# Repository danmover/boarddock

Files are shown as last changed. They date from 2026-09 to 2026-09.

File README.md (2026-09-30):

# BoardDock

**Dock any PCB. No screws. No supports.**

BoardDock turns a board's design files, or a few measurements, into 3D-printable holders that dock onto TS35 DIN rails with every plug reachable. It lays out the rails, routes and sizes the cables between the boards, checks the springs, and packs the parts onto print plates for your printer. It runs in the browser or as a desktop app for Windows, macOS and Linux. It is open source (MIT), and all sizes are in mm.

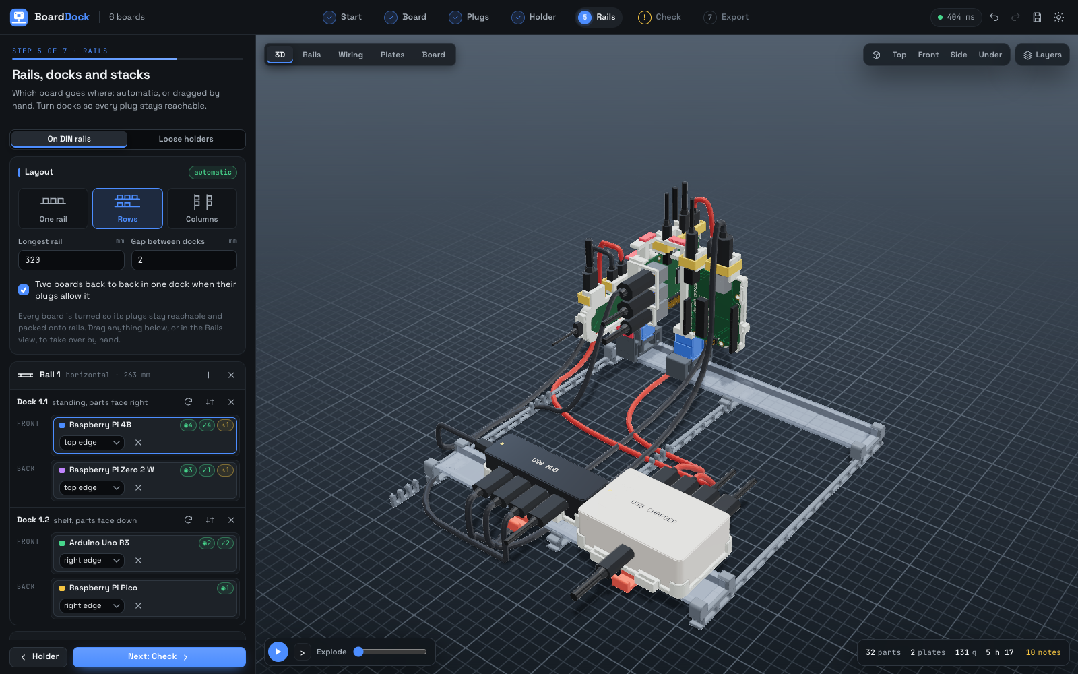
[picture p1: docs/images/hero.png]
A panel of boards on a DIN rail


## Status

One rack has been printed so far, from 3.0.0. The DIN rail clip worked. The rest showed what to fix: the release button's tunnel was too tight and the button broke, the snap pins broke, the socket latch let a holder pop out (the model has it slipping at about 10 N), and the tongue stoppers snapped.

3.1.0 redesigns those parts:
- boards are held by spring clips only, with fixed ledges and hairpin clips; there are no snap pins;
- the socket latch has a hook undercut 15°, so a pull draws it in;
- the release rod's tunnel has 0.8 mm of play and a gate the rod clicks under;
- two crush ribs on the tongue replace the stoppers;
- cable tags are held on by zip ties, and back-to-back holders by a pin and a U clip.

Nothing from 3.1 has been reprinted yet, so every number comes from models. Print the test-fit kit first, and read [the known limits](docs/limits.md).

## Download

- **Web app:** [danmover.github.io/boarddock](https://danmover.github.io/boarddock). Nothing is uploaded: it all runs in your browser.
- **Desktop app:** from [Releases](https://github.com/danmover/boarddock/releases). The builds are not code-signed yet, so your system asks you to confirm the first time.
- **From source:** `npm install`, then `npm run dev` (see [Development](#development)).

| System | File | First time |
|---|---|---|
| **Windows** | `BoardDock-3.1.1-win-x64-setup.exe` (installer) or `BoardDock-3.1.1-win-x64-portable.exe` (no install) | Choose **More info › Run anyway**. |
| **macOS** (Apple Silicon) | `BoardDock-3.1.1-mac-arm64.dmg` (open it and drag BoardDock into Applications), or `BoardDock-3.1.1-mac-arm64.zip` | Right-click the app and choose **Open**. |
| **Linux** | `BoardDock-3.1.1-linux-x86_64.AppImage` (`chmod +x` it, then run it) or `BoardDock-3.1.1-linux-amd64.deb` (`sudo apt install ./BoardDock-3.1.1-linux-amd64.deb`) | Nothing. |

The desktop app does two things the browser can't: it opens Cadence Allegro `.brd` boards (with KiCad 10 or newer installed, free from kicad.org), and **Open plate** hands a print plate to a slicer you have installed.

## Quick start

You need a 3D printer and a length of TS35 DIN rail (the 35 mm metal top-hat rail from electrical cabinets, cut with a hacksaw). Or pick **Loose holders** in the Rails step and skip the rail.

1. **Start.** Drop your board's files (several at once is fine), choose **Draw your own**, or **Open a saved rack**. Pick **Your printer** above them. Click a board in the library below to add it, or press **+ Board** (or **A**) from any step. The **cluster** preset adds a Pi cluster with its switch, powerboard and supplies.
2. **Board.** Check the outline, the parts and the hole wizard. Fix anything in the board editor.
3. **Plugs.** Press **Auto-connect** to cable the rack. Tap a port's *empty* or *cable* tag to say whether you'll plug something into it yourself.
4. **Holder.** Choose a frame or a tray, a preset, and **Firm** or **Gentle** spring clips.
5. **Rails.** Every board is already on a rail. Drag, turn, pair or stack boards if you like, and lock what you want to keep.
6. **Check.** Failing checks come first, each with **Show in 3D**. Press **Run dock FEA** for your material.
7. **Export.** First print the **Test-fit kit · print this first**: a rail shoe, a socket and a tongue key with its release rod (30 to 40 minutes). Clip the shoe on your rail, push the key in until it clicks, then press its button and lift. If the key is tight, raise **Tongue fit (looser +)** under Rails › **Fit and spacing** by 0.05 to 0.1 mm. Then print the plates in PETG with no supports, or slice them in the app. The shopping list, the **Bill of materials** and the **Checklist** say what to buy and have to hand.
8. **Build it**, following the play button or **Guide** in the 3D view. Then press **Mark the rack as built** in Export.

Every step has **Back** and **Next** at the foot of the sidebar. The full walk-through is in [docs/guide.md](docs/guide.md), and printing is in [docs/printing.md](docs/printing.md).

## What it does

- **Boards.** Read a board from its design files, draw one, or pick one from the library. The board editor has a toolbox of plugs and parts, a measure tool and a photo underlay, and the hole wizard sorts every hole into mounting holes, connector pegs, part leads and standoffs. [More](docs/guide.md#the-board-editor)
- **The dock.** A rail shoe clips onto the rail; press its red lever down to lift it off. A socket snaps into the shoe in any of four turns and takes two holders back to back. The holder's tongue has two crush ribs, and a latch with an undercut hook holds it. The button on top of the holder is the head of a release rod that opens the latch. [More](docs/design.md#the-dock)
- **Holders.** A light frame (or a full tray) round each board, held by spring clips only: tapered leaves, hairpins on short stretches of edge, and a fixed ledge where plugs take most of the edges. A mounting hole gets at most a locating pin. Only the ports you use get a plug cradle, cap, guard or zip-tie anchor; the rest keep a bare opening. [More](docs/design.md#the-holder)
- **Layout.** Auto-arrange places every board for plug access and short cables: back to back, standing up or lying flat, and stacked (a HAT bolted on standoffs, a board on a printed layer, or small boards in a column on their long edges). A board below the top of a column stands with its plugs to the side; one that can't gets a **Plug up the column** check. Lock what you have placed, and automatic changes leave it alone. [More](docs/guide.md#the-rails-step)
- **Boxes, power and cables.** USB hubs, chargers, network and PoE switches, powerboards and plug packs are boxes with ports. **Auto-connect** cables the rack, every cable is routed clear of the parts and sized to a length you can buy, a power budget checks every supply, and numbered cable tags go on with 2.5 mm zip ties. [More](docs/guide.md#cables-and-the-wiring-view)
- **Stands.** Printed table stands hold the rails, with no screws. To hang a rack on a wall, screw the rails up yourself and clip the docks on. [More](docs/design.md#table-stands)
- **Checks.** Hand sums for the clips, caps, tongue and stands, 2D FEA of the dock's springs, and a layer-by-layer printability check of every part. [More](docs/design.md#checks-fea-and-printability)
- **Printing.** Parts are packed onto as few plates as your printer's bed allows, already in print orientation, as STL or 3MF, or sliced to G-code in the app. [More](docs/printing.md)
- **Coming back later.** Add a board to a built rack, and Export lists only the new parts, cables and rails. [More](docs/guide.md#coming-back-to-add-a-board)

## Supported files

KiCad; Altium through STEP or fab files; Eagle (XML and old binary boards); Cadence Allegro `.brd` in the desktop app, through KiCad 10; board-viewer files; IDF; DXF; Gerber with drill and pick-and-place; IPC-2581, ODB++ and GenCAD. Or draw a board, start from a template, or pick one from the library. Details are in [docs/files.md](docs/files.md).

## Documentation

| Page | What is in it |
|---|---|
| [docs/guide.md](docs/guide.md) | Using BoardDock, step by step: the board editor, plugs, holders, rails, stacks, boxes and power, cables, the 3D view, and adding to a built rack |
| [docs/design.md](docs/design.md) | How the printed parts work: the dock, holders and clips, stacks, table stands, cable routing, and the checks and FEA |
| [docs/printing.md](docs/printing.md) | Printing and export: the test-fit kit, material, printers, print settings and G-code |
| [docs/files.md](docs/files.md) | Supported files, and how connectors are recognised |
| [docs/limits.md](docs/limits.md) | Honest limits: what is untested or approximate |
| [docs/development.md](docs/development.md) | Commands, the collision test, tile pictures and the project layout |
| [docs/din-clip-review.md](docs/din-clip-review.md) | The DIN rail clip review, and what the first print showed |
| [boards/README.md](boards/README.md) | Adding a board to the library |
| [parts/README.md](parts/README.md) | Teaching BoardDock a connector |
| [CONTRIBUTING.md](CONTRIBUTING.md) | Reporting a bad import, code conventions and releases |
| [TODO.md](TODO.md) | What is still to do, in order |

## Adding boards and parts

Two folders take contributions by pull request, each checked by one command:

- **`boards/`** adds a board to the library, under **Community boards**. Put its files in `boards/<slug>/` with a small `board.json` saying who made it and on what terms, then run `npm run boards -- <slug>`. Guide: [boards/README.md](boards/README.md).
- **`parts/`** teaches BoardDock a connector with one small JSON file: `names-….json` maps part numbers or footprint names to a type it has (this fixes a `NOT IDENTIFIED`), and `type-<id>.json` adds a new connector type. Then run `npm run parts`. Guide: [parts/README.md](parts/README.md).

[CONTRIBUTING.md](CONTRIBUTING.md) has the rest. A maintainer can also add the `boards` or `parts` label to a pull request, and an optional Claude job does the work on its branch ([docs/files.md](docs/files.md#adding-boards-and-parts) has the details).

## Development

```bash
npm install
npm run dev          # web app at http://localhost:5173
npm test             # vitest: importers, holders, panels, dock FEA, and a quick collision check
npm run typecheck
npm run collisions   # the whole collision test (144 racks, a minute or two)
npm run boards       # community boards: read boards/<slug>/, update public/boards/
npm run parts        # contributed parts: check parts/*.json, write src/model/parts.json
npm run build        # production web build in dist/
npm run desktop      # Electron app from the build
npm run dist         # installers for the current OS in release/
```

The collision test, the tile pictures and the project layout are in [docs/development.md](docs/development.md). Code conventions and releases are in [CONTRIBUTING.md](CONTRIBUTING.md), and what is still to do is in [TODO.md](TODO.md).

## Licence

MIT for BoardDock itself; see [LICENSE](LICENSE). Third-party components and their licences are listed in [NOTICE](NOTICE).

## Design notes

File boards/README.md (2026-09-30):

# Community boards

Boards added here appear in BoardDock's library (Start page and **Add a board**, under **Community boards**, after the built-in ones), so anyone can add yours to a rack without drawing it.

## What to upload

One folder per board, `boards/<slug>/`. The slug is the board's id: lower case, digits and dashes (`acme-sensor-v2`). It holds:

1. **Your board's files.** One is enough; BoardDock reads the one that tells it most.

   | You have | Upload |
   |---|---|
   | KiCad | the `.kicad_pcb` (best: outline, holes, part sizes, pin names) |
   | Allegro / OrCAD | open it in KiCad 10 (File > Import > Non-KiCad Board File), save, and upload the `.kicad_pcb` |
   | Altium, PADS, Xpedition, others | IPC-2581 `.xml`, or ODB++ (`.tgz` or the job folder), or GenCAD `.cad`, or IDF `.emn` + `.emp`, or Gerbers (outline layer) + NC drill + pick and place |
   | Eagle / Fusion | the `.brd` |
   | only a drawing | a `.dxf` of the outline (holes from round cut-outs) |

   A STEP file works in the app but not in `npm run boards` (it needs a browser): add one of the above too.
2. **`board.json`**, a few lines about the board (below).

Only upload what you may share. Say in `board.json` where it comes from and under what terms.

## board.json

```json
{
  "name": "Sensor board with JTAG (worked example)",
  "maker": "BoardDock contributors",
  "url": "https://github.com/danmover/boarddock/tree/main/examples",
  "license": "MIT",
  "source": "A made-up board that ships with BoardDock."
}
```

`name`, `maker`, `url`, `license` and `source` (a note on where the files came from) are shown with the board. Give `license` or `source`, and `maker` or `url`. Everything else is a hint, only for when the report (below) says something is wrong:

```json
{
  "parts":      { "J3": { "type": "usb_c" }, "J7": { "type": "custom", "note": "Wurth 61300811121" } },
  "footprints": { "USB_C_Receptacle": "usb_c" },
  "holes":      { "use": [[3.5, 3.5], [66.5, 3.5], [10, 40, 3.2]], "ignore": [[35, 20]] }
}
```

| Hint | Meaning |
|---|---|
| `parts.<ref>.type` | what part `<ref>` really is: a connector id (`npm run boards -- --types` lists them), `none` (not a connector), or `custom` (a plug the library has no entry for: put its part number in `note`) |
| `parts.<ref>.angle`, `.size`, `.hide` | which way its plug comes out (0 right, 90 top, 180 left, -90 bottom; found from the nearest edge if left out), its `[width, depth, height]` in mm, or leave it out |
| `footprints.<regex>` | the same connector id for every part whose footprint name matches |
| `holes.use` | exactly these are the mounting holes, as `[x, y]` or `[x, y, diameter]` (one the file lacks is added); positions are the ones the report prints, in mm from the board's lower left |
| `holes.ignore` | holes to leave alone |
| `thickness`, `notes`, `files`, `copper`, `listed` | board thickness in mm, extra notes for the app, which files to read, keep the copper tracks (bigger file), `false` to keep it out of the app |

## Turn the files into a board

```bash
npm ci                          # once
npm run boards -- <slug>        # read boards/<slug>/, print the report, update public/boards/
npm run boards                  # the same for every folder
```

The report is what you check, for the worked example, `boards/example-sensor-jtag/`:

```
boards/example-sensor-jtag: Sensor board with JTAG (worked example) (KiCad: sensor-jtag.kicad_pcb)
  outline     70 x 45 mm, 4 corners, 0 cut-outs, 1.6 mm thick
  holes       4 found, 4 to mount by
    (3.50, 41.50)    d3.20  mount    Ø3.2 near a corner: a mounting hole
    ...
  connectors  3
    J1       usb_micro_b  edge -180° by name        USB_Micro-B_Molex-105017-0001
    J2       jtag20       top       by name        IDC-Header_2x10_P2.54mm_Vertical
    J3       header       top       by name        PinHeader_1x04_P2.54mm_Vertical
  result      ok
```

Does the outline match your board? Are the mounting holes the right ones, and no others? Is every plug the right kind (a `NOT IDENTIFIED` one is a **Custom** connector: fix it with a `parts` hint)? Fix, run again, until it says `ok` with no `WARNING` lines. The script exits with an error (and writes nothing) only when a board can't be read or `board.json` is wrong. `--dry` only reports, `--strict` also fails on warnings, `--check` fails when `public/boards/` is out of date.

Then `npx vitest run tests/boards.test.ts`, commit `boards/<slug>/` and `public/boards/`, and open a pull request. Two pull requests adding boards can conflict in `public/boards/index.json`: take either side and run `npm run boards` again.

## Don't want to run anything?

Open the pull request with just the folder (files and `board.json`, or the files alone). CI (`.github/workflows/boards.yml`) runs the script on it and shows the report. If the repository has an `ANTHROPIC_API_KEY` secret, a maintainer adds the **`boards`** label and an AI job follows [`AGENTS.md`](AGENTS.md) on the PR branch: it writes the hints, regenerates `public/boards/` and commits. It only runs for branches of this repository, only when that label is added (not on every push), and does nothing in forks without the secret. For a PR from a fork, a maintainer can push its branch here first, or run the steps of `AGENTS.md` locally.

## Pictures

A board without a picture shows a plain top view, so this is optional. Maintainers can render 3D pictures of all boards that lack one (needs the dev server and Playwright, see the top of `scripts/render-tiles.mjs`): `node scripts/render-tiles.mjs http://localhost:5173/ community`, then `npm run boards`.

## How it fits together

`boards/<slug>/` (source of truth) -> `npm run boards` (`scripts/boards.mjs` and `scripts/boards-lib.ts`, using the app's own importers, so what the report says is what the app would read) -> `public/boards/index.json` (one row per board) and `public/boards/<slug>.json` (the board). The app fetches `index.json` only when the library opens and a board's file only when you add it: none of it is in the main JavaScript.

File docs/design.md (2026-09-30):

# How the printed parts work

What BoardDock prints, why it is shaped that way, and how it is checked. For using the app, see [guide.md](guide.md); for printing, [printing.md](printing.md); for what is untested, [limits.md](limits.md). Back to the [README](../README.md).

Contents:
- [The dock](#the-dock)
- [The holder](#the-holder)
- [How the board is held](#how-the-board-is-held)
- [Plug cradles and caps](#plug-cradles-and-caps)
- [Stacks and columns](#stacks-and-columns)
- [Table stands](#table-stands)
- [Cable routing](#cable-routing)
- [Loose-holder joints](#loose-holder-joints)
- [Checks, FEA and printability](#checks-fea-and-printability)

Every figure here is from the model: exact geometry, hand sums, and a 2D FEA with a textbook modulus. One rack was printed from 3.0.0; nothing from 3.1.0 has been printed yet.

## The dock

Every board sits in a holder that plugs into a dock on the rail. This is the screwless "DIN hub" design, built into the generator:

| Part | What it does | Prints |
|---|---|---|
| **Rail shoe** (graphite, red lever) | Clips onto a TS35 rail. Its jaw wraps round the rail flange and hangs from a hinge leaf directly **above** the lip, so pulling the dock straight up can't pry it open. A sprung **rail grip** in the rail's channel presses the rail's wall and holds the shoe against its fixed hook, so a dock stays where you put it: about 6 N pushes one along the rail. The release lever is printed in place on a pin, with a bead round the pin's middle so it can't slide off; a built-in stop protects the hinge. The lever goes on whichever side of the rail has more room; you can flip it per dock. | on its end face, lever and all |
| **Socket** (blue) | Snaps into the shoe in any of four 90° turns and takes two holders back to back. It has two print-in-place latches: long tapered springs whose hooks are undercut 15°, so pulling on a holder draws the hook in rather than out. | on its end face |
| **Holder** | The frame (or tray) round your board, with a tongue on its dock edge and a spine that carries the release rod. | flat on its back |
| **Release rod** (red) | Its head is the **button on the holder's top edge**: a keycap with a thumb dish and chevrons that point the way it moves. Press it and the rod's 45° foot wedges the latch open; the latch spring returns it. The grip bar under your fingers has a matching finger scoop. | flat |

**The tongue** is 14 × 4.5 mm at the socket mouth and a slip fit: 0.2 mm a side, 0.14 to 0.2 mm front and back, and 0.65 mm of lift on purpose, for the undercut hook. Two **crush ribs** on its front corner faces stand 0.4 mm proud and are pressed 0.12 mm. They are meant to deform once, on the first push in (about 24 N, once; the crush stress is assumed, not measured), so the holder is then snug and centred. They replace 3.0.0's tongue stoppers, which snapped.

**The latch** reaches 1.4 mm into a groove across the tongue's front face, and its holding face slopes 15°. A pull on the holder tips the beam, and the undercut draws the nose back in: a 20 N pull moves it 0.4 mm of its 1.4 mm, and it slips only at about 69 N (friction not counted). It takes about 3.9 N to push a holder in and 2.5 N on the button, at 0.85% strain. There is no stop post: the button's stroke bounds the arm.

**The rod's tunnel** has 0.8 mm of play round the rod (0.4 mm each side), a 45° lead-in funnel and chamfers, and the rod's neck under the button is solid and filleted, so it slides in without forcing (3.0.0's tunnel was tight and the button broke). Push the rod in until it clicks: two barbed fingers spring out under a gate at the top of the tunnel (0.3 mm each side), once, so it can't slide back out.

**Using it:**
1. Hook the shoe under the rail and press it down until it clicks. To move it along the rail, push it firmly.
2. Press the socket in, in whichever turn you want.
3. Push the holder straight down into the socket until the latch clicks.
4. **To take a board out:** put your thumb on the red button and two fingers under the grip bar, squeeze, and lift.
5. **To take a dock off the rail:** lift the boards out, press the ridged red pad beside the socket down about 5 mm, and lift the dock off.

Where the button goes (**Centred**, **Beside the board** or **Automatic**) is set in the Holder step; see [guide.md](guide.md#the-holder-step).

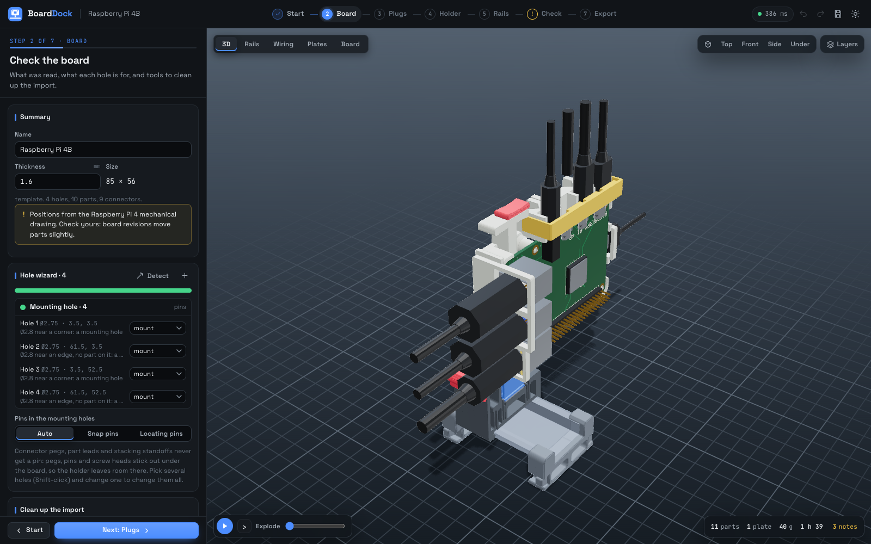
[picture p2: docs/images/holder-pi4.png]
A Raspberry Pi 4 docked


*(This picture predates 3.1.0: its holder still has pins in the mounting holes.)*

### Lying flat

A board can also lie flat on its dock, top face up (out of the wall), on the same shoe and socket:
- Its holder has a tab, the **ear**, on one edge, flush with its underside, so the holder prints base-down like any other. The ear goes on an edge where it keeps clear of the plugs, as near the middle as it can.
- The tongue that plugs into the socket is a small **dock key** of its own, with a dovetail on top. It prints on its side, slides into a dovetail groove under the ear from the ear's tip, and the release rod locks it in: the rod goes in from the top, through the ear and the key, down to the latch, and clicks in under a ledge at the top of the ear, so neither can slide out.
- The release button sits on top of the ear, clear of the board. Put your thumb on the button and your fingers under the ear, then squeeze and lift.
- Two boards can lie back to back in one socket, ears together. A J-Link or serial adapter can stand in the other half of a flat board's socket. The shoe's lever goes on the side away from a flat board where it can.

Check lists the tongue's stress under a 20 N press on the far side of a flat holder (the same load case as a push on a standing holder's far edge). No flat holder has been printed yet.

## The holder

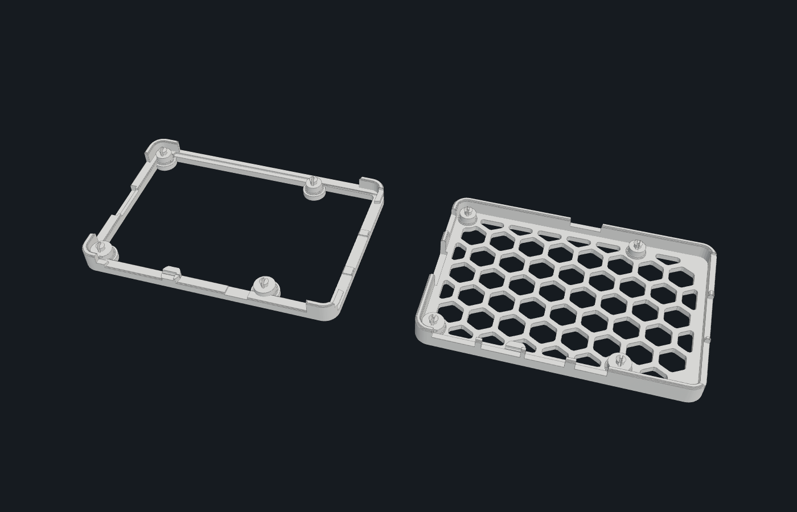
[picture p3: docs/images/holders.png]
Frame and tray holders


*(This picture predates 3.1.0: it shows split snap pins, which are gone, and no spring clips.)*

**Frame** (the default) combines the lean spine-and-rib carrier of the original DIN hub with the tray's protection:
- a rim runs round the board, under its edge and out to the holder's outline;
- short corner guards locate the board, and **edge seats** carry it wherever no pin is close;
- ribs, laid out as a minimum spanning tree, tie every pin to the rim or to the dock's spine;
- plug cradles, caps, guards, tie anchors, spring clips and the label each bring only the bit of wall they need.

**Tray** is the full base with a hex pattern and a wall all round: stiffer, and more plastic. A frame is open underneath (push the board out from below); a tray has finger notches.

Plastic in a loose holder with its clips, but no cradles, caps, guards, anchors or label (PETG, default settings):

| Board | Frame | Tray |
|---|---|---|
| Raspberry Pi 4 | 4.5 cm³ | 7.6 cm³ |
| Arduino Uno | 4.3 cm³ | 6.9 cm³ |
| Perfboard 50 × 70 | 3.8 cm³ | 6.4 cm³ |
| 60 × 40 blank | 4.3 cm³ | 5.5 cm³ |

So a frame takes about 20 to 40% less plastic than a tray. Cradles, caps and the dock tongue come on top and are the same for both styles.

## How the board is held

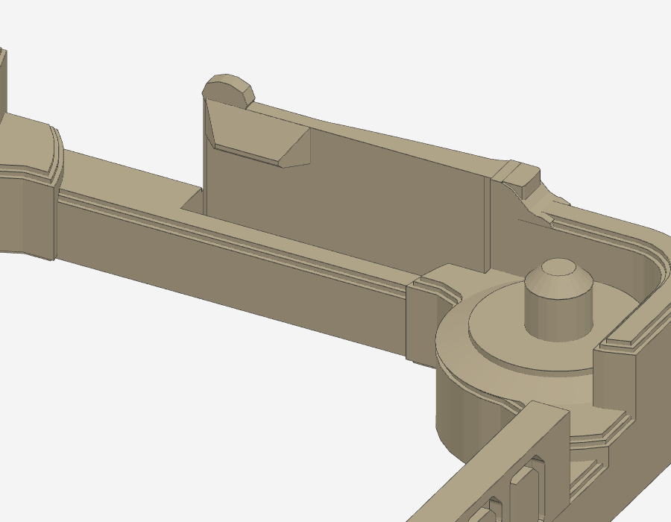
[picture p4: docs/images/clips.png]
A spring clip seen from the board: the tapered leaf, its lip, the pull ear, and the anchor it grows from


*(A straight tapered leaf beside a plain locating pin. Hairpins and fixed ledges are not in this picture.)*

Every board is held by **spring clips** on its edges. Each clip is a leaf standing straight up from the print bed at the board's edge, as tall as the holder there. It grows from a short block of wall (its anchor) along its whole height, with a rounded root, and is cut free of everything else by 0.6 mm slits, so it bends sideways, within the print layers: the strong way for a printed part.

- **Straight leaves taper** (a Pi 4's from 1.1 mm at the root to 0.7 mm at the tip, on Firm), so the bending strain spreads along the leaf instead of piling up at the root.
- **Hairpins.** Where a stretch of edge is short, the leaf folds back on itself, so its springy length is twice the stretch. For each stretch the generator takes a straight leaf when that reaches the push wanted inside the strain limit, and otherwise a hairpin. The tests hold 14 and 16 mm clips as straight leaves and 8 and 10 mm ones as hairpins, and a hairpin's peak strain under 0.85 times a straight leaf's at the same push.
- **Fixed ledges.** Where plugs take most of the edges, a fixed ledge goes on one side: the board slides under it, then the clips opposite click over it.
- **The lip** at a clip's tip has a 35° entry ramp, so the board's edge pushes the clip aside; a flat ledge over the board's edge that holds it down; and a small ear on top to hook with a fingernail.
- **Nothing loads a clip once the board is in.** The ledge sits on the first layer line above the board (0.15 to 0.35 mm clear of it), and the leaf stands 0.1 mm further out than the guards, so the board never leans on it. A clip strains only while the board goes past, so it can't creep or take a set.
- **Taking a board out:** pull one clip's ear back with a fingernail and lift that side; the other side then slides out from under its clip or ledge.
- **Printing:** every leaf stands on the bed, so the only overhang in a clip is its ledge, printed flat, 0.9 to 1.3 mm out from the leaf and deeper with the catch (Pico 0.9 mm, Pi Zero and Uno 0.95 mm, Pi 4 1.0 mm, a 250 mm board 1.3 mm). The Check line **Clips print** measures it.

**Sized for the board.** Leaf length follows the board's size: 10 mm for a small board up to 16 mm for the biggest, and down to 8 mm where a stretch of free edge is short. The catch is 0.5 to 1.0 mm deep, deeper for a heavier board. The push wanted from each clip is:
- **Firm:** 2.6 N plus 0.02 N for each gram the board weighs, up to 4.2 N;
- **Gentle:** about 46% of that (the ratio of 1.6 N to 3.5 N);
- never under 1.2 N, and never more than 30 N shared among all the clips, so a big board gets more, softer clips.

Each clip is then the stiffest leaf that gives that push while keeping its strain at full deflection (the catch plus the board's play) inside half the material's strain limit: 1.0% in PETG, against its 2%. That leaves a fatigue margin for many presses. If even the thinnest leaf would be over, the catch gets shallower. The library's boards measure 0.71 to 1.00% going in (a Pi 4 on Firm: 1.00%). A taller holder (a docked board stands higher) gets a thinner leaf for the same feel.

**Where they go.** A board resting on its seats can only tip about a line along their edge, so every such way needs a clip well back from it: two clips on opposite edges do that, or three round the board. More go along the outline so no stretch longer than about 130 mm is without one, and together they hold 1.5 times what a 9 g shake asks (4 N at least). A clip takes a clear stretch of edge, away from plugs, the dock, the label and parts at the edge. Round and L-shaped boards get them too. If clips can't hold a board, Check says **Nothing clips this board in** and what to change.

What some boards get (loose holder, PETG, Firm unless stated; from the Check lines **Spring clips (n)** and **Press-in force**):

| Board | Clips | Force to press the board in |
|---|---|---|
| Pico, Nano, Uno | two 10 mm hairpins | 3 to 4 N |
| Pi Zero | two 10 mm hairpins and a 6 mm fixed ledge | 3 to 4 N |
| Pi 4 | two 12 mm tapered leaves (1.1 to 0.7 mm on Firm, 0.8 to 0.7 mm on Gentle) | about 7 N (9 N docked) |
| 250 × 150 mm board | ten 16 mm leaves | about 32 N on Firm, 21 N on Gentle |

**Anti-rattle springs** are thinner leaves, 0.8 mm tapering to 0.6 mm, 14 or 16 mm long, whose lip has a 45° face resting on the board's top edge. Pushed 0.2 mm aside once the board is in, they press it across against the guards opposite and down onto its seats with 0.11 to 0.18 N each, at 0.08 to 0.11% strain at rest (up to 0.19% with the board 0.15 mm bigger; the Check line **Grip at rest**). That is under the 0.2% resting rule, so creep only slowly eases the push. One goes across the clips and one along them, where the edges have room. Some boards get none: the Nano has no free edge for one.

**No snap pins.** Earlier versions could also hold a board with split, barbed pins through its mounting holes. On the first real print they broke straight away, so they are gone. A mounting hole gets at most a plain locating pin that grips nothing (Board step › Hole wizard › **Pins in the mounting holes**: **Locating pins** or **Ignore**), and projects that asked for pins get clips.

The Check step lists, for each board, the clips' strain going in and its margin under the material's limit, the strain at rest, the force to press the board in, and that the clips print with no supports. The clip forces are beam sums with a textbook modulus, checked against 2D FEA in the test suite: a print will tell the real feel and the click.

## Plug cradles and caps

Only ports in use get a cradle, cap, guard or zip-tie anchor; every other port keeps just its opening in the wall (see [guide.md](guide.md#plugs-ports-and-protection) for when a port counts as in use).

- A **cradle** carries the mating plug's body outside the wall, so a knocked cable loads the holder, not the solder joints. Neighbouring cradles on one edge merge.
- A snap-on **cap** locks the plug into its cradle. It stands on tapered legs with rounded roots: at most 0.9% strain (0.70% in a Pi 4's run), down from 1.2% before 3.1.0. Check lists them as **Cap legs**.
- A **guard** collar surrounds an opening, and a **zip-tie anchor** sits on the side the cable is pulled to.

## Stacks and columns

How to stack boards is in [guide.md](guide.md#stacks-and-columns). How the stacks are built:

- **Bolted on standoffs.** The top board is lined up on the holes the two boards share (the Pi's 58 × 49 mm pattern, for example). BoardDock picks the shortest standard standoff (11, 12, 15, 16, 18, 20, 25, 30, 35 or 40 mm) that clears the tallest part under the top board, plus the parts and leads on its underside and 1 mm. A HAT's 11 mm is the least; a whole Pi 4 on a Pi 4 gets 20 mm, over its 16 mm USB jacks. The shared holes of the bottom board become stacking standoffs in the hole wizard: no pins there, and room underneath.
- **Printed layer.** A separate board gets its own light holder that presses onto four corner towers on the holder below, with press-fit pegs. The towers on a docked holder stay back from the dock face.
- **Columns.** Small boards, up to about 105 × 60 mm, stand on their long edges, the longest side along the rail. Each holder stands on two pegs on the holder below and rests on a landing on that holder's far wall. A peg has a 45° flare at its root and a lead-in tip; its hole has a matching 45° countersink, a gabled roof, and two crush ribs at its sides that centre the peg. They print lying on their side with no supports. The clips between two holders sit in the gap beside the landing, with room to flex (5.2 mm of room against 0.85 mm of travel).
- **One rod for the column.** The bottom holder plugs into the dock. The top one's release rod is longer and runs down through every holder to the dock's latch, so one press at the top frees the whole column from the rail. Check fails a rod longer than your printer's bed.
- **The tongue's limit.** The rack holds a column to what the dock's tongue can bear: in PETG, a J-Link and an adapter (about 85 mm) fit in one column, and two J-Links do not.
- **Plugs to the side.** Every board in a column, the bottom one too, stands on the long edge that keeps its plugs to the side. Below the top, a plug pointing up the column would put its plug and cradle where the holder above stands; a board that can't avoid it gets a **Plug up the column** line in Check.
- **A board nothing can clip in.** A small board whose ends are taken by its plugs, in a column where the dock and landing take its long edges, slides into its holder from the open end under two lips instead, and the holder above keeps it in.

## Table stands

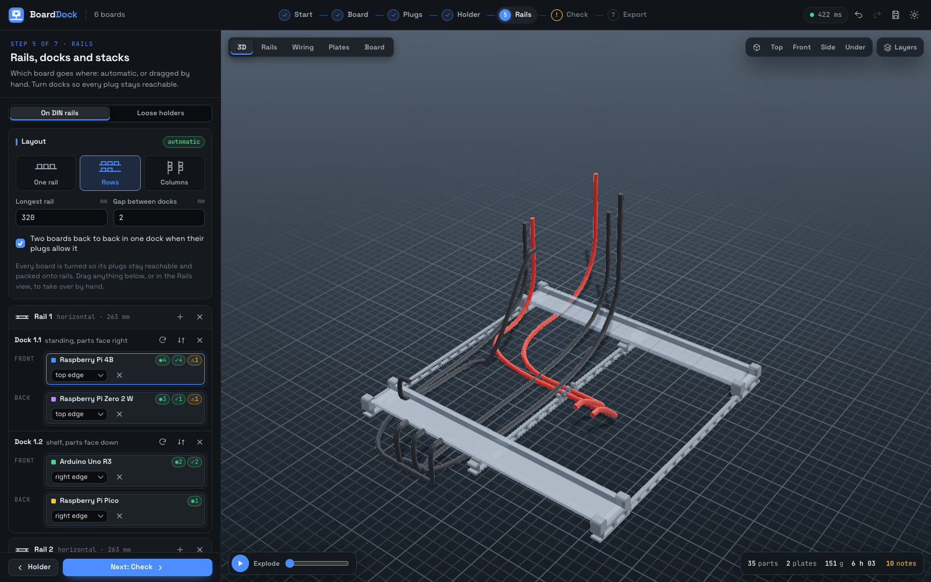
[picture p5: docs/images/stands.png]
Table stands under two rails


There is no wall mount: BoardDock prints no screw holes and uses no screws. The rails are ordinary TS35 DIN rails, which come with slots for screws, so to hang a rack on a wall or in a cabinet, screw the rails up yourself and clip the docks on as you would on the stands.

The rails stand on printed sleepers (Rails step, **Table stands**, on by default):
- A sleeper crosses the rails at each end, and at least every 200 mm between.
- Each **rail end pushes 7 mm into an end block** with a TS35-shaped pocket. It caps the rail's lips and is a 0.3 mm slip fit (crush ribs there would flatten the first time and leave it loose).
- **Saddles** carry the rails in between. Their low cheeks stay under the dock shoes' jaws, so a saddle can sit under a dock.
- **Spacer bars** join the blocks. They slide in along the rail through dovetails, and set the rail spacing.
- The rails stand 10 mm off the table, so cables can run under them.

The pieces scale with the rack: more rails give more blocks and spacers, and longer rails give more sleepers. In the automatic layout every rail is cut to the same length, so the sleepers run straight across. Every piece is a profile printed on its end: no supports, and every load lies in the plane of the layers. An end block takes 3.6 cm³, a saddle 2.2 cm³ and a 150 mm spacer 2.5 cm³.

The Check step reports two hand calculations:
- the rail's sag between sleepers under a 20 N press, treating the rail as a steel beam;
- the stress in an end block's lip caps when you lift a rail end with 20 N: about 6 MPa, against PETG's yield of 45 MPa.

A lone rail gets short feet on each end block, for a wider footprint. **Tipping**: when the holders and boards reach more than 1.5 times as high above the table as the stands are wide at their narrowest, Check says so. That is a rule of thumb, not a calculation: a lone Pi on a short rail gets a note to hold the rack while plugging in; a big board standing on a short rail gets a warning, with ways to steady it (lay it flat, add a rail, space the rails wider).

## Cable routing

The panel routes every cable:
1. Out of its plug and clear of its own board. A plug pointing up out of a board standing on edge steps sideways off the board before going down; a plug pointing sideways drops, reaches further out first, or slopes straight into a lane it faces. A drop that would land on a sleeper steps along the rail first.
2. Down to a **street** between the rails (or beside the outer ones), where each cable gets its own lane. Lanes are ordered so as few cables cross as possible.
3. Along the street and back up to the other plug the same way.

Every combination of these is checked against the bounding boxes of every holder, board, plug, dock, rail and stand piece, and the shortest route that hits nothing wins. If every route touches something, the cable is marked red in the 3D view and Check says what it runs into.

**Settling.** Then all the cables settle together, the way real ones do once they are plugged in. Each is a chain of beads:
- where two cross, one lies over the other; where they run together, they lie side by side;
- nothing goes through a holder, dock, plug or ribbon;
- each cable keeps its length, with a few per cent of slack in its free stretch;
- it has weight: a free span sags, never below the streets, and lies in the stands' combs where its street crosses them;
- it has stiffness, more the thicker it is: it runs straight out of each plug for about a bend's length, and bends nowhere tighter than about three of its own diameters;
- pushed out of anything, it goes back out on the side it was laid, so it never pops through a board;
- last, the ripples are smoothed out wherever that touches nothing.

Ribbons stay where they were laid and the rest settle round them. Check says how many places the planned routes met, warns about any pair still pressing on each other, and names any cable squeezed into a tighter bend than a cable likes.

Cables that cross under the rails are spread a cable width apart, each pinned to its own line; lanes stay between rails and stand blocks; a cable routed later keeps off the ways of earlier ones. A debug ribbon or jumper never blocks taking a holder off: over another board's dock it rises clear of that holder's lift-off and its release lever, or goes round the end of the dock. On the 144 test racks the collision check went from 458 to about 35 mm³ in all.

**Combs.** On table stands the streets run under the rails' level. Wherever a street crosses a sleeper, the spacer there carries a cable comb: one round-bottomed slot per cable, sized for it, with snap lips at the mouth.

**Lengths.** Every cable's length is measured along its route and rounded up to a standard length to buy (10% slack). Auto-arrange keeps cabled boards next to each other and puts each hub or charger in the middle of the boards it feeds (on a rack of six Pis and two chargers that took the longest cable from 66 to 51 cm, and the cable to buy from 4.3 to 3.5 m).

### Cable tags

Each cable gets two numbered tags. A tag is an open half-ring saddle that drops onto the cable, with a flag carrying the number raised so a second colour or a marker picks it out. A 2.5 mm zip tie goes round the cable and a groove in the saddle, so nothing on the tag flexes. (A ring that snaps round a stiff cable would have to stretch 8 to 30%.) Tags are printed flat and sized for typical cables (USB 4 mm, Ethernet 6 mm, HDMI 7 mm). In 3D they sit a hand-width from each plug.

## Loose-holder joints

How to use loose holders is in [guide.md](guide.md#loose-holders). The joints:

- **Side by side:** printed link bars join neighbouring holders.
- **Back to back:** a rivet. A rigid pin goes through both bases, with a head on one side and a neck beyond the other, and a U clip with two tapered arms 11 mm long slides onto the neck from the side. It bends within its layers (it prints flat), at 0.84% strain. The old split rivet reached 15%.
- **Stacked:** corner towers with press-fit pegs, as in a printed layer.
- **The pull-tab DIN clip** holds a holder flat on a rail. It has a long shallow jaw ramp, an even 0.8 mm leaf 17 mm long and a gusseted stop, and the holder's hooks on the plate are tapered beams. A rail grip like the shoe's presses the rail's top wall and holds the clip down on the top flange: a 6.4 N preload on a 14 mm clip, about 4 N to push it along. A box on the clip stands 2.3 mm up in its holder, clear of the clip's hooks. A plate standing off a holder's edge prints standing, so the tops of its two slots are 14.4 mm bridges (see [limits.md](limits.md)).
- **The stand socket** takes a round, square, hex or D-shaped post, or is a 1/4"-20 tripod nut trap.

## Checks, FEA and printability

The Check step lists every test, failing ones first (**Failing**, then **To look at**), each with **Show in 3D**. Tap the passing, to-look-at and failing tiles to see only those. An item to look at gets a verdict: **OK to print** when it is about using the rack (holding a holder while you plug in, cables touching, PLA's brittleness) and printing now wastes nothing, or **worth a look** when it may change what you print or how the rack is laid out. Where a fix is one click, the item has a button. Repeated lines fold into one row with a count. The boards' template reminders ("measure yours") are folded away at the bottom: tick each off with **Done** once you have.

What is checked, and how:
- **2D FEA in the app:** the dock's springs (the socket latch, the rail shoe's hinge and its rail grip) and the flat DIN clip, for your material. Press **Run dock FEA**.
- **Beam sums, checked against FEA in the test suite:** the spring clips, the plug caps and the rivets.
- **Hand calculations:** the stands, the tongue's stress, and tipping.
- **Mains near low-voltage** warns when a mains outlet, inlet, lead or plug pack comes within 10 mm of a low-voltage board or cable, on a rack on rails. The 3D view shades the same zones. It is a layout check: BoardDock can't check your powerboard, its lead, earth or the wall socket.

### Printability, layer by layer

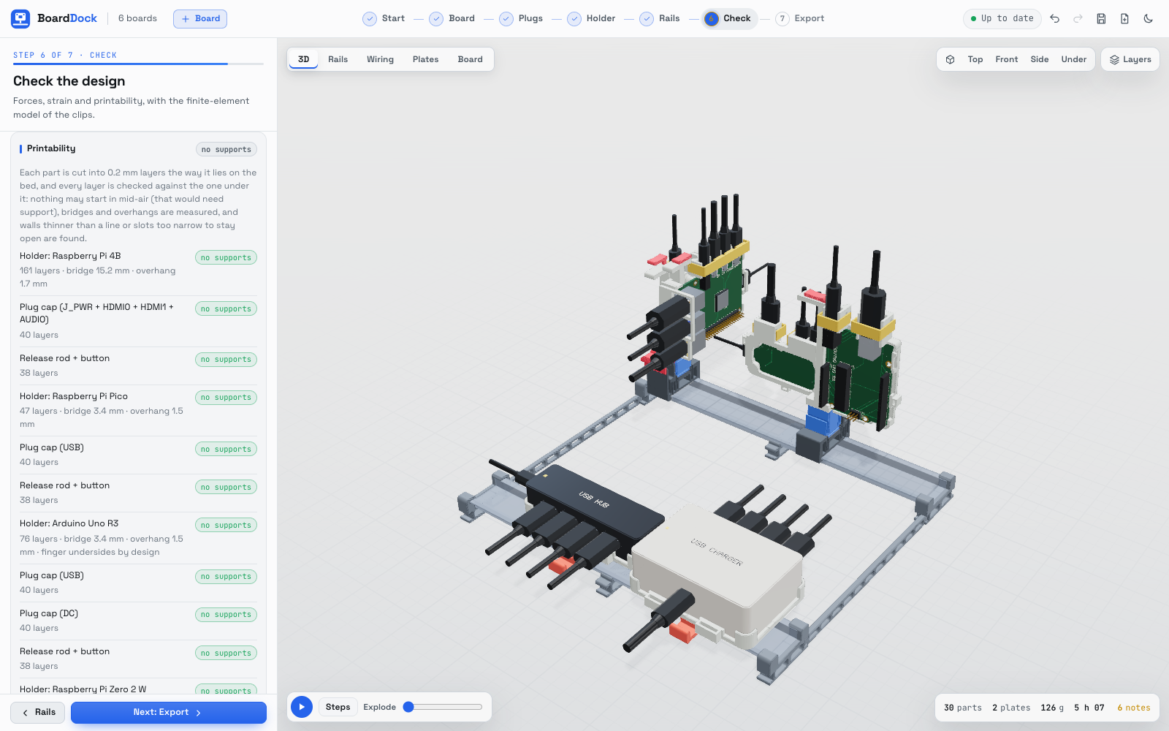
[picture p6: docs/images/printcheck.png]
Printability, sliced


*(This picture predates 3.1.0: its 15.2 mm bridge came from wall snap fingers that are gone.)*

The Check step slices every distinct part into 0.2 mm layers in the pose it prints in and compares each layer with the one under it, the way a slicer sees it (in a background worker, once per part shape). Measured from each part's own bottom:
- **In mid-air:** anything with nothing under it would need support: the part says **needs support**. A fleck thinner than one line (or a single layer under 0.5 mm²) is only a *speck*, which slicers leave out, and is noted, not failed.
- **Overhangs and bridges:** how far each layer reaches past the one below, measured inside the layer from the wall that holds it. Held from opposite sides it is a bridge; from one side, an overhang. Overhangs: fine to 2 mm, a warning to 3 mm (or to 2 mm over more than 20 mm²), then **needs support**. Bridges: fine to 12 mm, a warning to 25 mm, then failed.
- **Sloped roofs:** a roof flatter than 45° is followed layer after layer: a warning once it runs out more than 3 mm, a failure past 10 mm.
- **A tiny foot:** a part taller than 5 mm whose first layer is under a tenth of its biggest one is failed (it would be knocked over).
- **Thin walls:** anything under 0.4 mm wide. In BoardDock parts they are only details of the engraved label and the button's chevrons.
- **Narrow gaps:** a slot under 0.3 mm prints closed. That matters only where something moves, and the check finds it by the gap's width, so a 0.09 mm print-in-place gap is flagged. The shoe's lever has 0.35 mm round its pin, and the socket's latch nose 0.45 mm round it in its window.

As measured before 3.1.0, across the library (209 distinct parts: every template in each pose, the stacks and pairs, the rack parts and the test-fit kit), nothing was in mid-air, the longest one-sided overhang was 1.6 mm and the longest bridge 9 mm, except the DIN plate's slot tops (14.4 mm bridges, a warning). That survey has not been redone since 3.1.0's hairpins, fixed ledges, undercut latch, crush ribs and rod gate; the clip ledges now reach 1.3 mm.

An audit of the first parts with this check found and fixed: wall snap fingers that were 8 to 14 mm one-sided overhangs (now the spring clips); flat roofs over plug openings and stand sockets (now 45° gables, so no flat roof is over 6 mm); a 14.8 mm bridge in a tray's wall; probe and adapter slot lips that were 1.9 mm flat ledges (now 0.8 mm, then 45°); rivets that printed 1.3 mm below the bed; and thin slivers under overhanging plugs.

### Dock FEA

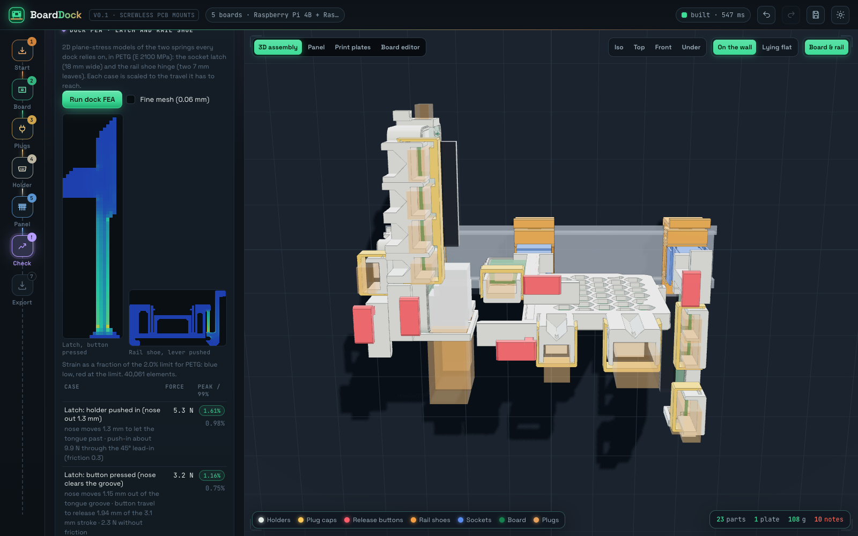
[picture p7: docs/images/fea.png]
Dock FEA


*(This picture predates 3.1.0 and shows the old latch figures; the table below is current.)*

The FEA is 2D plane stress:
- **Elements:** incompatible-mode quads, validated against beam theory in the test suite.
- **Mesh:** square pixels, 0.1 mm (or 0.06 mm with the fine option).
- **Scaling:** each case is solved for a unit load and scaled to the travel it has to reach.

PETG results (E = 2100 MPa, strain limit 2%), as the test suite holds them:

| Case | Force | Peak strain | 99% of the part below |
|---|---|---|---|
| Latch: holder pushed in (nose moves out 1.4 mm) | about 3.9 N | 0.74% | – |
| Latch: button pressed right home | 2.5 N | 0.85% | 0.74% |
| Latch: a 20 N pull on the holder | holds: the nose moves 0.4 mm of its 1.4 mm, and slips only at about 69 N (friction not counted) | 1.1% | – |
| Rail shoe: lever pad pressed down (jaw opens 1.7 mm for about 5 mm of pad travel) | 2.4 N | 1.7% | 0.55% |
| Rail shoe: pressed onto the rail | 4.3 N | 1.7 to 1.9% | 0.5% |
| Rail shoe: pulled straight up off the rail | holds to about 130 N pulled centred, 87 N on one hook | 1.7 to 2.3% at 100 N | 0.4% |
| Rail shoe: rail grip, its pad pressed 0.35 mm by the rail's wall | 9.6 N preload (5.5 to 14 N over tolerance), about 6 N to slide a dock along | 1.1% | 0.6% |

### What the analysis changed

Compared with the original DIN hub (the details are in [din-clip-review.md](din-clip-review.md)):
- **Pull-off.** The original jaw hung from a hinge outboard of its lip, so pulling the dock off the rail pried it open, and in the model only friction held it (without friction it let go at about 14 N). The jaw now wraps the flange edge with its hinge leaf directly above the lip, so a pull runs straight down the leaf. The leaf is a uniform 0.9 mm (two 0.45 mm lines).
- **Press-down lever.** A lever printed in place on a pin releases the jaw: about 2.4 N over 5 mm of pad travel. Its hub is 0.35 mm clear of the body at the least, a bead on the pin runs in a groove so it can't slide off, and the neck is tapered and filleted, so it reaches its strain limit only at about 28 N on the pad.
- **Rail grip.** The shoe only located on the rail. A sprung pad now presses the rail's wall from inside its channel with 9.6 N and holds the shoe on its fixed hook: about 6 N to slide it (friction 0.3). A tooth stops a knock across the rail. The pull-tab clip has the same grip.
- **Socket latch.** After the first print, the flat catch became a 15° undercut hook on a long tapered beam, and the stop post went.
- **Release rod.** It clicks into its tunnel and stays, which also holds a flat holder's dock key in its dovetail. The shoe is about 10.5 cm³.

### Rules the test suite holds

Two rules came in with 3.1.0. The test suite checks them (`tests/flexures.test.ts`, `tests/joints.test.ts`); they are not lines in the Check step.
- **Every printed spring** (`src/fea/flexures.ts`): at most 1% strain at full deflection and 0.2% at rest, so it neither wears out nor creeps. A feature that deforms once, such as a crush rib or a barb, may reach 1.5%, and a spring may reach 1.25% under a design overload such as a 20 N pull.
- **Every stop and catch** (`src/cad/joints.ts`) joins its part at least 1.2 mm wide, inside its own print layer. The tongue stoppers that snapped in the first print did not.

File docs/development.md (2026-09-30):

# Development

Building BoardDock, its tests, and where the code lives. Code conventions and releases are in [CONTRIBUTING.md](../CONTRIBUTING.md); what is still to do, in order, is in [TODO.md](../TODO.md). Back to the [README](../README.md).

Contents:
- [Commands](#commands)
- [The collision test](#the-collision-test)
- [Board tiles and toolbox pictures](#board-tiles-and-toolbox-pictures)
- [Project layout](#project-layout)

## Commands

```bash
npm install
npm run dev                # web app at http://localhost:5173
npm test                   # vitest: importers, holders, panels, dock FEA, and a quick collision check
npm run typecheck
npm run collisions         # the whole collision test (144 racks, a minute or two)
npm run collisions:update  # write a new collision baseline (only on purpose)
npm run boards             # community boards: read boards/<slug>/, update public/boards/
npm run parts              # contributed parts: check parts/*.json, write src/model/parts.json
npm run build              # production web build in dist/
npm run desktop            # Electron app from the build
npm run dist               # installers for the current OS in release/
```

One test file: `npx vitest run tests/<file>`.

## The collision test

`tests/collide/` builds racks through the real generator (every template alone in each pose; boards back to back and stacked; probes; boxes; stands on and off; rails at every angle; a Pi cluster and a busy mixed rack with Auto-connect; a rack changed by hand; a built rack with boards added) and intersects every printed part, board, plug, rail, stand and cable exactly with manifold. A plug in its own jack, a cable in its own plug, a board on its own holder's pins and a DIN clip's hooks in its own holder are allowed. For automatic layouts it also looks for failing Check lines, overlap and clash warnings, rails over **Longest rail** and blocked plugs in use.

Each of the 144 racks' figures is held against `tests/collide/baseline.json`: the test fails when one grows past it, and prints the worst overlaps with part names and coordinates. `npm test` runs a few quick racks and `npm run collisions` all of them (CI runs both). When a fix lowers the figures, `npm run collisions:update` writes the new baseline; only do that on purpose.

## Board tiles and toolbox pictures

The board tiles on Start and in **Add a board**, and the toolbox's pictures, are shipped in `public/tiles/`, each rendered from the thing's own 3D model with a fingerprint of that model in `src/ui/tiles.json`. `npm test` (`tests/toolbox.test.ts`) fails as soon as a model no longer matches its picture (a changed part, template or toolbox entry). Render the ones that changed with the dev server running:

```bash
PLAYWRIGHT=/path/to/playwright/index.mjs node scripts/render-tiles.mjs http://localhost:5173/
```

Add `all` as a second argument to render every one, and commit the pictures with `tiles.json`.

## Project layout

- `src/import/`: the importers (KiCad, Gerber, Excellon, pick-and-place, IDF, Eagle XML in `other.ts` and binary in `eaglebin.ts`, board-viewer in `boardview.ts`, DXF, STEP, IPC-2581, ODB++, GenCAD), Allegro detection, and archives (zip, tar, gzip, Unix compress).
- `src/cad/`: geometry and layout.
  - The holder: `generate.ts` (the holder round one board), `levels.ts` (holder heights), `grip.ts` (the clip sums: sizing, push and hold), `leafplan.ts` (a clip leaf's outline, shared by the model and the FEA), `plugcap.ts` (plug caps), `joints.ts` (the 1.2 mm joint rule), `printcheck.ts` (the layer-by-layer printability check).
  - The dock: `dock.ts` (the rail shoe, socket, tongue, spine and rod), `dockdims.ts` (their dimensions), `dinclip.ts` (the pull-tab DIN clip and the rail grip), `column.ts` (column pegs and holes), `testkit.ts` (the test-fit kit).
  - The rack: `dockplan.ts` (plug access, orientation, column seats and auto-assignment; no geometry kernel), `autoplan.ts` (Auto-arrange's planner; no geometry kernel), `arrange.ts` (its best layout confirmed by the real router), `arrangelock.ts` (Auto-arrange round locked docks and rails), `packnew.ts` (**Pack new boards only**), `panelgen.ts` (the panel: placement, rows, added boards, collisions, parts, assembly steps), `railstand.ts` (table stands).
  - Cables: `cableroute.ts` (routes and their collision checks; no geometry kernel), `cablesim.ts` (cables settling), `cabletag.ts` (numbered tags).
  - Loose layouts and output: `assembly.ts` (loose layouts), `rivet.ts` (the pin-and-U-clip rivet), `boardviz.ts` (board, part and plug detail for the 3D view), `export.ts` (STL and 3MF output, plate packing and estimates), `kernel.ts` (the manifold wrapper).
- `src/fea/`: the 2D solver (`fea2d.ts`), the flat clip (`clipfea.ts`), the dock (`dockfea.ts`), a clip's leaf (`springfea.ts`), beam helpers (`beamfea.ts`), the flexure table and its rule (`flexures.ts`, with rows from `dockflex.ts`, `boardflex.ts` and `rackflex.ts`), and a 3D beam solver for the holder's support ribs (`frame3d.ts`).
- `src/geom/`: plain geometry with no WASM: 2D polygons (`poly.ts`), editing a board's shape (`shape.ts`), 4 × 4 matrices (`mat.ts`) and the rotation box's angles (`angle.ts`).
- `src/model/`: `types.ts`; `templates.ts` (the library's boards and accessories); `holes.ts` (the hole wizard and stacks); `portuse.ts` (which ports are in use); `links.ts` (plug roles, Auto-connect, the port budget and cable sizes); `power.ts` and `powerdata.ts` (the power budget and its estimates); `poe.ts`; `zones.ts` (mains zones); `built.ts` (what was built, and what changed since); `boxes.ts` (boxes from a size and rows of ports); `copper.ts` (decorative copper for boards without their own); `library.ts` (reference data: connectors and their plugs, materials, defaults); `printers.ts` (printers from OrcaSlicer's machine profiles, filament settings and the print settings list).
- `src/ui/`: the React UI. `Viewer3D.tsx` is the 3D view; `pickOps.ts` what a selection is and how it is removed; `panels.tsx` the step panels; `RackBuilder.tsx` the Rails step; `BoardEditor.tsx`, `PanelEditor.tsx` and `WiringView.tsx` the board editor, the Rails view and the Wiring view; `BoxEditor.tsx` the Box tab and Build your own box.
- `src/worker/`: geometry and FEA run in web workers.
- `src/slice/`: in-app slicing with Kiri:Moto: printer start code and settings (`profiles.ts`), running the engine and reading the G-code back (`kiri.ts`), Bambu's template language (`bambutpl.ts`) and the check of a printer's own start code (`startcheck.ts`).
- `vendor/kiri/`: how `public/kiri/` (the Kiri:Moto engine, its workers and printer profiles) is built from the grid-apps source.
- `boards/`, `parts/`: community boards and contributed connectors, each with a guide for people (`README.md`) and steps for an AI job (`AGENTS.md`); `scripts/boards.mjs` and `scripts/parts.mjs` turn them into `public/boards/` and `src/model/parts.json`.
- `electron/`: the desktop shell; `preload.cjs` exposes finding installed slicers and opening a plate in one.
- `.github/workflows/`: CI, and a release job that builds installers for all three platforms and publishes the web app.

Geometry uses [manifold](https://github.com/elalish/manifold) (WebAssembly), which always produces watertight, printable meshes.

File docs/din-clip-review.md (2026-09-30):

# DIN rail clip review

From TODO.md: go through the clip in depth, measuring rather than guessing. There are two parts that grip a TS35 rail, and this review covers both:

1. **The dock's rail shoe** (`src/cad/dock.ts`), with its print-in-place press-down release lever. The socket snaps into it and the holder's tongue plugs into the socket. A board lying flat instead has a separate dock key in a dovetail under the holder's ear.
2. **The pull-tab DIN clip** (`src/cad/dinclip.ts`) for loose holders and for flat mounts in a panel.

**Written before the first print; see [After the first print](#after-the-first-print-petg-fdm) at the end.** Every number here comes from the model: exact geometry, a 2D FEA with a textbook modulus, and hand sums. Fit, strength, grip and the feel of the clips were untested when it was written. The last sections list what only a print can tell.

## How it was measured

- **Geometry.** Exact intersections and offsets with manifold-3d, in the 2D profiles (`shoeProfile`, `leverProfile`, `clipProfile`) and in 3D (`shoe`, `socket`, `holderDock`, `flatHolderDock`, `rod`).
  - Clearances: grow one region by *d* until it touches the other.
  - Play: slide a part in steps of 0.02 to 0.05 mm until it meets something.
  - Engagements: read off the profiles.
- **Lever kinematics.** Turn the lever about its pin in 0.5° steps. At each step, open the jaw just far enough to clear the hook (bisection).
  - The jaw is taken as rigid, swinging about (16.75, 13.76), the middle of its hinge leaf. That point is fitted to the FEA, where the lip moves 1.7 mm while the post moves 4.06 mm. It is an approximation, good to about 10%.
- **FEA.** The app's 2D plane-stress solver (`src/fea/fea2d.ts`) on 0.05 to 0.1 mm pixel meshes, PETG (E 2100 MPa) unless stated.
  - Peaks sit on pixel corners and read high: on a curved edge up to twice the true value. The 99% figure is the steadier one, and both are given.
- **Printability.** The Check step's own layer slicer (`layerCheck` and `verdict` in `src/cad/printcheck.ts`), on each piece in the pose it prints in.
- **Tests.** Every finding and fix below is held by `tests/dinclip-review.test.ts`, plus new assertions in `tests/dockfea.test.ts` and `tests/clip.test.ts`. `npm test` passes, and so do all 140 collision racks (`npm run collisions`), at the committed baseline.

## Summary

| Bullet | Finding (before) | Change | After |
|---|---|---|---|
| Lever: frees the jaw | Correct, but the numbers were wrong: said 1.4 N and 8 mm of pad travel | FEA corrected to where the hook really bears | 2.4 N, about 5 mm |
| Lever: stays on | Its hub's open edge was **0.09 mm** from the neck (prints as one piece). **Nothing held it along the pin**: it could slide 21 mm off the end | Hub opening moved, neck reshaped; a bead on the pin in a groove in the hub | 0.35 mm clear everywhere; at most 0.5 mm of play along the pin |
| Lever: overload | Past the jaw's stop, about **13 N** on the pad brought the 1.0 mm neck, with its 0.05 mm notch, to the strain limit | Neck tapered from 1.8 mm and filleted; tower wider | About **28 N** |
| Tongue in the socket | Latch nose 1.05 mm into the groove, flat catch: "holds". 0.3 mm of rattle | none in this review | **Wrong**: the first print showed it popping out, and the model agrees (about 10 N). Redone in the last section |
| Dock key in its dovetail | Held only by the release rod, and **the rod slid straight out** | The rod clicks into its tunnel (barb under a ledge) | Rod meets the ledge after 0.25 mm; key stopped after 0.25 mm |
| Shoe tight on the rail | **Only located**: 0.8 mm of play across, 0.3 mm out of the wall, nothing pressing. It slid freely, and would slide down a vertical rail | A sprung rail grip presses the rail's wall; a tooth stops knocks | 9.6 N preload, **about 6 N to push a dock along** |
| Clip tight on the rail | Only located: 0.2 mm out of the wall, 0.65 mm up and down, nothing pressing | The same rail grip under the top wall | 6.4 N (14 mm clip), about 4 N to push along |
| Printable | All pieces print without support. Worst bridge 9 mm (flat holder), 8.7 mm in the shoe (its hinge) | new features checked | still no supports; new bridges 4.1 mm at most |
| Box on a clip (done before) | Snap hooks reached 0.7 mm into a box | (already fixed) | box stands 2.3 mm up |

## 1. The release lever

### How it frees the shoe from the rail

The shoe's jaw wraps round the rail flange on the lever's side. Its lip reaches **1.7 mm** under the flange (the flange edge is at y 17.5, the lip's tip at 15.8), with 0.3 mm of play under the flange. The jaw hangs from a 0.9 mm hinge leaf directly above the lip. Pressing the lever's pad turns the lever on its pin, and the hook under the lever pushes the jaw's post toward the socket. The jaw swings about its leaf and the lip slides out from under the flange.

The kinematic sweep, with the rigid jaw:
- **0 to 3°:** the lever takes up the 0.4 mm gap between the hook and the post.
- **21.5°:** the lip is 1.7 mm out, clear of the flange. The pad has gone down **5.0 mm** (13.6 mm from the pin).
- **23.5°:** the jaw meets its stop (the post on the body's shelf) at about 2.0 mm of lip travel. The FEA puts the stop at 2.16 mm.
- **37.5°:** the lever's own travel would end here (the hub's opening meets the neck), so it never limits the release.
- Upwards, the lever could lift 13.5° from rest before its hub met the neck (6.5° now: see the end).

With the grip (section 3) the shoe sits on its fixed hook, 0.4 mm toward that side. The lip then engages only 1.3 mm, so it is clear a little sooner.

**Force.** The hook bears on the post with its lower end: 8.3 mm under the pin at rest, 9.5 mm at 12°, 11.0 mm at 20°, and 11.3 mm at the stop. These are the contact points from the sweep. The FEA had assumed 6.9 mm, above the real contact, so it put the push on the post too high and the pad's lever arm too long.
- Corrected, the release case loads the post over z 28 to 31 and uses the contact 11.0 mm under the pin at the end of the stroke: about **2.4 N** on the pad for PETG (4.1 N for PLA), for about **4.7 mm** of pad travel.
- It had said 1.4 N and 8 mm, which the README repeated.
- The jaw's leaf root reaches 1.7% peak (1.6% before; the push now bears lower on the post), 0.55% for 99% as before. The stop protects it.

### What keeps the lever on

The lever is printed in place round a 3.4 mm pin at the top of a tower beside the socket. Its C-shaped hub wraps about 280°.

- **Across the pin:** the hub's opening is 2.41 mm across at the bore (2.61 mm now), less than the 3.4 mm pin, so it can't come off sideways. Good.
- **Round the pin, as printed:** the bore leaves 0.35 mm all round the pin. But growing the lever's outline by just 0.1 mm makes it touch the body: the edge of the hub's opening (at −111°) came within **0.09 mm** of the neck, over a 0.6 mm wedge the whole 21 mm length.
  - A 0.45 mm line on each side can't leave a 0.09 mm gap, so that edge would print fused to the neck, and the lever couldn't turn without being broken free.
  - The Check step's narrow-slot test missed it: each layer's sliver was under its 0.15 mm² threshold.
- **Along the pin: nothing.** The lever and the pin are both straight 21 mm extrusions with nothing between them. Sliding the lever along the pin in steps up to 21.5 mm met nothing at all. On a vertical rail, or with any knock along the rail, the lever could slide off the end of its pin.

**Changes** (`dock.ts`: `SHOE_LEVER.open`, `TOWER`, `NECK`, `pinBead`):
- **The hub's opening** now runs from −118° to −39°. Its edge is 0.46 mm off the neck, and the least gap anywhere between the lever and the body is 0.35 mm (measured 0.346 on the polygons).
- **A bead** round the middle of the pin, 0.6 mm proud with 45° flanks, runs in a groove inside the hub (the bead grown by the 0.35 mm print gap).
  - The lever slides freely for about 0.5 mm either way along the pin, then a flank meets the other (blocked by 0.6 mm).
  - To pull it off, the hub would have to open 0.25 mm all along its 21 mm length. It is captive.
  - The 45° flanks print without support with the shoe on its end face. The radial gap in each layer is 0.49 mm on the flanks.

### Strength past the stop

Once the jaw is on its stop, pressing harder no longer moves anything. The thumb's force goes through the lever into its pin, down the neck and the tower. A thumb pushing on something that has stopped easily gives 10 to 30 N.

At the stop the hook bears 11.3 mm under the pin and the pad is 12.4 mm out, so each newton on the pad pushes the pin 1.1 N outward and 1 N down.

A 2D FEA of the tower, neck and pin with the body held under the tower:
- **Before:** the 1.0 mm neck had a 0.05 mm notch where it met the tower's chamfer. The peak strain there was 0.154% per N, so **about 13 N reached the 2% limit**.
- **After:** the neck tapers from 1.8 mm at its root to 1.0 mm under the pin, its root is filleted (r 0.8), and the tower is 2.7 mm wide instead of 2.1. The peak moves to the tower's root at 0.071% per N (0.030% for 99%): **about 28 N**.
- The jaw's post would meet the widened tower only at 26.5°, 3° past its stop on the shelf, so the stop still acts first.

The hinge leaf's strain in the pull-off case is unchanged: it reaches its limit at about 121 N. The FEA's shoe mesh was kept the same by giving the grip a model of its own. Adding geometry lower down would have shifted the pixel grid, and the peak with it, by about 7%.

## 2. How the tongue stays in

### The tongue in the socket

> **Superseded** (see "After the first print", the last section): the flat catch here did not hold. It is now a tapered beam with an undercut hook 1.4 mm deep, the 0.3 mm of play is 0.65 mm on purpose, and the anti-rattle leaves are gone.

The holder's tongue (14 × 4.5 mm) goes down into the socket until its pedestal sits on the socket top. The latch nose springs into a groove across the tongue's front face:
- The nose's tip reaches **1.05 mm** into the groove (0.15 mm short of its back).
- Its lower face is flat, so a pull on the holder meets a square catch, not a ramp. It can't be pulled out without the button.
- Holding: pulling the holder out bears the groove's lower face on the nose's flat underside, across the nose's 9.6 mm width.

Play, measured by sliding the tongue (and the holder's whole dock end) until it meets the socket:
- **Up (out):** 0.32 mm before the nose catches.
- **Down:** none (the pedestal is on the socket top).
- **Across:** ±0.16 mm, the tongue between the socket's divider and its front wall.
- **Sideways:** ±0.22 mm.

Nothing preloads the tongue, so a holder can rattle by those amounts. This is **not changed**, and is listed at the end.

**Release.** The button's rod meets the latch's 45° ramp after 0.45 mm. The FEA has the nose clear of the groove after 1.94 mm of the 3.1 mm stroke, for 3.2 N on the button (PETG, friction included); the push-in is 9.2 N. Both are unchanged.

### The release rod

> **Superseded** (see the last section): the rod's tunnel had 0.2 mm each side and jammed in the first print; its barb is now two fingers under a gate, and the tunnel is 0.4 mm each side (0.3 at the gate) with lead-in chamfers.

The rod runs in a 3.6 × 2.6 mm tunnel (the rod is 3.2 × 2.2). **Nothing held it in:** pulled up, it slid straight out without touching anything. On a table rack gravity keeps it down; on a wall, a knock or a hand on the button could pull it out.
- For a standing holder that only loses the button, and the holder stays latched.
- For a board lying flat it matters more (next).

**Change** (`dock.ts`: `rod`, `rodTunnel`; `dockdims.ts`: `HD.catch`):
- **The finger:** a 6.2 mm finger is cut in the rod's side by a 0.5 mm slot, hanging from the button head, with a barb at its foot. The barb stands 0.5 mm proud and has a 45° lead-in.
- **The pocket:** the tunnel's top 2 mm keep their 1.8 mm half-width as a ledge, with a pocket under it.
- **Pushing it in:** the ledge bends the finger 0.3 mm aside, a one-time strain of about 1.05% (1.5 × 0.9 × 0.3 / 6.2²). The barb then clicks out under the ledge.
- **Holding:** pulled up, the rod meets the ledge after 0.25 mm (0.2 mm by design).
- **Pressing:** the barb rides the whole stroke in the pocket. The first thing the rod meets is still the latch ramp at 0.45 mm, and then the grip bar at 3.1 mm under the button head, as before.
- The Check step and the assembly steps now say to push the rod in until it clicks.

### The dock key in its dovetail (a board lying flat)

The key slides into a dovetail groove under the holder's ear, from the ear's tip. The groove is closed at its far end, so the key stops 0.25 mm past its place.
- The dovetail has 0.2 mm clearance a side: ±0.15 mm of play across, and the key can drop 0.35 mm before the flanks bear.
- Without the rod, the key slides back out of the groove's open end: 12 mm and more, touching nothing.
- The rod passes through both the ear and the key, so with the rod in, the key is stopped after 0.25 mm.

So **the key was held only by the rod, and the rod by nothing**. If the rod came out, the flat holder could slide off its key, and off its dock. With the rod now clicked in, the key can't leave the dovetail: the review test slides it 1 mm and finds it blocked. The rod isn't meant to come out again; to replace a key or a rod, print a new one.

## 3. Tight on the rail

### The rail shoe

Measured on the profile against a TS35 × 7.5 rail with 1.0 mm steel:
- **The fixed hook:** it goes under the other flange (2.1 mm under it) with 0.3 mm of play under the flange, and stands 0.4 mm off the flange edge.
- **The jaw:** its lip has 0.3 mm of play under the flange, and its pocket stands 0.5 mm off that flange's edge.
- **The body** rests on both flange tops.

Free travel before anything touches: **0.37 mm and 0.42 mm across the rail** (0.79 mm in all), **0.31 mm out of the wall**, and nothing pressing anywhere.

So the shoe only **located** on the rail; it didn't grip. Along the rail, the only resistance was friction from whatever load happened to be on it:
- A rough hand sum: a docked Pi 4 (about 75 g, its centre of mass about 40 mm out) on a vertical rail loads the flanges with about 0.85 N each. At friction 0.3 that holds back about 0.5 N, less than its 0.74 N weight, so **it would slide down the rail**.
- On a horizontal rail, any nudge along the rail moved it.

**Considered and not used:**
- **A preload through the jaw.** A wedge on the lip steep enough to give a useful preload (about 13°) would pry the jaw open under a pull whenever friction drops below tan 13° ≈ 0.23, undoing the v3 C-jaw's reason for being. The jaw's own spring (about 2.4 N/mm at the lip) is far too soft for a grip.
- **Crush ribs.** They would be crushed, not sprung, and worn by every clip-on.
- **A pad on the flange top.** Every good place for one needs a long leaf through the floor that ties the fixed hook to the rest of the shoe, the floor that carries the pull-off load.

**Change: a rail grip** (`dinclip.ts`: `railGrip`; `dockdims.ts`: `GRIP`, `SHOE_GRIP`). A fork hangs from the shoe's underside into the rail's channel, on the fixed hook's side. It is all in the profile, so it flexes within the print layers. It has:
- a root block, 4.5 mm or more from the rail's middle;
- a 0.9 mm arm along the channel just under the floor (0.8 mm slit);
- a rounded knee (r 1.5);
- a 0.9 mm leg down the wall, with a pad low on it.

As drawn, the pad reaches 0.75 mm into the rail's wall: the 0.4 mm play to the fixed hook plus 0.35 mm of preload. Clipped on, it pushes the shoe onto its fixed hook, so the rail's wall and flange are clamped between the pad (on the wall's inside) and the hook (on the flange's edge). The jaw isn't loaded, so the release and the pull-off are as before.

Clipping on, measured by turning the profile about the hook's finger: the pad first meets the wall's inside face at about 12° of tilt, from inside the channel, and presses in smoothly to 0.75 mm at 0°. It never has to pass over the wall's top edge.

FEA of the fork (its own model, the floor it hangs from held, 21 mm long, PETG):

| | |
|---|---|
| Stiffness at the pad | 27 N per mm |
| Preload at 0.35 mm | **9.6 N** (5.5 to 14 N for 0.2 to 0.5 mm of print and rail tolerance) |
| Strain at the preload | 1.1% peak (a pixel corner on the knee), **0.61% for 99%** |
| Force to slide a dock along the rail | 2 × 0.3 × 9.6 ≈ **5.7 N** (friction on the pad and on the hook); 3.8 N at friction 0.2 |
| A knock across the rail | the tooth meets the wall 0.45 mm past the preload (0.8 mm in all): 1.40% for 99%, 2.5% at the knee's pixel peak, briefly |

A rigid tooth over the knee meets the wall if the shoe is knocked back across the rail. Without it, a knock could take the shoe 0.9 mm back (to the jaw's pocket) and the pad to 1.25 mm: about 2.2% for 99% of the fork.

The shoe goes from 10.04 to 10.45 cm³, with the grip, the bead and the wider tower.

The fork stays 5.8 mm above the panel, and its root 4.5 mm or more from the rail's middle. A screw head in the rail reaching more than 4.5 mm from the middle must be under 4.8 mm tall where a dock sits:
- Pan, cheese, button and countersunk heads pass.
- M5 socket caps (8.5 mm across) stay inside 4.5 mm and pass too.
- M6 socket caps (10 mm across, 6 mm tall) don't. They already came within 0.5 mm of the shoe's floor.

**The collision test.** It counts the pad's designed overlap with its rail as contact, like a rail end in its end block (`tests/collide/measure.ts`).

**Cable routing.** The router keeps cables clear of every part's bounding box. The fork took the shoe's box 2.5 mm down beside the rail, which rerouted cables on two racks (cable into cable 8.5 → 166 mm³ on the boxes rack). Boxes are now taken from each part's `boxMesh`: the shoe and the clip without the grip that hangs inside the rail, which the rail's own box already covers. All 140 racks are back at the baseline.

### The pull-tab clip

Measured on the profile (14 mm clip, 1.0 mm rail):
- The flanges sit between the hooks' faces and the back plate: 0.2 mm of play out of the wall.
- The top wall stands 0.2 mm above the top flange's edge, and the jaw 0.45 mm below the bottom one: **0.65 mm up and down**.
- Nothing pressed. Like the shoe, it only located.

**Change:** the same rail grip, under the rail's top wall (the rigid side; the jaw's side is the release spring).
- Its pad presses the top wall's inner face and holds the clip down on the top flange's edge.
- The wall's inner face is taken as 13.5 mm minus the rail thickness from the middle, for the 0.8, 1.0 and 1.5 mm rails the clip offers. That the walls' outer faces are 27 mm apart on every rail is an assumption.
- FEA: **6.4 N** for a 14 mm clip on a 0.1 mm mesh (7.1 N on the clip FEA's default 0.2 mm mesh; about 0.46 N per mm of clip width), 1.10% peak and 0.63% for 99%. About 3.8 N (friction 0.3) to push it along.
- The clip now sits 0.2 mm lower, on its top hook, so the lower lip engages 1.05 mm instead of 1.25. Release needs only 1.5 mm of lip travel, and the stop is at 1.91 mm.
- The other clip cases are unchanged: tab pulled towards you 1.75 N, down and forward 3.1 N, straight down 4.6 N, snap-on 5.3 N, 1.4 to 1.9% peak.

The Check step has new lines for both: **Rail grip** under DIN clip, and **Rail shoe grip** under Panel.

## 4. Every piece printable

Each piece sliced in its print pose by the Check step's layer check. PETG, a Pi 4 standing and lying flat, an Uno loose on a clip:

| Piece | Prints | Supports | Longest bridge | Longest overhang | Notes |
|---|---|---|---|---|---|
| Rail shoe + lever | on its −X end face | none | 8.7 mm | none | The bridge is the hinge leaf's upper half, printed over the 7 mm gap between its two halves. Lever 0.35 mm clear all round; bead and groove flanks 45° |
| Socket | on its end face | none | 3.5 mm | none | latch nose 0.45 mm clear in its window |
| Holder, standing (Pi 4) | flat on its back | none | 4.1 mm (was 3.9) | 0.6 mm | the rod pocket's roof is the 4.1 mm bridge |
| Holder, lying flat (Pi 4) | base down | none | 9 mm | 0.7 mm | unchanged |
| Release rod | flat on its back | none | none | none | the finger's slots are 0.5 mm, in the layer plane |
| Dock key | on its side | none | 4.1 mm | none | pocket roof |
| Pull-tab clip | on its side | none | none | 0.4 mm | the grip is in the profile |
| Test-fit kit | as above | none | 8.7 mm | none | four pieces, no supports |

Nothing is in mid-air. The changes add nothing over 4.1 mm, so across the whole library the worst stays 9 mm (a flat holder) and 14.4 mm (a DIN plate's slot tops, a warning since before).

The rail shoe's hinge leaf, the one spring that carries the pull-off load, starts its upper half as an 8.7 mm bridge. It prints with a little sag on its first layers at x 3.5. That is cosmetic for a leaf loaded along its length, but worth looking at on the first print.

## 5. The clip's snap hooks under a box

Already done before this review: a box on a flat clip now stands 2.3 mm up, clear of the hooks that reach 1.9 mm above the base.

## What only a print can tell

- **The grip.** Whether 0.35 mm of preload gives a firm hold on a real rail with a real print. How much PETG creep eases it over months (at 0.6%, a little, but not measured). What friction PETG really has on zinc-plated steel or aluminium rail. How much the pad scuffs the rail's wall over many clip-ons.
- **Clip-on and release feel**, now with about 1 to 2 N more to press the shoe home (the pad's force, 3.8 mm under the hook's pivot) and a 2.4 N lever.
- **The lever.** Whether the 0.35 mm gaps and the bead's 45° flanks print free on your printer, first time. A 0.2 mm first-layer squish at the bed end (x −10.5) is the likeliest place for the lever to stick.
- **The rod's barb.** Whether 0.5 mm clicks in cleanly and holds. Holes print a little small, which makes the ledge tighter (about 1.4% one-time strain on the finger with a 1.7 mm half-width ledge).
- **The rail's walls.** Their inner faces are taken as 27 mm apart outside and as thick as the flange. The inside corner radius at the bottom of the channel must be under about 0.7 mm for the pad to sit on the flat.
- **The hinge leaf's bridged upper half** (8.7 mm): how much it sags.
- **The tongue's 0.3 mm rattle** in the socket, and whether it matters on a board you plug into.

## Seen along the way, and since dealt with

> The rattle leaves below (the first bullet) were replaced after the first print: see the last section. The lever's lift, the pull-off FEA and the pixel grid stand.

Four things the review left open, measured and changed afterwards (`tests/dockhold.test.ts`, `tests/dockfea.test.ts`, `tests/dinclip-review.test.ts`). Still none of it printed.

- **The rattle.** The rigid dock end, slid in the socket the review's way, has 0.30 mm of lift before the nose catches, 0.14 mm either way across and 0.20 mm sideways. Now two kinds of leaf, both flexing within the print layers (the holder prints on its back, so the tongue's x-z section is a layer):
  - *Under the pedestal*, a leaf each side (root 1.6 mm from the middle, 1.6 mm thick tapering to 0.9, a 0.5 mm slot over it to flex into) with a 0.4 mm bump on the socket top's side margin. The holder rests up on the nose's catch with the bumps still 0.10 mm pressed: about 1.4 N a leaf (14 N per mm), 3 N up in all. Pressed right home a leaf reaches 1.5% strain (the 3 x 3 pixel peak) and the two push back with 11 N; at the click they add about 4 N to the push (the latch's 9 N stays).
  - *At the tongue's two front corners*, a leaf 0.9 mm thick (1.1 at its root, 0.5 mm slot, hanging from 6 mm down to the tip) with a bump on the 45° corner face. The socket's matching face pushes the tongue back onto its divider and to the middle: 1.2 N a leaf at rest (5.4 N per mm), 0.7% strain; a knock that closes the slot reaches 1.6%.
  - So at rest the holder sits held up on the catch, back on the divider and centred, with the pedestal's bumps pressed 0.10 mm and each corner bump 0.16 mm along its face's normal (0.22 mm as the leaf sees it), and the rigid part touching nothing. Only the bumps overlap the socket (0.4 mm deep at most): the collision test allows a holder's bumps in its socket. `Tongue fit` (looser +) takes the bumps in with the faces.
  - Not done: the pedestal's leaves are cut out of the holder's own wall (a slot over each, a 45° roofed void beside it), so a thin-walled holder has 0.6 mm left over them.
- **The lever's lift.** Its hub meets the neck after 6.5° up (the pad 1.5 mm), not 13.5° (3 mm): the hub's neck-side edge is slanted, 0.35 mm off the neck at the pin and closer at the ring's rim (`SHOE_LEVER.open`, `SHOE_LEVER.stop`). A print gap of 0.35 mm at a 3.55 mm ring is 5.7° at the least.
- **The pull-off FEA** now holds the shoe only where the rail does (under the fixed hook's finger and the jaw's lip) and pulls on the socket's two hooks. Sharing: the fixed hook takes about 56% of a central pull. PETG reaches its 2% limit at about 120 N on both hooks and 80 N on one (a holder pulled off-centre), first in the hook beams' roots at their slits, then the fixed hook's finger; the hinge is not the weakest part (175 N with the jaw alone, before).
  - *Fillets at the slits' bottoms* (`HOOK_SLIT`): each slit is 0.6 mm wide, so its bottom is a full 0.6 mm round (a quarter round across the slit; it was 0.3) and the tab under each hook has a 0.3 mm round into the beam. They round in the shoe's (y, z) profile, which is the layer plane (the shoe prints on its end), so they print as drawn. Wider rounds leave a step in the wall that took more strain than they saved. The limits are now 130 N on both hooks (119 N before, measured the same way) and 87 N on one (80 N before), with the shoe's rail fit, lever and print check unchanged (`tests/hookfillet.test.ts`). Over four positions of the pixel grid (0 and half a pixel over, each way) the spread is 129 to 134 N now against 112 to 126 N before on both hooks, and 77 to 88 N against 73 to 81 N on one: the gain on both is real (about 10%), the gain on one hook (about 6% on average) is inside the grid's own scatter. The fixed hook's finger is now the first place on a central pull: its peak sits at the edge of the rigid support the model holds it by, and thickening it 0.6 mm did not move that reading, so it is left as it is.
- **The pixel grid.** It sits on multiples of the pixel now, a cut pixel keeps the share the outline covers as its stiffness, and the dock's peaks are 3 x 3 pixel averages: half a pixel of shift moves forces and peaks by under 5% and 12% (a third for forces before). The peaks read lower than the corner peaks the numbers above used (about a quarter), so the strains in this note before this section are the old kind. The solver has an incomplete Cholesky preconditioner (a free shoe took 16,000 Jacobi iterations).

Still open from the review: the Check step's narrow-slot test ignores slivers under 0.15 mm² a layer. That is how the lever's 0.09 mm gap at the neck went unseen. A check of the smallest gap between separate islands of a print-in-place part would catch it (the review test does this for the lever).

## After the first print (PETG, FDM)

The first print of a dock (its shoe, socket, a holder and rod) found four things.

- The shoe's rail grip works well; **nothing about it changed**.
- **(A)** The release rod would not go through the holder without a hard push, and pushing that hard broke the button off.
- **(B)** The socket's latch let the holder pop out too easily.
- **(C)** The stoppers of the tongue "snap really easy": the anti-rattle leaves (slots cut out of the holder's wall, sometimes 0.6 mm left over one) and the latch's stop post.

Numbers below are from the model (PETG, E 2100 MPa, the 2D FEA `src/fea/dockfea.ts` at 0.1 mm), as before. Nothing has been printed since. `tests/dockhold.test.ts`, `rodhole.test.ts`, `joints.test.ts`, `dockfea.test.ts` and `flexures.test.ts` hold them.

### A. The release rod's hole and neck

**Cause** (inferred from the geometry and how FDM prints, not measured). The tunnel was 3.6 x 2.6 mm round a 3.2 x 2.2 mm rod: 0.4 mm on the diameter, 0.2 each side. The holder prints on its back, so the tunnel runs across the layers: a hole prints small and its bridged roof sags, and the rod prints a touch big, so 0.4 mm closed up over the tunnel's 50 mm and the rod jammed. Pushed hard, the load ran into the neck: the head is a 16 x 3 mm plate on a 3.2 x 2.2 mm shaft with slots cut right up to it, and the plate is printed on edge, so a push off-centre bends the shaft in the layers' plane (along the layer lines: the strong way) or across them (the weak way).

**Changed** (`dockdims.ts`: `HD`; `dock.ts`: `rodTunnel`, `rodBore`, `rod`):

| | before | after |
|---|---|---|
| Rod | 3.2 x 2.2 | **3.6 x 2.2** (y stays: the socket's core is 0.2 mm off the rod's underside) |
| Tunnel bore | 3.6 x 2.6 (0.4 total each way) | 4.4 x 3.0: **0.8 across, 0.8 in y** (0.4 each side and 0.4 under and over the rod, the roof being the bridge that sags) |
| Tightest place (the gate the barbs pass) | 0.2 each side | 0.3 each side (0.3 measured to the 0.02 mm step) |
| Lead-ins | the rod's tip sloped in y only | 45 degree funnel at the top (1.2 mm on the sides, 1.0 under, 0.5 over), a 0.7 mm chamfer where the rod leaves, and the tip's corners chamfered 0.9 mm |
| Neck | slots to the head, no fillet | solid from the head to 1.7 mm under the tunnel's mouth; fillets in x (R0.9, in the print's layers) and over the shaft in y (R0.6) which the funnel takes when the button is pressed home |
| Head | y 6.4 to 14 | y 6.4 to 12.5: a thumb on its far edge is 1.5 mm nearer the shaft |
| Spine | 6 mm wide, walls of 1.2 mm round the tunnel | 6 mm wide (kept, so that every rack lays out as before), walls of 0.8 mm beside the bore, and under the grip bar a collar 7.7 mm wide, 3.8 mm tall over the barbs' pocket, so that the pocket has 1.2 mm walls |
| Retention | one barb on one finger hanging from the head, a 0.3 mm click | **two fingers standing from the shaft under the mouth**, each 0.75 mm wide with a barb 0.55 mm out; the gate (the top 2 mm of the tunnel, 0.3 each side) bends each 0.25 mm, once. Two, so one catches however the rod sits in its 0.4 mm each side |
| Barb's joint to its finger | 0.5 mm | 1.4 mm (a 1.0 mm lead-in and 0.4 mm of outer face) |
| Flat holder's dovetail | 6.8 mm at its root | 7.8 mm (the pocket is cut across it) |

Print orientation: kept (on its back, y up). The shaft's layers run along it and into the head, so a push along the layers' plane bends it along its lines; the plate's thickness is across them only for the y direction, where the head is nearer the shaft now. Standing the rod on its end would put the neck across the layers for every push.

**The push it takes** (FEA of the neck at the tunnel's mouth, peak strain per newton, the head's 3 x 3 pixel average):

| | before | after |
|---|---|---|
| 1 N pushed 4 mm off-centre, across the rod (along the layers) | 0.122% | 0.101% |
| 1 N on the head's far edge, along the rod (across the layers) | 0.124% | 0.086% |
| the click of a barb finger | 1.4% (0.3 mm on one finger) | 1.0% peak, 0.7% for 99% (0.25 mm, 0.9 N a finger), once |

The neck gain is modest (about 17% across the rod, 30% along it): the shaft's own section under the tunnel's mouth sets the strain, and the tunnel bounds it; the spine could not be widened for a stronger neck without moving every rack's layout. What changed most is what loads it: the push to seat the rod is the two fingers' click (about 2.5 N) and the wedge of the funnel, not a jammed 50 mm.

A rod down a column of three holders, each up to 0.25 mm off the one under it, passes every tunnel in either direction (it could not with 0.2 mm each side).

### B. The socket latch

**Cause.** The catch's face was flat, square to the pull (the review called it a "square catch, not a ramp": true, and not enough). But the nose sits 2.5 mm off the beam's axis, so a pull on the holder is an eccentric load: it tips the beam, and the tip, with the nose, slides **out** of the groove. The FEA had no pull case, so the review never saw it. With a case for it (a 20 N pull on the holding face, friction left out) the old latch's nose moves 2.0 mm out of a 1.05 mm catch: **it slips at about 10 N**.

**Changed** (`dockdims.ts`: `LATCH`, `latchGeom`; `dock.ts`: `latchProfile`, `noseProfile`, `noseSolid`, `latchGroove`; `dockfea.ts`: `latchFea`):

- **Undercut hook.** The holding face slopes 15 degrees, so it is highest at the mouth and the nose sits in a pocket: a pull now has a share that draws the nose in. The angle that cancels the eccentric tip is fixed by the geometry (about 3 x 2.5 / (2 x 14): 15 to 18 degrees) and does not depend on the beam's stiffness, so the beam can be soft and the catch still holds.
- **Deeper.** 1.4 mm into the groove (was 1.05). The groove is 0.65 mm over the nose at rest (was 0.3): the undercut needs it, for the nose to leave up and along the face (0.42 mm). The FEA has the nose rising 0.58 mm as it goes out (an eccentric nose rises as the beam tips), so it separates from the face; with no rise at all the play still covers the undercut with 0.23 mm to spare.
- **A long tapered beam.** 0.9 mm at its root, 0.6 at 7 mm up, 0.9 under the arm, 14.9 mm from the boss's top to the nose's underside (12.6 mm before), the nose 2.35 mm higher. It bends in the socket's print layers, with fillets of 1.0 mm at the root and 0.5 at the nose.
- **The arm** is 0.9 mm thick where it passes the shoe's lever hub (was 1.6), so it clears the hub by 0.3 mm at the release and 0.2 with the button pressed right home.
- **No stop post.** The old post (a 1.0 mm wall, 10 mm tall, cut off the anchor plate) is gone: the button's stroke bounds the arm at 1.9 mm of nose travel, where the beam is at 0.85%.

| Latch, PETG | before | after |
|---|---|---|
| Holding face | flat, 1.05 mm deep | undercut 15 degrees, 1.4 mm deep |
| A 20 N pull | nose 2.0 mm out: slips at about 10 N (friction not counted) | nose 0.4 mm out of 1.4: slips at about 69 N; strain 1.1% |
| Strain at full deflection (the button pressed right home) | 1.4% (over the 1% rule) | **0.85%** peak (0.74% for 99%) |
| Strain at rest | 0 | 0 |
| Push to insert (friction 0.3 included; the leaves added 3.7 N to the click) | 11.2 N | **3.9 N** |
| Button to release | 3.8 N | **2.5 N** (2.1 mm of the 3.1 mm stroke, with the 0.42 mm before the rod meets the ramp) |
| Beam stiffness at the nose | 4.65 N/mm | 1.55 N/mm |

The holder is looser in z (0.65 mm of lift) and its pull is held by the hook, not by the beam or by friction.

### C. The stoppers

Checked how each is joined (`src/cad/joints.ts`, `tests/joints.test.ts`): the joint's width, the thinnest neck between it and the tip, and in the print pose, layer by layer, whether each piece is joined to the body inside its own layer.

| Feature | what it was | now |
|---|---|---|
| Latch stop post | 1.0 mm wall, 10 mm tall, flagged | removed (the stroke bounds the arm) |
| Anti-rattle side leaves (tongue's front corners) | 0.9 mm leaf, 6 mm long, a slot behind it, 0.7% at rest | removed |
| Anti-rattle lift leaves (under the pedestal) | 0.9 mm leaf, 0.5 mm slot, sometimes 0.6 mm left over it, 0.4% at rest | removed |
| Latch nose | 2.7 mm on the arm, no fillet | 2.3 mm on the arm, 0.5 mm fillets, tapering tip: passes |
| Rod barb | 0.5 mm joint to its finger | 1.4 mm: passes |
| Tongue crush ribs | (new) | 1.8 mm where they grow out of the face: passes as a tooth |
| Divider between the tongues | 0.7 mm wall | **0.7 mm, kept**, flagged in the test with its reason: two tongues' back faces 0.15 mm off it leave that much; it is welded to the floor and both walls (29 mm²) |

**Why the leaves went, and what replaces them.** A spring that presses for good has to stay at 0.2% strain or less at rest, or it creeps and takes a set. The leaves sat at 0.7% and 0.4%. A leaf that takes up 0.2 mm at 0.2% has to be 13 mm long and carries 0.45 N: no use. So the anti-rattle is now **two crush ribs**, one on each front corner face of the tongue near its tip, 1.8 mm where they grow out of the face, a 0.3 mm crest standing 0.4 mm proud. The socket's corner faces are 0.28 mm off the tongue's, so a rib is pressed 0.12 mm. They are **meant to deform once**, on the first push in, to the socket's real size. A printed line crushes at about 15 MPa (an assumption, not measured): about 12 N a rib, so about 24 N once for the two, and the holder is snug and centred after. The tongue is otherwise a slip fit: 0.2 mm a side, 0.14 to 0.2 front and back, and 0.65 mm of lift. A holder can rattle by those amounts.

### The flexure table

`src/fea/flexures.ts` (rows from `dockflex.ts` and `boardflex.ts`) holds every printed spring to one rule: at most 1% strain at full deflection and 0.2% at rest (a feature that deforms once, like a barb or a crush rib, may reach 1.5%, and says so), and 1.25% under a design overload (a 20 N pull). `tests/flexures.test.ts` runs them all.

| Flexure | kind | rest | full | 99% | |
|---|---|---|---|---|---|
| Socket latch beam | spring | 0.00% | 0.85% | 0.74% | 1.11% under a 20 N pull |
| Release rod, barb fingers | once | 0.00% | 0.96% | 0.73% | 0.25 mm each, 0.9 N |
| Tongue crush ribs | once | 0.00% | 1.4% at the rib's base | 0.9% | the crest yields on the first push in |

### What only a print can tell (this round)

- **The latch.** Whether a 15 degree undercut with 0.65 mm of play releases cleanly (the model has the nose rising 0.58 mm as it goes out, 0.16 mm over the undercut's; with none, 0.23 mm to spare), and whether a pull of 20 N with real PETG friction holds as the model says. Whether the soft beam (1.55 N/mm) gives a click you can feel.
- **The rod.** Whether the 0.3 mm at the gate and 0.4 mm in the bore are enough on your printer for a hole across the layers, and the finger's click. Whether the funnel and the neck fillets print cleanly.
- **The crush ribs.** The 15 MPa is a guess: they may need more or less than 24 N once, and the fit may want a different height (`CRUSH.proud`) on your printer, or the test-fit kit's `Tongue fit` looser.
- **The divider,** at 0.7 mm, printed standing.

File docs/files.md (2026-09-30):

# Supported files

What BoardDock reads, how it recognises connectors, and how to add boards and connectors of your own. Back to the [README](../README.md).

Contents:
- [File types](#file-types)
- [How connectors are recognised](#how-connectors-are-recognised)
- [Telling .brd files apart](#telling-brd-files-apart)
- [Cadence Allegro](#cadence-allegro)
- [Altium .PcbDoc](#altium-pcbdoc)
- [Zips, tgz and folders](#zips-tgz-and-folders)
- [Adding boards and parts](#adding-boards-and-parts)

## File types

| Source | What to export | What BoardDock reads |
|---|---|---|
| **KiCad** 5 to 9 | the `.kicad_pcb` file | outline (lines and arcs), holes, footprints with courtyard sizes, top and bottom parts, copper traces and vias |
| **Altium Designer** | *File › Export › STEP 3D*, or Gerber + NC drill + pick-and-place | STEP: board outline, holes and part bodies. Fab files: outline, holes, parts. |
| **Fusion 360 / Eagle** 6 and later | the `.brd` file, or STEP | outline, holes, packages |
| **Old Eagle** (3 to 5, binary) | the `.brd` file as it is: no Eagle needed | outline (lines, arcs and circles), cut-outs, holes, parts with their sizes and sides, pin header pins, copper tracks and vias |
| **Board viewers** (the files OpenBoardView opens) | the `.brd`, `.bdv`, `.bv` or `.bvr` file | outline, each part as the spread of its pins, top or bottom, pin nets. No holes or heights. |
| **Cadence Allegro / OrCAD PCB Editor** | the `.brd` file, in the desktop app with KiCad 10 installed | what KiCad reads from it, as for a KiCad board, copper included |
| **EasyEDA / JLCPCB** | Gerber zip + CPL (pick and place) | outline, holes, parts |
| **Any EDA tool** | IDF 3.0 (`.emn` + `.emp`) | outline, cut-outs, holes, part outlines and heights |
| **Allegro, OrCAD, PADS, Xpedition, Altium, Zuken and others** | IPC-2581 (`.xml` or `.cvg`) | outline and cut-outs, board thickness, holes (plated or not; vias left out), parts with their place, side, turn, package size and height, header pins with their nets |
| | ODB++ (a `.tgz` or `.zip`, or the job folder dropped as it is) | outline and cut-outs, holes from the drill layers, parts from the top and bottom component layers with package sizes from `eda/data`, header pins with their nets; inch or mm |
| | GenCAD 1.4 (`.cad`) | outline and cut-outs, board thickness, mounting holes, parts from their shapes, heights, header pins with their nets |
| **Mechanical drawing** | DXF | outline and round holes |
| **No files** | draw it, or start from a template | see below |

**Templates** in the library: Raspberry Pi 4 / 3B+, Pi 5, Pi Zero / Zero 2 W and Pico; Arduino Uno R3, Mega 2560 and Nano; ESP32 DevKitC; perfboard 50 × 70; a blank 60 × 40 rectangle; a 4-channel relay board and a DC power distribution board; and two example boards with debug and UART headers. The accessories (hubs, chargers, switches, supplies, powerboards, a J-Link and a USB-serial adapter) and any community boards are there too. Template boards come from the makers' drawings: check yours.

## How connectors are recognised

Connectors are recognised by footprint name, by the usual makers' part numbers in a footprint or value, and failing both, by their pins. Checked against KiCad's whole connector library, 94% of its footprints are identified (98% leaving out bare solder pads), and none of its 5,600 other parts is taken for a connector. Each is sized for the pins its name says (a 2 × 8 box header, a 6-pin JST) and drawn as itself in 3D, its plug too. Every one is in the board editor's toolbox, with a picture of its own. The families:
- **Computer and network:** USB-C, micro and mini USB, USB-A and B, HDMI, DisplayPort, RJ45 (Bel MagJacks, HanRun, Würth, Pulse…), RJ11, SATA, SFP cages, mini-DIN and PS/2, microSD and SD, SIM slots.
- **Audio, coax, mains and industrial:** 3.5 mm audio, RCA, XLR, TOSLINK, banana jacks, BNC, SMA, MMCX, MCX and SMB, u.FL, D-sub, DC barrel jacks, IEC C14 mains inlets, M12 and M8, XT30 and XT60.
- **Wires and headers:** terminal blocks, box headers for a ribbon, flat-cable (FFC/FPC) sockets, Qwiic, wire-to-board sockets (JST, Hirose DF, Molex PicoBlade, KK, Micro-Fit and more), and pin headers and sockets (Samtec, Sullins, Würth, Harwin, CNC Tech…).
- **Board-to-board and cards:** Samtec QSH, QTE, SEAM and ERM8, Hirose DF12 and DF40, Molex SlimStack, M.2 and mini PCIe, PCIe slots by their lanes, DIMM and SO-DIMM sockets, and spring-pin pads. Nothing is cabled to these. A holder keeps clear of the socket, and of the card in an M.2, mini PCIe, PCIe or DIMM socket; the card or board that goes on them is not drawn.

The sizes come from KiCad's library, drawn from the makers' datasheets, for SATA, XLR, banana, BNC, SMA, TOSLINK, SIM, SFP, SO-DIMM, mini PCIe, the mezzanine bodies, the 3.5 mm jack and the right-angle box header. A few are still typical sizes; [limits.md](limits.md) lists them.

**Names** are read as Allegro libraries and their exporters write them: IPC-7251 header names (`HDRV10W64P254_1X10_…`, `HDRRA…`), a maker's name in front (`SAMTEC_TSW-110-07-L-S`, `TE_5745781-4`), upper case, `_10P` pin counts, and part numbers with the dashes taken out (`TSW11007LS`, `A8291A1T91B`). A bare word such as HDMI, SMA or TRS names a connector only on a connector's reference (J, P, CN, TB, ANT, HDMI1…): a diode package called SMA, a TRS3232 or a USB4640 stays a chip.

**Each is wired as what it is:** an SFP cage is a network port (Auto-connect uses a board's RJ45 before its SFP cage), a C14 inlet takes a kettle-type lead from a powerboard's outlet, TOSLINK goes only to another TOSLINK, XLR takes RCA and 3.5 mm cables, and a banana jack is wires you connect.

**By its pins**, where the name says nothing BoardDock knows (an Allegro board read through KiCad keeps Allegro's names, such as `CON10` or `HDR1X6`), a connector (J, P, CN…) is recognised by its pads: one or two rows at 2.54, 2.0 or 1.27 mm make a pin header; a 2 × 5 at 1.27 mm is the 10-pin debug connector, a 2 × 10 at 1.27 mm with debug nets the 20-pin Cortex one, and a 2 × 10 at 2.54 mm with JTAG nets the 20-pin JTAG one; two staggered rows at 2.77 mm are a D-sub; and a header whose nets are SWD or JTAG, or TX and RX, is a debug or UART header. Each one gets a plug size you can change.

## Telling .brd files apart

A `.brd` can be many things, so BoardDock looks inside: an Eagle XML board, an old binary Eagle board, a board-viewer file (Test_Link `.brd`, BRD2, `.bdv`, BVR) or a Cadence Allegro board. A zip holding one works too.

- **Old binary Eagle boards** (Eagle 5 and older) are read directly, copper included, so you don't need Eagle, which Autodesk no longer sells. Their format was never published: BoardDock follows the layout worked out by the open-source readers pyeagle and pcb-rnd, and says so on the board. Check the outline, holes and parts against your board before you print.
- **Board-viewer files** are the repair-shop kind: they hold part names and pin positions but no package names, holes or heights. A part's size is the spread of its pins, and connectors are found by their names (J1, USB1, CN2), so check each connector's type and add the mounting holes yourself.

## Cadence Allegro

Allegro and OrCAD PCB Editor `.brd` files are binary, and their format is not published. KiCad 10 reads them (releases 16 to 23) with a reader its developers built from hundreds of real boards, and BoardDock uses that rather than guess at a format it has no boards to check against.

**In the desktop app, with KiCad 10 or newer installed (free, kicad.org), drop the `.brd`, on its own or in a zip, and it comes straight in.** BoardDock runs KiCad's `kicad-cli pcb import` on it and reads the KiCad board that makes (KiCad 10 output). It finds KiCad in its usual install folders or on your PATH.

The web app can't run KiCad. Without KiCad, BoardDock recognises the board and says how to get a file it reads: KiCad's *File › Import › Non-KiCad Board File*, then drop the saved `.kicad_pcb`; or IPC-2581, ODB++, GenCAD, IDF, STEP or Gerbers with drill and pick-and-place from the designer or board maker. This was tested with a stand-in for `kicad-cli`, not yet with a real Allegro board.

## Altium .PcbDoc

Altium `.PcbDoc` files use a proprietary binary format. Export STEP or fabrication files instead; BoardDock explains this if you drop one in.

## Zips, tgz and folders

Archives can hold folders, and archives inside archives (a zip with the ODB++ `.tgz` in it). When one archive or folder holds the same board in several formats, BoardDock reads the one that tells it most, in this order: KiCad, STEP, IPC-2581, ODB++, IDF, Eagle, binary `.brd`, GenCAD, Gerber + drill + pick-and-place, DXF. If that file cannot be read it tries the next, and the board's notes say which file was used, which ones failed and why, and which were not needed. An archive with several board files of the same kind (three `.kicad_pcb` files) comes in as several boards.

## Adding boards and parts

The short version is in the README, under [Adding boards and parts](../README.md#adding-boards-and-parts).

- **`boards/`** adds a board to the library, under **Community boards**. Put its files in `boards/<slug>/`: one is enough (a KiCad `.kicad_pcb` is best; or IPC-2581, ODB++, GenCAD, IDF, an Eagle `.brd`, Gerbers with drill and pick-and-place, or a DXF outline), with a small `board.json` saying who made it and on what terms. Only upload what you may share. Then run `npm run boards -- <slug>`: it prints what it read (outline, holes, and which connectors it could not identify) and updates `public/boards/`. Guide: [boards/README.md](../boards/README.md).
- **`parts/`** teaches BoardDock a connector with one small JSON file. `names-….json` maps part numbers or footprint names to a connector type it already has, which fixes a `NOT IDENTIFIED`. `type-<id>.json` adds a new connector type (size, plug, what it connects to, and a look made of simple shapes), which shows in the toolbox under **Contributed**. Then run `npm run parts`: it checks the file and writes `src/model/parts.json`. Guide: [parts/README.md](../parts/README.md).

Run the tests the guide names, commit, and open a pull request ([CONTRIBUTING.md](../CONTRIBUTING.md) has the rest). Or open it with just the files: CI runs the same check and shows the report.

**The optional AI job.** A maintainer adds the `boards` or `parts` label to the pull request, and a Claude job follows `boards/AGENTS.md` or `parts/AGENTS.md` on its branch: it writes the hints or names, regenerates the data and commits. It needs the repository's `ANTHROPIC_API_KEY` secret, runs only for branches of this repository and only when the label is added, and does nothing in forks.

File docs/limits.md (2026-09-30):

# Honest limits

What BoardDock has not proved, and where its numbers are approximate. Back to the [README](../README.md).

Contents:
- [Printed and tested](#printed-and-tested)
- [The models](#the-models)
- [Holding boards](#holding-boards)
- [The dock, rails and stands](#the-dock-rails-and-stands)
- [Boards, files and connectors](#boards-files-and-connectors)
- [Layout, cables and power](#layout-cables-and-power)
- [Printing and G-code](#printing-and-g-code)

## Printed and tested

- **One rack has been printed so far, from 3.0.0.** The DIN rail clip worked. The release button's tunnel was too tight and the button broke, the snap pins broke, the socket latch let a holder out too easily, and the tongue stoppers snapped. 3.1.0 redesigns all four (see the [DIN clip review](din-clip-review.md#after-the-first-print-petg-fdm)), but nothing from 3.1.0 has been reprinted.
- Fits, snap forces, creep and fatigue all depend on your printer and filament. Print the test-fit kit first.
- Least tested: the spring clips, hairpins and fixed ledges, the undercut latch, the rod's gate, the crush ribs, the column pegs' fit, the long release rod through a column, the slot for a board nothing clips in, the tongue under a tall column, boards lying flat, and the box holders.

## The models

- The FEA is linear, 2D and idealised. It has no contact, friction or print anisotropy, and its peaks sit at pixel-mesh corners. Treat it as a comparison between designs, not a guarantee.
- Only the dock's springs (the latch, the shoe's hinge and its rail grip) and the flat DIN clip get 2D FEA in the app. The spring clips, caps and rivets are beam sums with a textbook modulus, checked against FEA in the test suite. The stands, the tongue and tipping are hand calculations.
- The flexure rule (1% at full deflection, 0.2% at rest) and the 1.2 mm joint rule are held by the test suite, not by the Check step.

## Holding boards

- The feel of a clip's click, how firmly a board is held, whether a lip's 0.9 to 1.3 mm ledge droops, and how the anti-rattle springs' push creeps over years in a warm cabinet are for a print to tell.
- Every board is held by its edges, so it needs clear edge for its clips (and, where plugs take most of the edges, for a ledge). Where there isn't enough (a USB-serial adapter, docked or flat; a round board of about 20 mm lying flat; a board docked on an edge crowded with plugs), the Check step says **Nothing clips this board in**.
- The Nano's 8 mm hairpin is over the limit in PLA; print it in PETG.
- The frame holder's stiffness is from geometry, not tested: the board itself stiffens the frame once it is clipped in.
- **Columns:** a board whose plugs are all on one long edge (a Pi Zero) must be the top of its column. Below the top, a plug pointing up the column sits where the holder above stands, and Check says **Plug up the column**.

## The dock, rails and stands

- **The shoe's rail grip rests under a permanent preload** of about 1% strain, more than the 0.2% resting rule allows. It is what holds the shoe on the rail, and the rail clip worked in the first print; how much creep eases it over the years is for a print to tell.
- The rail grips (on the shoe and on the pull-tab clip) come from a 2D FEA with a textbook modulus and a guessed friction (0.3, PETG on zinc-plated steel). How firmly a dock really holds its place is untested. Each grip hangs 1.7 mm into the rail's channel, from 4.5 mm out from the rail's middle, so a screw head in the rail that reaches under it must be under 4.8 mm tall: pan, cheese, button and countersunk heads and M5 socket caps pass, M6 socket caps don't.
- The tongue's crush ribs flatten to fit the first time a holder goes in (about 24 N, once). The crush stress is assumed, not measured, so they may need more or less on your printer.
- A large board docked by one tongue feels a sizeable lever when you plug in a stiff cable at the far end. The tongue is 14 × 4.5 mm at the socket mouth (a Raspberry Pi 4 holder: about 25 MPa for a 20 N push on its far edge, against PETG's 45 MPa yield), and the Check step lists it for every board. Hold the holder while you plug in.
- The rail release is reached with the holders out (they cover the lever). Taking a single board out is the button on the holder, which is always reachable.
- A DIN plate standing off a holder's edge (rack or inline) prints standing, so the tops of its two slots are 14.4 mm flat bridges. If the clip goes on stiffly, trim the sag off with a knife or file.
- The table stands' fit, the dovetails and the cable combs' snap lips are sized from typical FDM tolerances, not from test prints. The sag and cap-stress numbers are hand calculations.

## Boards, files and connectors

- Template boards come from the makers' drawings; check yours. Imported part heights are only as good as the source (IDF and STEP are best).
- Some connector sizes are still typical ones, with no public datasheet drawing to check them against: M.2 sockets, PCIe slot depth, full-size DIMM, M12, RCA, DisplayPort, mini HDMI and Qwiic, and every connector's plug.
- Two boards that mate on a board-to-board connector aren't treated as one stack: put them in a stack by hand.
- Allegro `.brd` import was tested with a stand-in for KiCad's tool, not yet with a real Allegro board.
- Old binary Eagle boards are read from a format that was never published: check the outline, holes and parts.

## Layout, cables and power

- Plug roles for Auto-connect are guessed from connector types and names, except on boxes, where you set them; check the Wiring view.
- Cable routes are checked against bounding boxes: one marked clear is clear, one marked as touching may still fit, and real cables are floppier and stiffer in places than the drawn tubes. Cable tags are sized from typical cable diameters (USB 4 mm, Ethernet 6 mm, HDMI 7 mm).
- A second J-Link for one board needs a ribbon of about 250 mm (a 30 cm ribbon; the **Debug and serial** panel says so).
- The power budget uses estimates: the makers' recommended supplies and typical draws under load. BoardDock can't check voltages or polarity, your powerboard, its lead, earth or the wall socket.
- Big racks are slow to build the first time (one you have built before comes back instantly).
- "Only what's new" recognises parts by their geometry. If you change a holder setting after marking the rack as built, that holder counts as new even if you would not reprint it. A board that carries a stack is never put into another dock's empty slot automatically; place it by hand in the Rails step.

## Printing and G-code

- The printability check works on the parts' shapes, not on a real slicer's toolpaths. Its survey of the whole library was made before 3.1.0.
- Kiri:Moto has no bridge detection, so the longest bridges sag a little more there than in OrcaSlicer or PrusaSlicer.
- The in-app G-code has not been run on a printer. The start code comes from Kiri:Moto's community profiles (the X1 Carbon uses the P1S's) or BoardDock's plain templates, not from the printer makers, and the check of code you bring can't tell that it is right for a printer. Check the start of the first print, or use your own slicer. Slicing a full plate in the app takes much longer than a desktop slicer (seconds to a minute or more).
- The desktop app's **Open plate** looks for slicers in their usual install folders and has not been tried with every slicer and operating system. If nothing opens, download the plate's 3MF and open it by hand.

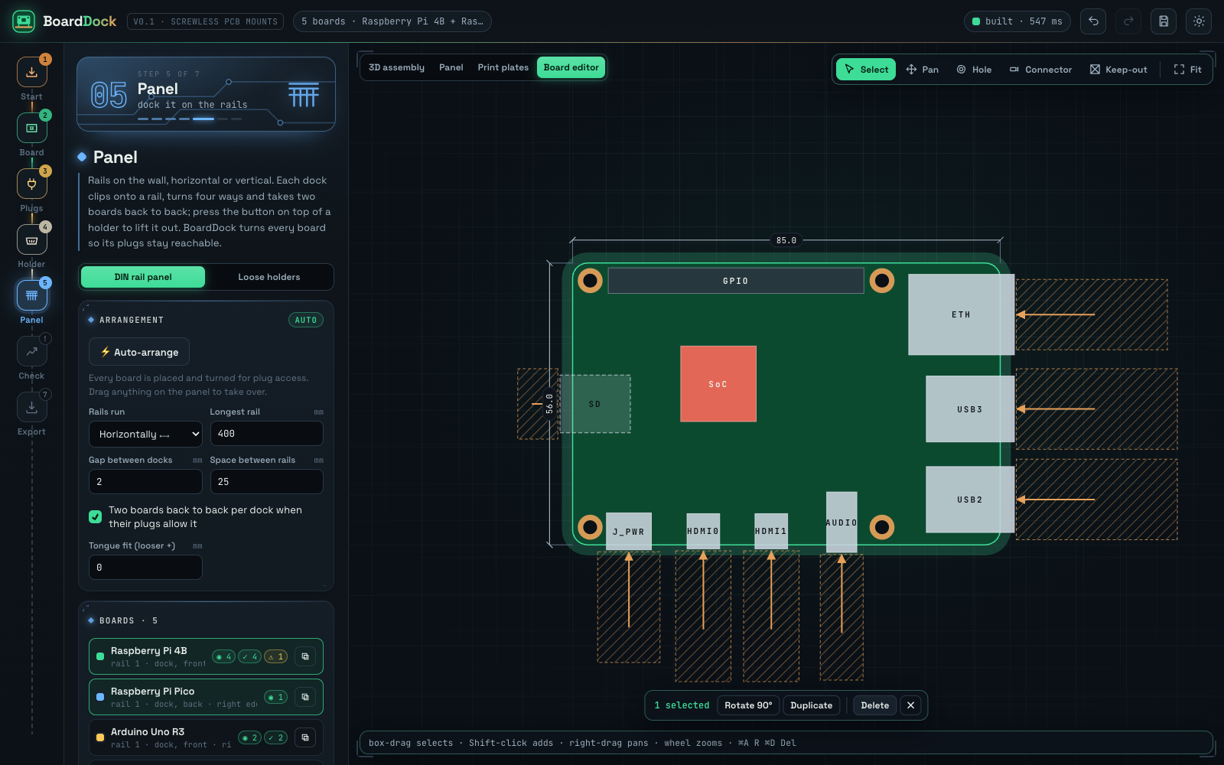
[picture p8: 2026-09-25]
docs/images/editor.png

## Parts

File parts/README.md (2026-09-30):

# Contributed parts

Teach BoardDock a connector it does not know. Two kinds of contribution, each **one small JSON file** in this folder:

| You want | You add | Result |
|---|---|---|
| A board's report says `NOT IDENTIFIED` (or the app makes a part a **Custom** connector) but it is really an RJ45, a USB-C, a JST... | **names**: `parts/names-<anything>.json` | that part number or footprint name is recognised, on every board, from then on |
| A connector the library has no type for at all | **a new type**: `parts/type-<id>.json` | it joins the connector list, and the toolbox (board editor) under **Contributed** |

Everything is checked by one command, `npm run parts`, and written (compact) to `src/model/parts.json`, which is all the app reads. The app stays small: with nothing contributed the data is a few bytes, and a name costs about as much as its own text.

## Names

The quickest way to teach recognition: part numbers or footprint names, mapped to a connector type the library already has.

```json
{
  "type": "rj45",
  "names": ["ACME-ETH-1A1", "ACME-ETHJ-*"],
  "weak": ["Acme jack"],
  "source": "Acme datasheet ACME-ETH-1A1 rev C, page 2"
}
```

| Key | Meaning |
|---|---|
| `type` | a connector id: `npm run parts -- --types` lists them (`usb_c`, `rj45`, `jst_ph`, ...) |
| `names` | part numbers or footprint names. They count anywhere in a part's footprint or value, as a whole word, in any case, with `-`, `_` and space alike. `*` stands for any characters, `?` for one: `HFJ11-*` is every HFJ11 part |
| `weak` | plain words that name the connector but could name a chip too (`Ethernet`, `HDMI`): they count only when the part's reference says connector (`J1`, `CN2`, `HDMI1`), and never over the library's own reading |
| `pins`, `rows`, `pitch` | optional: for the connectors whose width follows their contacts (JST, Molex, box headers, FFC): this many contacts (in 1 or 2 `rows`) `pitch` mm apart, so the body is as wide as that. The report warns when a type ignores them |
| `note`, `source` | free text for people: where the name comes from |

A file is one object like this, or a list of them (several types in one file). The file name is `names-` and anything you like (`names-molex.json`, `names-my-board.json`).

**A plain word is refused.** A name that is a single bare word (`HDMI`, `Ethernet`, `SMA`, `PJ-*`) also names chips, diodes and modules (`TB6612`, an `SMA` diode package), so it is refused as a name; put it under `weak`, or give a real part number or footprint name. Names shorter than four characters, bare short numbers, and any name that would also match one of the parts known to be no connector (`tests/connector-names.tsv`, rows marked `-`) are refused too. Names the library already recognises are warned about (not needed), and the same name for two types is an error.

## A new type

For a connector no type fits: an id, a size, its plug, how it is wired, and a look.

```json
{
  "id": "jack635",
  "label": "6.35 mm (1/4 in) audio jack",
  "plugName": "6.35 mm plug",
  "entry": "edge",
  "body": { "w": 14, "l": 20, "h": 12 },
  "plug": { "w": 16, "h": 16, "len": 30, "cable": 6 },
  "tht": true,
  "role": "audio",
  "offRack": "to an amplifier or an instrument",
  "look": [
    { "box": "black", "from": [0, 0, 0], "to": [1, 1, 1] },
    { "mouth": "round", "at": [0.5, 0.5], "size": [0.62, 0.62], "depth": 0.8 },
    { "barrel": "metal", "at": [0.5, 0.5], "d": 0.7, "y": [0.85, 1], "bore": 0.87 },
    { "pins": "gold", "n": 1, "pitch": 1, "d": 1.4, "at": [0.5, 0.2, 0.5], "len": 0.45, "axis": "y" }
  ],
  "names": ["ACME-J635-*"],
  "weak": ["6.35 mm jack"]
}
```

The file is `type-<id>.json` (`type-jack635.json`). Both examples are in [`examples/`](examples/) and are checked by the tests; they are not part of the app.

| Key | Meaning |
|---|---|
| `id` | lower case letters, digits and `_`, not one the library has |
| `label` | its name in the toolbox and in lists |
| `plugName` | its mating plug in a few words (default: the label) |
| `entry` | `edge`: the plug goes in through the board edge (the toolbox puts it on the nearest edge, facing out); `top`: the plug goes in from above |
| `body` | the receptacle in mm: `w` across the mouth, `l` along the way the plug goes in, `h` above the board. The toolbox and the 3D model are this size |
| `plug` | the mating plug in mm: `w` across, `h` up, `len` along the way in, `cable` its lead's thickness. The holder is made to clear it |
| `zc`, `overhang` | optional: the height of the plug's axis above the board (default half the body's height), and how far the body hangs over the board edge |
| `tht` | through-hole (default false) |
| `role` | how it is wired: `net` like an RJ45, `usb` like USB-C, `power` like a DC jack, `audio`, `video`, `mains-in`, `wire` like a terminal block, or `other` |
| `offRack` | where its lead goes when it leaves the rack ("to an amplifier"); a default per role |
| `cradle`, `note` | optional: a holder cradle for the plug (default off), a sentence shown with it |
| `names`, `weak` | optional: the names that identify it, as above |
| `look` | how it is drawn: 1 to 12 shapes (below). Leave it out and it is drawn as a plain connector: a metal housing with a dark mouth |

**A look** is built from four shapes. Every position is a **fraction of the body**: x across the mouth (0 left, 1 right), y along the way the plug goes in (0 the back, 1 the mouth end), z up (0 the board, 1 the top). Later shapes are drawn over earlier ones.

| Shape | Keys |
|---|---|
| `box` | `{ "box": "<material>", "from": [x, y, z], "to": [x, y, z] }` |
| `mouth` | `{ "mouth": "rect" or "round", "at": [x, z], "size": [w, h], "depth": d }`: an opening in the front face (y = 1), cut into every shape before it; `size` as fractions of the width and height, `depth` a fraction of the length |
| `barrel` | `{ "barrel": "<material>", "at": [x, z], "d": d, "y": [from, to], "bore": b }`: a round barrel along y; `d` a fraction of the smaller of width and height, `bore` (optional) the hollow's diameter as a fraction of it |
| `pins` | `{ "pins": "<material>", "n": n, "pitch": mm, "d": mm, "at": [x, y, z], "len": l, "axis": "y" or "z" }`: a row of `n` square pins `d` mm wide, `pitch` mm apart across the width, centred on x, each starting at [y, z] and running `len` (a fraction) along its axis (`z`: standing up, the default) |

Materials: `metal`, `black`, `gold`, `white`, `blue`, `red`, `yellow`, `tin`, `chip`.

The shapes together must **fill the body** (the toolbox says it is w x l x h): the check tells you when they reach only 12 of its 14 mm across, or stick out of it. Start with a `box` from `[0, 0, 0]` to `[1, 1, 1]`, cut the mouth, add what is inside or on it.

## Turn the files into data

```bash
npm ci                          # once
npm run parts                   # check every file in parts/, print the report, write src/model/parts.json
npm run parts -- --types        # the connector ids, wiring roles and materials you may use
```

The report says what each file does, with `WARNING` and `ERROR` lines, each saying what to write instead:

```
parts/examples/type-jack635.json
  jack635    6.35 mm (1/4 in) audio jack: on an edge, 14 x 20 x 12 mm, wired as audio, look of 4 shapes
    name  ACME-J635-*
    weak  6.35 mm jack
```

An error stops it (nothing is written). `--dry` only reports, `--strict` also fails on warnings, `--check` fails when `src/model/parts.json` is out of date.

Then `npx vitest run tests/parts.test.ts tests/connector-names.test.ts`, commit `parts/` and `src/model/parts.json`, and open a pull request. Two pull requests adding files can conflict in `src/model/parts.json`: take either side and run `npm run parts` again.

To see it: `npm run dev`, then in the board editor open the toolbox: a new type is under **Contributed**, and a name shows up when you import a board (or run `npm run boards`: the connector is no longer `NOT IDENTIFIED`).

## Don't want to run anything?

Open the pull request with just the file. CI (`.github/workflows/boards.yml`) runs the check on it and shows the report. If the repository has an `ANTHROPIC_API_KEY` secret, a maintainer adds the **`parts`** label and an AI job follows [`AGENTS.md`](AGENTS.md) on the PR branch: it fixes the file, regenerates `src/model/parts.json` and commits. It only runs for branches of this repository, only when the label is added, and does nothing in forks without the secret.

## Pictures

A contributed type needs no picture: until one is rendered the toolbox shows a plain drawing made from its look. Maintainers render 3D ones together with the built-in parts (`node scripts/render-tiles.mjs`, see the top of that file), which also picks up contributed types.

## How it fits together

`parts/*.json` (source of truth) -> `npm run parts` (`scripts/parts.mjs` and `scripts/parts-lib.ts`, using the app's own library, so a warning about a name the library already knows is true) -> `src/model/parts.json` (one line per group of names and per type) -> `src/model/contributed.ts`, which `guessPackage` (names), the connector library and the toolbox (types), wiring (`role`, `offRack`) and the 3D drawing (`look`, `src/cad/lookdraw.ts`) read. It is compact rather than lazily loaded because footprint recognition runs everywhere (import, the workers, this command): if the data ever grows past a few tens of kilobytes, that is the time to make it lazy.

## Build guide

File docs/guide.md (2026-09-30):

# Using BoardDock

The app, step by step. For how the printed parts work, see [design.md](design.md); for printing, [printing.md](printing.md). Back to the [README](../README.md).

Contents:
- [Start and the library](#start-and-the-library)
- [The board editor](#the-board-editor)
- [The hole wizard](#the-hole-wizard)
- [Plugs, ports and protection](#plugs-ports-and-protection)
- [The Holder step](#the-holder-step)
- [The Rails step](#the-rails-step)
- [Stacks and columns](#stacks-and-columns)
- [Boxes, power and powerboards](#boxes-power-and-powerboards)
- [Cables and the Wiring view](#cables-and-the-wiring-view)
- [J-Links and serial adapters](#j-links-and-serial-adapters)
- [The 3D view](#the-3d-view)
- [A new version of a board](#a-new-version-of-a-board)
- [Coming back to add a board](#coming-back-to-add-a-board)
- [Loose holders](#loose-holders)

The seven steps are **Start**, **Board**, **Plugs**, **Holder**, **Rails**, **Check** and **Export** (keys **1** to **7**). Every step has **Back** and **Next** at the foot of the sidebar.

## Start and the library

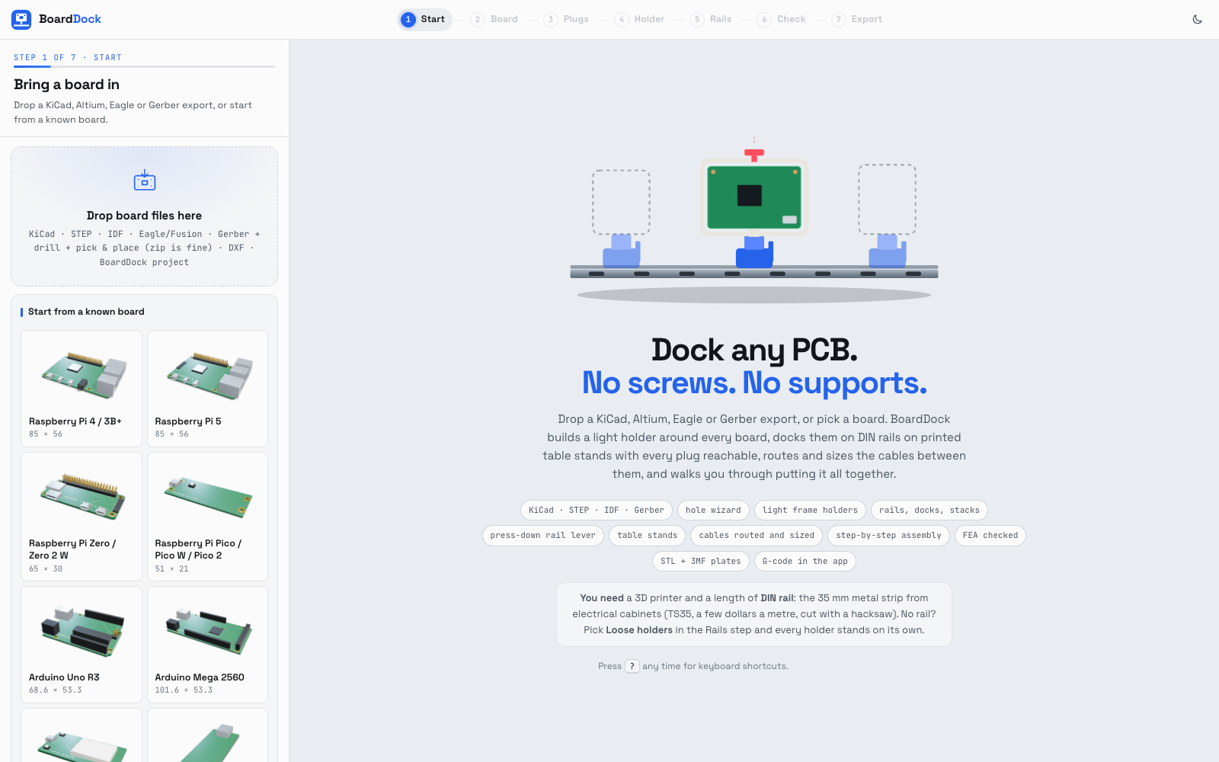
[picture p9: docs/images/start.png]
Start screen


*(This picture predates 3.1.0: today's Start has the three ways in, Your printer, the cluster preset and the library shelves.)*

There are three ways in:
- **Drop your board's files.** Several at once is fine: each becomes a board, and you stay on Start with a **Check the boards** button.
- **Draw your own:** a board's shape, size and holes, and a photo of it if you like (see [the board editor](#the-board-editor)), or a box (see [Build your own box](#build-your-own-box)).
- **Open a saved rack.**

Above them is **Your printer**, kept in this browser for new racks: the plates, oversize parts and print times are for it from the start.

Below them is the library: every board and accessory with a 3D picture, on shelves (Raspberry Pi, Arduino and ESP32, hubs and chargers, powerboards, probes and adapters, community boards, **My boards**…), with a search. Click a tile to add it, or **+** on several and **Add N boards** adds them as one undo step. **+ Board** in the top bar (or the **A** key) opens the library from any step.

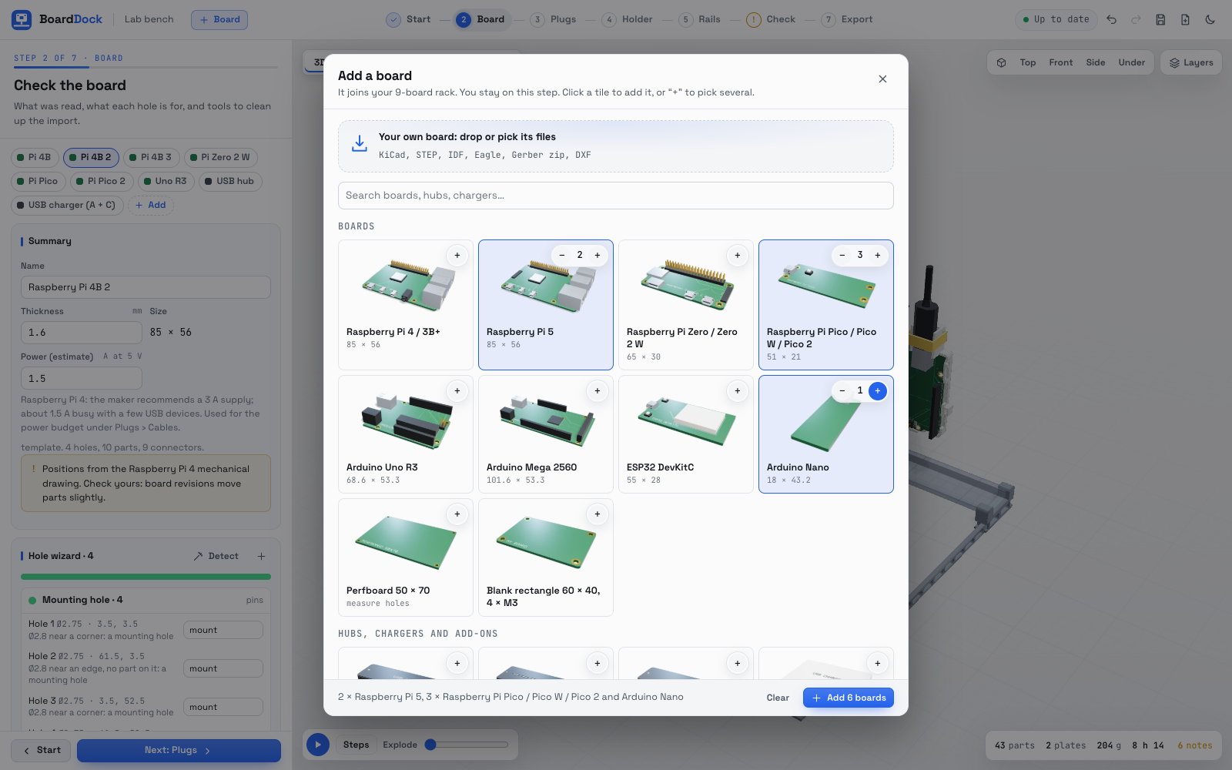
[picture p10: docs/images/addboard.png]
Adding a board from any step


- A second Pi 4B is named "Raspberry Pi 4B #2", so every list, label and cable says which one.
- **Remove** on a board's card in the Board step takes it out; Undo brings it back.
- With a rack open, Start says how far along it is, and the sidebar is a checklist of steps you can click through.
- On a phone, Redo, Save, New rack and the theme are under **⋯** in the top bar.
- **Building a Pi cluster?** The **cluster** preset above the library takes a number of Pi 4s or Pi 5s (up to seven), with or without PoE. It adds them with a switch, a powerboard and their supplies (or a PoE switch and no supplies), and connects it all, in one undo step.
- **Complete this rack** (on Start under **Your rack**, and at the top of the Wiring view's **To do** tab) adds what a rack still lacks: a supply for each Pi, outlets, a switch and its uplink. One undo step.
- **Ctrl/Cmd+K** opens the command palette: type to find a step or an action, then Enter. On a phone, use the search button in the top bar.

## The board editor

The Board step is a 2D editor for any board: one read from a file, one from the library, or one you draw from nothing. It draws the board the way it looks: the solder mask in the board's own colour, copper tracks a shade lighter under it, part shadows as long as the parts are tall, chip legs, tinned ends on resistors and capacitors, header pins with pin 1 square, what each pin is for (GND, TX, RX…) beside it, references in the silkscreen, and the board's name in a free corner.

The copper is the board's own when it came with it: from a KiCad file, an old binary Eagle board, or an Allegro board read through KiCad. Every other board gets plausible tracks drawn in for looks, and nothing is made from them. **Tracks** hides them.

- **The toolbox** is docked on the left (**T** shows or hides it): every plug, header, debug connector, hole and tall part as a picture of its own 3D model, in groups, with a search. Click one and it follows the pointer, snapping to the nearest edge if it is a plug, then click where it goes (Shift keeps placing); or drag it onto the board.
- **Snapping.** Dragging parts or holes snaps them to the board's edges and middle and to the other parts' sides and centres, with a guide line, and shows how far they are from the nearest edges. Alt drags freely; the arrow keys nudge.
- **The board check** under the board's card says what, as drawn, would spoil its holder, each with a fix: a hole off the board, too near an edge, under a part, or there twice; a plug whose mouth sits back from the edge (**Move it to the edge**) or faces into the board (**Turn it round**); a part off the board, or two on top of each other; a thickness no board has. **Fix all** does the safe ones in one undo step. A real board's holes are never moved: one in the wrong place is left out. A board with no holes is held by its clips; for one you are making, **Add corner holes** puts M3 holes 3.5 mm in from the edges.
- **Plug labels** (J_PWR, USB-C, HDMI0…) are printed just inside each plug on an edge, in 2D and 3D.
- **Click any dimension** to type what you measured: the board's **width** and **height** (the board stretches), and every dimension you put in.
- **Measure** (**M**) puts a dimension between two features: an edge, a corner of the outline, a hole's centre, or a part's centre or side. Type what your calipers read and the part (or hole) moves to it; a hole takes the holes in line with it along (untick to move just the one), and between two edges it sets the board's width or height. Drag a label to place it yourself; **Put back** and **Tidy all** hand the placing back to BoardDock.
- **Photo.** Put a photo of the real board under the drawing, scale it from two points and the distance between them, line it up, and trace the parts over it.
- Hover anything for what it is: its size, height, side, position, which way its plug goes in, what a hole is for, and how far it is from the left and bottom edges.

The sidebar has the board as a card (its 3D picture, size, thickness, holes and plugs; **In 3D**, **Save to My boards**, **New version…**) and tabs: **Parts** (plugs, tall parts, parts underneath), **Holes** (and **Add four holes** by spacing), **Headers**, **Board** (what it is: a board, or a debug probe or USB-serial adapter you drew yourself) and **Box** for a box.

**Draw your own** (on Start, or in **+ Board**): a rectangle, a rounded one or a round board, with its size, corners and thickness; holes at the corners or by their spacing (a Pi's are 58 × 49 mm apart); and a photo to trace over. **More shapes** has L-shaped, a notch in an edge, a corner cut off, a polygon (3 to 16 sides) and a round board with a flat. **Your own** opens the Shape tool's Line mode to draw the outline corner by corner.

**Save to My boards** keeps the board (or box) in this browser; the library's **My boards** shelf lists them for any rack. Its **×** takes one off, and the toast's **Undo** puts it back.

**On a box**, what you do in the editor sticks: drag a port and it stays exactly there; drag a side port to another side and it moves onto it; delete one and it leaves its row; put a plug on it from the toolbox and it becomes a port of the box.

**Shape** (**S**) changes the board's outline and its cut-outs. Three ways to work:
- **Edit:** drag a corner, or drag an edge to slide it straight out or in. Click the **+** in the middle of an edge to add a corner. Select a corner to type its X and Y, round it or cut it off, or press Delete; select an edge to type its length or bend it into an arc. With nothing selected, **Round** or **Cut** does every corner at once.
- **Line:** click corners one after another and click the first to close the shape (or press Enter). Shift keeps each edge to 15° steps. Type a length (and an angle) and press Enter for an exact edge. **Arc** (or A) makes the next edge a three-point arc. The closed shape is **added** to the board, **cut out** of it, or becomes a **new outline**.
- **Shapes:** a rectangle, circle or slot of the size you type, added to the board or cut out of it.

Everything snaps (Alt snaps nothing). An edit that would make edges cross, cut the board in two, or add a shape that does not touch it is refused, and says why. Holes and parts a new shape leaves off the board are ringed in red until you move them. Each edit is one ⌘Z.

## The hole wizard

Not every hole is for mounting. The wizard sorts them when a board comes in, and you can change any hole or group (Shift-click several and change one to change them all):

| Kind | Found by | The holder |
|---|---|---|
| **Mounting hole** | no part on it, near a corner or edge, 2.2 to 4.5 mm | puts a locating pin through it (it grips nothing: the clips hold the board) |
| **Connector peg** | inside a connector's body (RJ45 pegs, USB shell tabs, jack pins) | leaves it free, with a pocket underneath |
| **Part lead** | inside a part, or in a row at header pitch | leaves it free, with clearance for the leads |
| **Stacking standoff** | lines up with a hole of a board bolted on top | leaves it free, with room for the screw head or nut |
| **Ignored** | set by hand | does nothing |

Under the list, **Pins in the mounting holes** sets every mounting hole at once: **Locating pins** or **Ignore**. A selected hole has the same choice (**Locating pin** / **Ignore**). The board editor colours every hole by its kind.

## Plugs, ports and protection

Every connector gets an opening in the holder's wall, sized for its plug. Only the ports in use also get a **cradle** that carries the plug's body (so a knocked cable loads the holder, not the solder joints), a snap-on **cap** that locks the plug in, a **guard** collar, and a **zip-tie anchor** on the side the cable is pulled to. Every other port is left bare: its opening is still there to plug into later.

A port is in use when:
- a cable to it is in the app;
- it is the board's power input, or, on a board with no cables in the app, its main USB port;
- it is a debug or UART header (so adding a probe later needs no new holder);
- on a box, it is the box's own supply (mains in, DC in);
- you said you'll plug something into it.

In the Plugs step each connector has a tag: *empty*, or why it is in use (*cable*, *power*, *supply*, *you plug in*). Tap it to say you'll plug something into it yourself (a screen, a keyboard, a supply off the rack), or that it stays empty; tap again for automatic. The same choice is under **Will a plug be in it?** for the selected ports: **Automatic**, **Yes, I plug it in** or **No, it stays empty**. So a headless Pi's HDMI and audio ports are bare without you doing anything.

For the selected ports:
- **Protection** has a tick each for the cradle, the snap-on cap, the guard collar and the zip-tie anchor. Ticking one on an empty port marks it as one you'll plug in. Neighbouring cradles on one edge merge and share one cap.
- **Mating plug size**: measure the plug's body (the moulded part you hold), not the metal tip. **Reset to type** puts back the type's size.
- The plug's type, direction and height above the board.

Tick several ports to set them together, or click a cradle in the 3D view. **Copy this board's plug settings to** puts them on other boards (the ones of its own kind are ticked).

**Cables** at the top of the step: **In the app**, or **Off: holders and plug covers only**. With cables off, nothing is routed, drawn, tagged, listed or bought as a cable, and Plugs becomes a list of each board's ports, each "plug in it" or empty: those you mark get a cradle and cap. Your cables are kept for when you switch back on. It is in the command palette too.

The rest of the Plugs step (Auto-connect, the cable list, **Debug and serial**) is under [Cables](#cables-and-the-wiring-view) and [J-Links](#j-links-and-serial-adapters).

## The Holder step

Per board:
- **Holder style**: **Frame** (the default) or **Tray**. The style cards show your own board's holder in each style, in 3D. See [design.md](design.md#the-holder) for what each is.
- **Preset**: **Sturdy** (full tray, thick walls), **Balanced** (frame, the default) or **Lean** (thin frame, fastest print).
- **Material**: PETG by default. The Check step judges every spring against your material's limit.
- **Release button**: **Centred** (the default: the button sits in the middle of the holder's far edge, and the spine that carries its rod runs under the board, which sits about 10 mm up), **Beside the board** (the spine, grip bar and button run beside the board, so it sits low and the far edge stays free for plugs), or **Automatic** (whichever keeps the plugs clear with the least plastic). Plugs always win: if the button would block one, it moves, and the section names the plug.

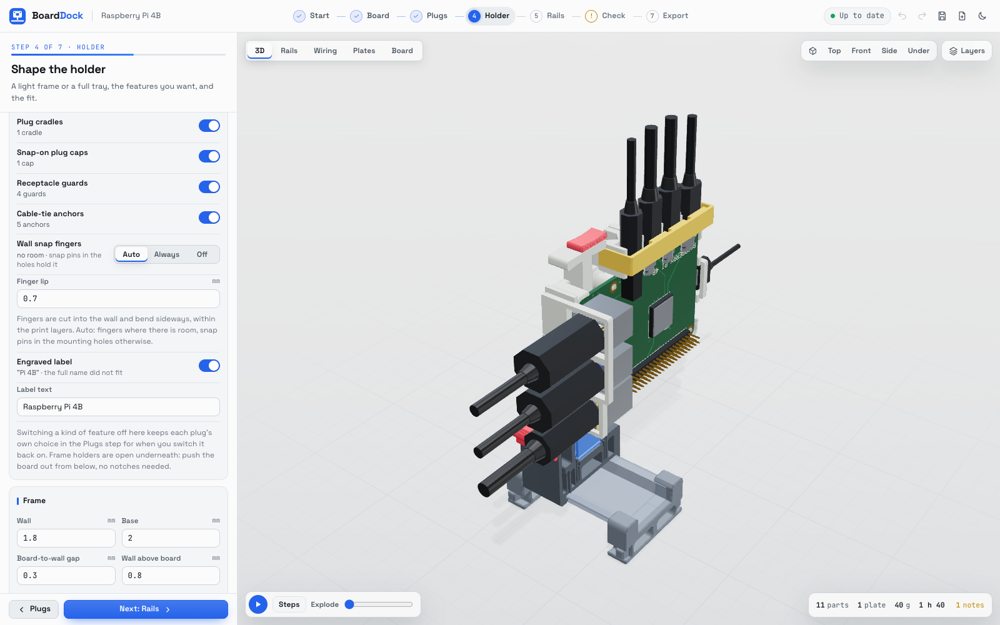
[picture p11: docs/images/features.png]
Holder features, each with what it did


*(This picture predates 3.1.0: today the clips row is **Spring clips hold the board**, and only ports in use have cradles.)*

**Features** has one row per feature with what this holder actually got, so a switch never silently does nothing:
- **Plug cradles**, **Snap-on plug caps**, **Receptacle guards** and **Cable-tie anchors**, each with how many (caps clip onto cradles, so they need them). Switching a kind off here keeps each plug's own choice for when you switch it back on.
- **Spring clips hold the board**, with a **Firm** / **Gentle** switch for how hard the board presses in. It says how many spring clips and fixed ledges the board got, and, when clips don't fit, why. See [how the board is held](design.md#how-the-board-is-held).
- **Engraved label**: the board's name by default. If it doesn't fit a free wall it is shortened to a form that still says which board it is ("Raspberry Pi 4B" becomes "Pi 4B", "Raspberry Pi Zero 2 W" becomes "Pi Zero", never just "2 W"). Your own words are never cut. It only gives way to the spring clips if that actually gives them room.
- **Finger notches** on a tray. A frame is open underneath: pull a clip back and push the board out from below.

A box sits in low guards and is strapped down, so it has no clips, notches or label.

**Copy these settings to** puts this holder's options (style, sizes, features, material, colour) on the other boards of its kind, on every board, or, with **Copy to…**, on the boards you tick. One undo step.

## The Rails step

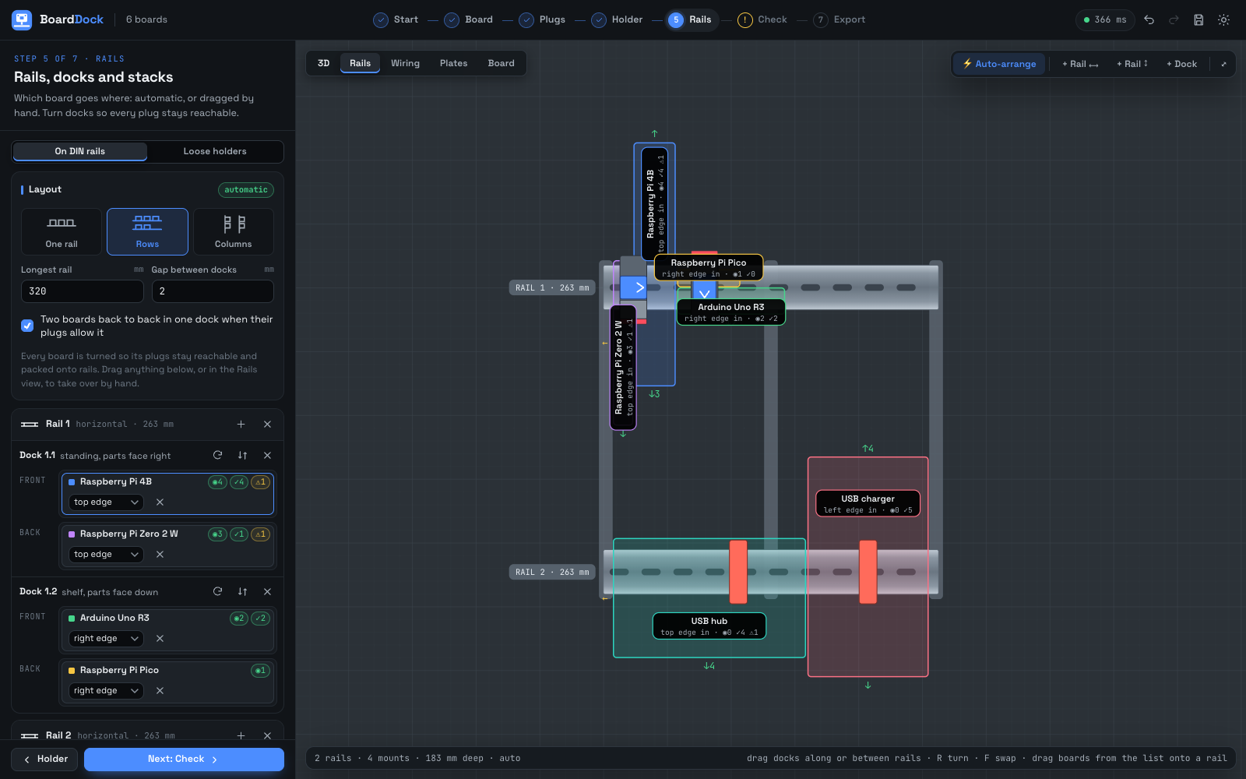
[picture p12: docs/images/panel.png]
Rails step


At the top: **On DIN rails** or **Loose holders** (see [Loose holders](#loose-holders)).

The Rails step shows the whole rack as a tree: rails, docks, the front and back slot of each dock, and stacked boards under the board they sit on. Chips show where the plugs point, and each dock's label says how its boards sit (standing, lying flat, or a mix). Drag a board onto:
- a slot, to seat it there;
- a rail, for a new dock at its end;
- another board, to stack it (see [Stacks and columns](#stacks-and-columns));
- **+ Rail**, for a new rail with it;
- the tray, to take it off the rails.

Quick layouts are **one rail**, **rows** (a new rail when one gets longer than your limit) and **columns** (vertical rails). You don't have to drag (on a touch screen a board drags by its grip): **Share a dock with…** puts a board in another board's free slot, back to back, and **Put behind…** fills an empty back slot.

**Lock and changes** locks the whole layout, or one dock or rail. Auto-arrange, Tidy up, docks sliding to make room and Auto-connect leave what is locked where it is, and new boards go elsewhere. Each automatic change writes a receipt (**Changes made for you**), and ⌘Z takes back the change and its line together.

**Fit and spacing** has **Tongue fit (looser +)**: raise it by 0.05 to 0.1 mm if the test-fit kit's key is tight.

### Standing up or lying flat

**Boards in their docks** sets it for the whole rack:
- **Stand up** (the default) takes the least rail.
- **Lie flat** stands far less out of the wall (a Pi, Uno, Pico and ESP32 rack: about 72 mm instead of 163 mm), and headers point straight out at you, but each board takes its width of rail.
- **Whichever suits each** lays a board flat only where that keeps its plugs clearly easier to reach, and says which boards it laid flat.

A small table under it compares the choices you have tried on this rack: rails and their length, how far it stands out from the wall, and cable to buy. Each slot also has its own **stands / lies flat** toggle in the Rails list and in the dock's inspector. How a flat board docks is in [design.md](design.md#lying-flat).

### The Rails view

The **Rails** view shows the rack from above: rails, table stands, docks, and every board's footprint. Arrows show where each board's plugs point:

| Mark | Meaning |
|---|---|
| **◉** | faces you, easy to reach |
| **✓** | reachable from the side |
| **⚠** | points at the next dock |
| **✕** | points into the table or wall |

**Overlaps** between neighbours are hatched red. The Check step lists the rails to cut and how tall the rack stands.

### Auto-arrange

**Auto-arrange** is on by default:
- It tries every dock edge and all four turns for each board, and picks the one with the best plug access. It never lets a plug point into the table, keeps the release button clear of plugs, and prefers boards that stick out less.
- It pairs boards back to back in one dock when that costs nothing in plug access.
- It packs the docks along the rail by their real 3D size, including plugs, cradles and buttons, and starts a new rail when one gets longer than your limit. Boxes such as hubs and chargers get a rail of their own.
- It orders, turns and rows the docks for their cables: a planner scores layouts on cable length, crossings, cables under rails, plugs blocked by a neighbour, ribbon length and rail used, then checks the best one or two with the real cable router. On 13 test racks it cut cable by 23%, the longest cable by 24% and crossings from 87 to 18, against rails about a third longer (the **Compact** goal turns that round). It takes under a second for 16 boards; the first build of a big rack takes longer, and the pick is remembered.
- It keeps each holder's tongue under the limit Check holds it to: a long board is docked by an edge that gives a shorter lever, and a board that can't stand on any edge without failing lies flat instead. For a tongue over its limit, the Rails tree has a button to dock it by another edge (or lay it flat) when that fixes it.
- Settings: rail direction, longest rail, gap between docks, space between rails, and pairing on or off.

**Options**, beside the button: probes beside their board and stacked in one column, a goal (**Balanced**, **Compact**, **Short cables**, **Easy to reach**), like boards grouped and turned alike, mains kept at one end, hosts near their devices, room to grow on each rail, back-to-back pairing, cables that fit stock lengths, hot boards spread out, and fewest printed parts. Each is a weight on the same score, not a separate rule. **Pack new boards only** places boards you have just added and leaves every other dock and rail where it is.

Changing how a board docks slides the docks after it along the rail to make room; where it now reaches over the next rail's docks, that rail and the ones beyond slide across. With Auto-arrange on, every change lays the rack out again, a new cable too. When that adds a rail, moves a board to another rail or adds 30 cm or more of cable to buy, a toast says so and offers **Keep the old layout**. On a built rack, Auto-arrange asks first.

### Editing by hand

The first edit keeps everything where it is and switches to manual. A dock dropped on top of another slides to the nearest gap beside it, and a dock a board leaves empty goes. **Tidy up** takes out empty docks and slides overlapping docks apart along their rail.

| Action | How |
|---|---|
| Move a dock along its rail | drag it, or the arrow keys (Shift = 10 mm) |
| Move a dock to another rail | drag it onto that rail |
| Move a rail | drag the rail |
| Turn a dock 90° | **R** (Shift+R turns the other way) |
| Swap front and back boards | **F** |
| Select several docks | Shift-click, or drag a box; ⌘A selects all |
| Remove | Delete |
| Put a board on the panel | drag it from the board list onto a rail (new dock) or onto a dock (shares it back to back) |

The inspector sets: dock or flat clip; which side of the rail the release lever is on; the turn, with a picture of each; rail and position; the board in each slot; which board edge goes into the dock, or Auto; and the rail's direction, position and length (fixed, or cut to fit).

## Stacks and columns

A board can sit on top of another; the bottom one carries the dock. In the Rails step, drag a board onto another board, or use the **Stacks** section: pick the board in **Stack a board** and where it goes in **Stack on…**. A stacked board's row then says what it sits on, how (**Bolted on standoffs**, **Printed layer** or **On its edge**), and has **Take off the stack** to give it a dock of its own again.

- **Bolted on standoffs:** a HAT on a Pi, a shield on an Arduino. The top board is lined up on the holes the two share. BoardDock picks the shortest standard standoff that clears what is under the top board (11 mm, a HAT's, at the least); type your own length if you like, and Check says if it is too short. The row says how many standoffs and screws, and their size.
- **Printed layer:** a separate board on its own light holder, pressed onto four corner towers on the holder below.
- **On its edge (a column):** small boards, up to about 105 × 60 mm (a J-Link, a USB-serial adapter, a Pico, a Nano…), stand on their long edges, one on top of the other like bricks. Each lifts straight off on its own, and one press on the top button frees the whole column from the rail.

Bolted is chosen when at least two holes line up; you can switch it. Only sensible targets are offered: boards about as big or bigger, and never a hub, charger or powerboard. A small board can go on another small board in a column; a J-Link or an adapter only ever goes in a column.

**The column rule.** In a column, every board, the bottom one too, stands on the long edge that keeps its plugs to the side: below the top, a plug pointing up the column would sit where the holder above stands. A board that can't avoid it (a Pi Zero, with all its plugs on one long edge) gets a **Plug up the column** line in Check. To fix it, put that board at the top of its column (Rails › **Stacks**), or stand it on its other long edge in the Rails step.

The rack holds a column to what the dock's tongue can bear: in PETG, a J-Link and an adapter fit in one column, and two J-Links do not. How the stacks are built is in [design.md](design.md#stacks-and-columns).

## Boxes, power and powerboards

A box is a size and rows of ports (Board step, **Box**). Pick a preset (USB hub, powered 7-port hub, USB-C hub with Ethernet, USB charger, USB charger with USB-C, network switch, PoE network switch, plug-pack supplies) or set your own:
- length, width and height; its **corners** seen from above (square, rounded, or cut off); its **colour** in the 3D view;
- rows of ports, each on its own card: how many, which type (USB-A, USB-C, micro-USB, USB-B, DC barrel, mains, RJ45, HDMI, audio, screw terminals), on which face, and what they are for (hub port, upstream, power out, DC out, power in…);
- for ports that give power, what each one gives (a 27 W USB-C PD port gives 5 A, most USB-C charger ports 3 A), and a DC port's voltage;
- a plug pack's own lead length, and a powerboard's rating (A, from its label).

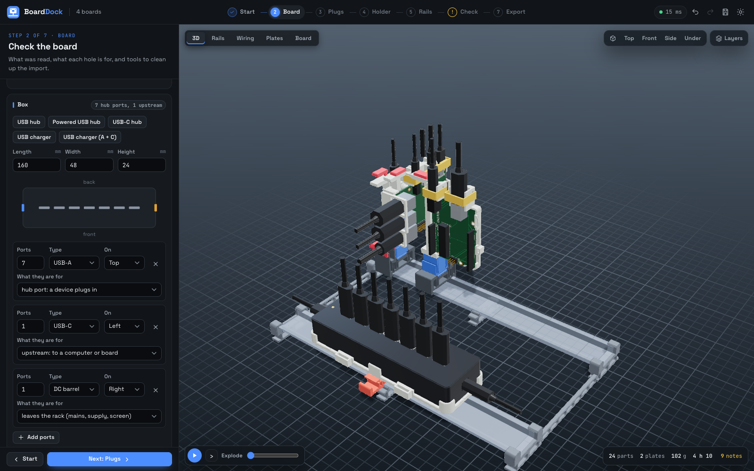
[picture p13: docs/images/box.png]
Box editor with a 7-port powered hub


By default a row's ports are spaced evenly and centred on their face. Under **Where they are** on each card you can match your box exactly: along the face (centred, from the left or right end, or each port where you put it), the spacing, the height up the side, which way up (named by what you see in the socket), and for ports on top, where and at what angle (45° lets plug packs sit side by side).

A live sketch above the cards shows the box from above and each side with ports as you see it. The editor says when ports don't fit their face, overlap, or sit higher or lower than the box. A box is held down by a 12 mm hook-and-loop strap through four loops on its holder, placed where the strap misses every plug (or zip-tie loops where no gap is wide enough). A box longer than your printer's bed (a powerboard usually is) gets its holder in two halves that meet end to end, each clipped to the rail on its own.

### Build your own box

On Start, **Draw your own › A box** builds one from scratch: a USB hub, a USB charger or a power supply, with its name, size and colour. It starts with a typical port or two for its kind; change them under **Box**, then drag each port in the editor to where it is on yours. **Save to My boards** keeps it for any rack. None of the box holders has been printed yet: check a test print against your box.

### Plug packs

The Raspberry Pi 27 W (5 A) and 15 W (3 A) USB-C supplies and a 12 V DC plug pack plug straight into a powerboard's outlet, so they stay off the rails and get no holder; their own lead goes to the board, drawn from the outlet and checked against its length (1.2 m on the 27 W supply, 1.5 m on the 15 W one and the 12 V pack). A DC pack only goes to a DC input on its own when both say the same voltage. BoardDock can't check polarity, so check both labels.

### Power

The Plugs step counts what still needs a port: USB devices against free hub and computer ports, and boards that need power against free ports strong enough for them. A board on a port too weak for it still counts as needing power, so the offer to add a charger (or, for Pi 5s, their own 27 W supplies) stays until every board has enough. A USB device with no port on the rack can go to **your computer**. Boards with screw terminals or jumper headers and nothing connected (a relay board, a power distribution board) are listed too: Auto-connect leaves wiring to you.

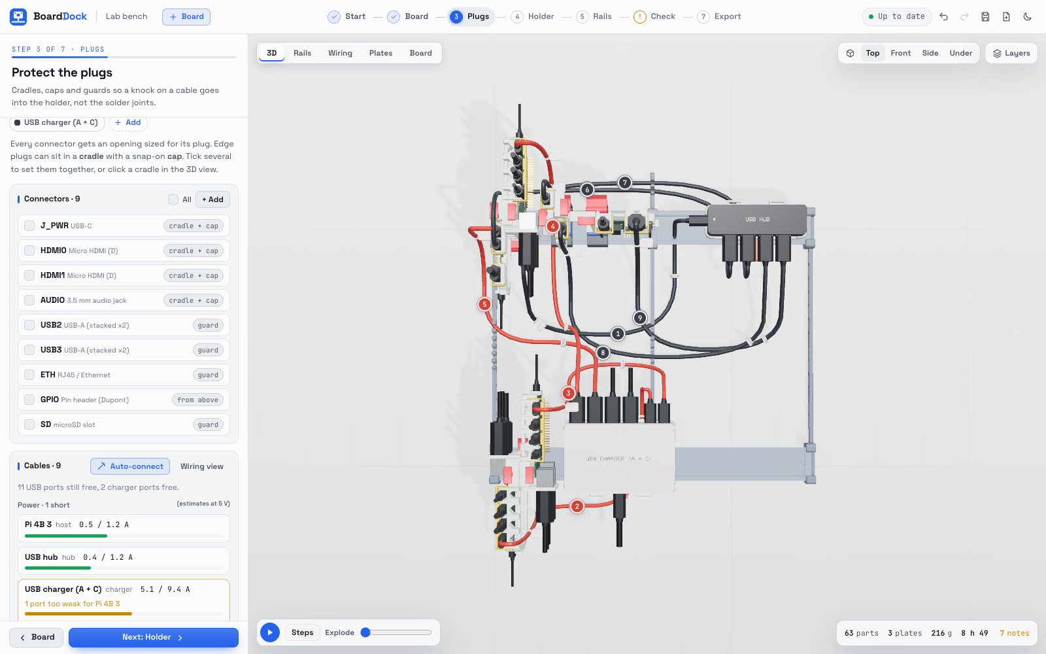
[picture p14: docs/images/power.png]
Power budget in the Plugs step


*(The budget bars are current; the sidebar in this picture predates 3.1.0.)*

**Power budget.** Every charger, powered hub, bus-powered hub and Raspberry Pi USB port gets a bar: what the boards on it take at full load against what it gives, at 5 V. It warns when a charger is asked for too much, when a Pi's four USB ports (1.2 A between them) or an unpowered hub carry too much, and when a board needs more than its port gives (a Pi 4 wants 3 A; a USB-A charger port gives about 2.4 A). A Pi 5 wants 5 A, which only a 5 A USB-C PD supply gives: on a 3 A port it runs, but holds its USB ports to 0.6 A between them. **Move boards to stronger ports** fixes what it can in one undo step.

Each powerboard gets a **mains** bar: what the supplies on it draw from the wall at full load (at about 85% efficiency) against its rating (typical: AU 10 A, UK 13 A, US 15 A, EU 16 A; set yours under **Box**). A PoE switch gets a bar for its PoE budget. The figures are estimates: set a board's own under **Board › Power** and a charger's total under **Box**. Check lists the same.

### Powerboards

Powerboards (power strips) are boxes too: 4 or 6 outlets, switched, angled 45° for plug packs, or with two USB ports. Set the outlets (AU/NZ, UK, US or EU), how many, their angle and the size under **Box**. Auto-connect plugs each charger's mains lead into a free outlet. A powerboard's own lead goes to the wall: BoardDock never plugs one powerboard into another, and won't put a mains outlet onto screw terminals (mains through relays belongs in a proper enclosure, wired by someone qualified). It checks which plug goes where and adds up the load it knows about; it can't check your powerboard, its lead, earth or the wall socket.

## Cables and the Wiring view

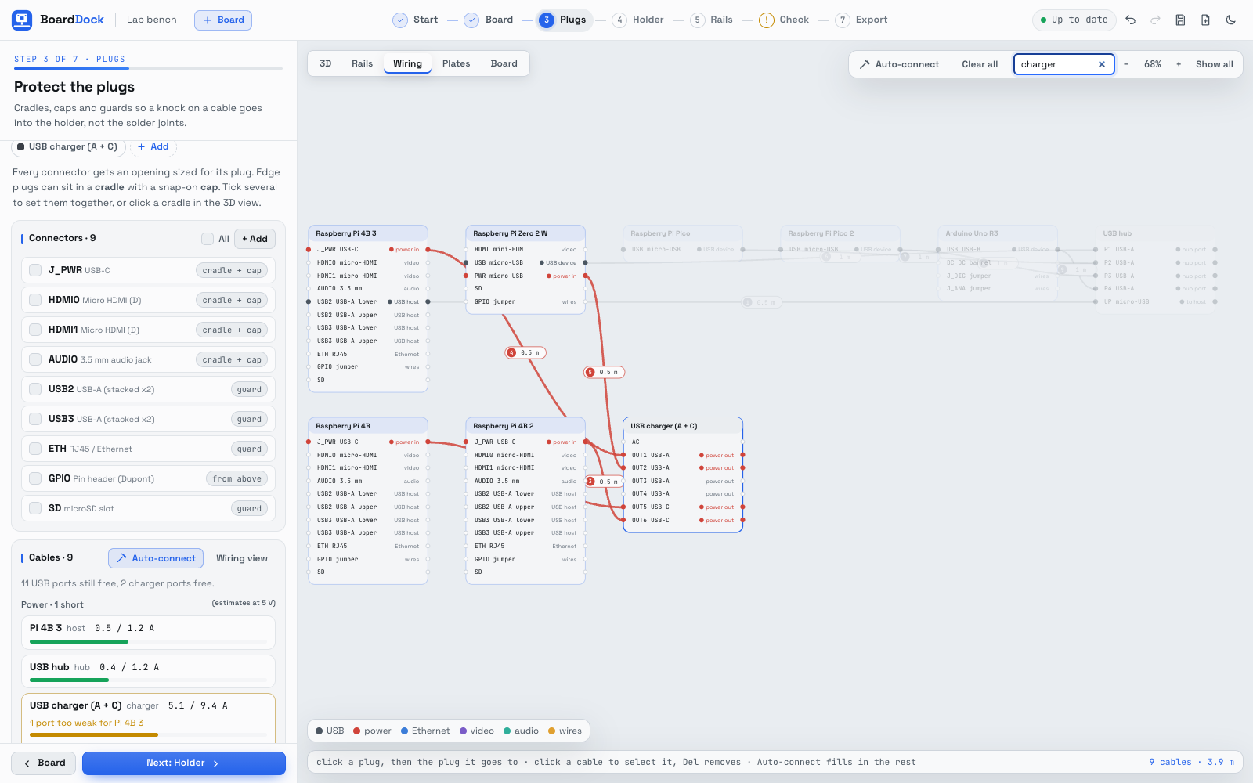
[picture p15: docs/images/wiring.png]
Wiring view


Each plug gets a role from its type, its name and its board:
- a Raspberry Pi's USB-A ports are hosts, and its USB-C is its power input (or its Ethernet, with **PoE HAT fitted** under Board › Power);
- an Arduino's USB-B is a device, and its barrel jack is an optional input that takes only 7 to 12 V;
- a hub's ports feed devices;
- a charger's ports give power, and a PoE switch's PoE ports give it over Ethernet.

**Auto-connect** pairs the free plugs the way you would, and says why it chose each one (hover a cable, or see the Cables list). In order:
1. hubs to the nearest computer or board that hosts them, else to **your computer**;
2. power: a board with a PoE HAT from a free PoE port with budget left; every other board only from a port that gives it enough, with no charger loaded past what it gives. A powered hub's port will do for a small board, never a Pi;
3. devices (an Arduino's USB, a probe's or adapter's USB) to the nearest hub port, else a board's own USB port while their shared limit allows, else **your computer** (its 2 m cable is on the shopping list);
4. each board's Ethernet to a **network switch**, and each switch to **your router**, off the rack (the shopping list asks you to measure that cable);
5. a DC plug pack to a DC input of the same voltage (for an Arduino's jack, the pack nearest 9 V). A switch or powered hub with nothing on its DC input gets a To do line, and **Add its supply** puts that plug pack on the rack;
6. mains leads and plug packs to the nearest free outlet of a powerboard;
7. J-Links and serial adapters to the headers they serve.

Each kind is paired all at once, the cheapest pairing in all, by how long each cable would be as the rack is laid out. Leaving Plugs with **Next** on a rack with no cables runs Auto-connect first (⌘Z undoes it). **Rewire** chooses Auto-connect's cables again after you move boards, and leaves the ones you connected yourself. In the Plugs step, pick **Cable to** for any plug.

The Plugs step's **Cables to buy** and the shopping list use the same wording and lengths. Under Plugs › Cables, **Buy every Ethernet lead at one length** rounds them all up to the longest one's stock length.

**In the Wiring view:**
- **Drag** from a plug to the plug it goes to, or onto a board (it takes that board's best free plug that fits). Plugs that fit light up green.
- **Click** a plug for its **best matches**, each with how long the cable would be and what the port gives.
- **Drag a plug that already has a cable** to move that end (it keeps its number).
- After you connect one by hand, **Connect N more like this** does the same for boards like it.
- The list's **To do** tab says what still needs a cable, with the best match and a **Connect** button for each, and what the rack is short of (charger ports, hub ports, a switch), with a button to add one. **Complete this rack** is at its top. **Cables** lists every cable with its number, its ends, what it is and its length.

The Wiring view is a canvas: pinch (or ⌘ + scroll) zooms, dragging the background pans, and the percentage button fits everything in. Drag a card by its title; it stays where you put it. **Arrange…** lays the cards out again, as the cables flow or as the boards stand on the rails. **Find a board** shows just one board's cables.

A pin header (▸) opens into its pins, with their net names from your KiCad file. Click a pin, then a pin on another header, to add a jumper wire (ground black, supply red). A wire onto pins ends in a female housing; into a pin socket it ends in a male pin, drawn and bought that way. Click a wire and press Delete to take just that one off.

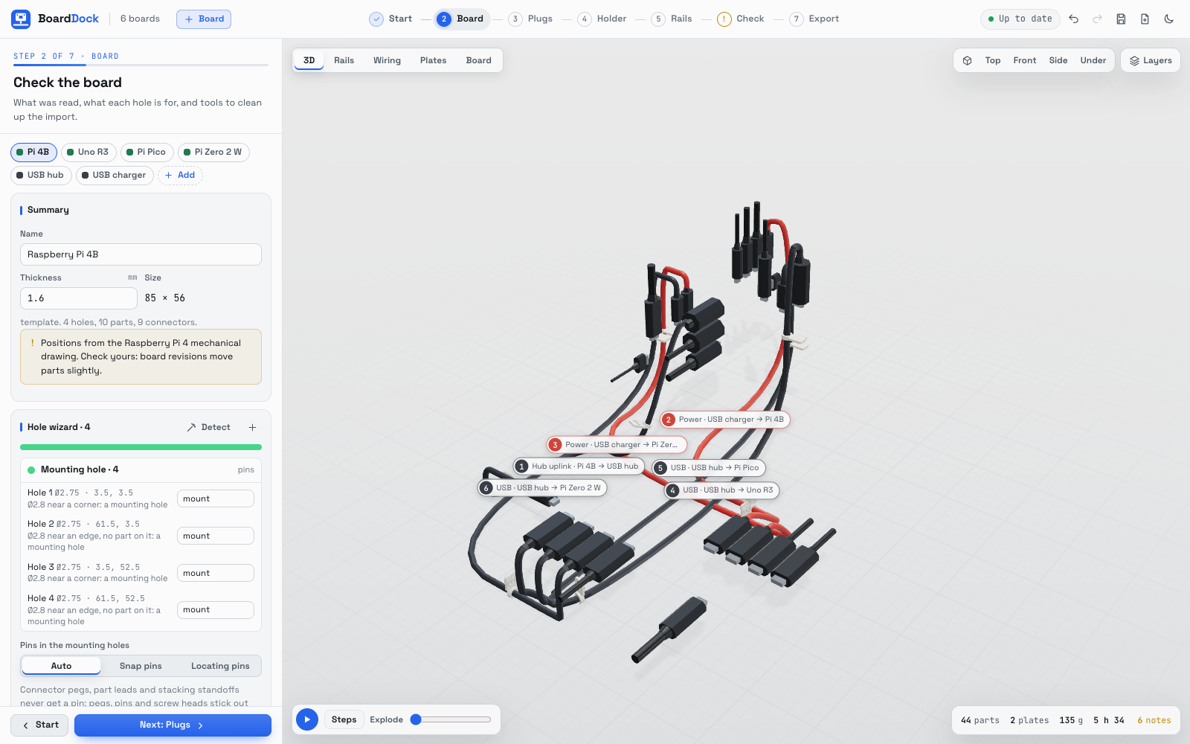
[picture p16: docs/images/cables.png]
Cable numbers and tags


**Every cable has a number**, and keeps it: adding or removing others never renumbers it. The number and what the cable is for ("Power: USB charger → Pi 4B") show on a badge in the 3D view (**Layers › Cable numbers** hides them), in the Wiring view, in the cable list, the shopping list and the assembly steps. **Numbered cable tags** print with the rack, two per cable, each held on by a 2.5 mm zip tie (the ties are on the shopping list); switch them off in the Plugs step. How cables are routed and the tags are made is in [design.md](design.md#cable-routing).

## J-Links and serial adapters

A board's debug headers are found on import: by shape (a 2 × 5 header at 1.27 mm, Tag-Connect pads) or by name (a 10 or 20-pin header whose reference, value or footprint says SWD, JTAG or debug). UART headers are found by name (UART, serial, console, FTDI, TX/RX). To mark any other part, select it and choose **Debug / UART…**.

**J-Links and adapters are ordinary boards**, docked and cabled like any board. Each stands on its long edge in a column (see [Stacks and columns](#stacks-and-columns)). Auto-arrange puts a board's first J-Link and adapter in the back slot of its dock, right behind it, and further ones in docks of their own beside it.

**One press adds what's missing.** On the Plugs step, **Debug and serial** lists every header with its probe, ribbon length (one click sets a short ribbon to the next standard length), dock slot and where pin 1 is. **Add 3 J-Links + 2 adapters** (the numbers are your rack's) gives each free debug header a J-Link with the right connector and each free UART header a USB-serial adapter, docked beside their board and cabled, in one undo step. **+ J-Link** and **Adapter** on a header's row do just that one. **Bench sheet** prints it all on one page.

- **A J-Link** is a board (65 × 40 × 1.6 mm) with a 20-pin 1.27 mm Cortex connector and a USB-B. Its ribbon loops over the top and down to its header, checked against its length (200 mm unless you set yours) and never on the shopping list. For other headers the list has the adapter to buy. Draw your own as a board and set **It is** to a debug probe.
- **A USB-serial adapter** is the FT232RL board (36 × 18 mm, mini-USB, six pins). Jumper wires go from its pins to the UART header, crossed over (its TXD to the board's RX), bought by the wire. A female header gets male-ended wires. Pin names guessed from a header's size say to check yours.
- **Or a serial cable:** a USB to TTL serial cable (3.3 V, loose jumper ends) from a free hub or computer port to each free UART header: black on GND, green on the board's RX, white on its TX, red left off.

On a rack laid out by hand or built, a new J-Link or adapter goes into the free back slot of its board's dock (else the nearest free slot, else a new dock), and the toast says which. Check warns about jumper wires longer than 30 cm and a ribbon longer than its length. A second J-Link for one board needs a ribbon of about 250 mm. The examples to try are **Example: dual-MCU board…** and **Example: sensor board…** in the library, and as KiCad files in `examples/`. None of this has been printed yet.

## The 3D view

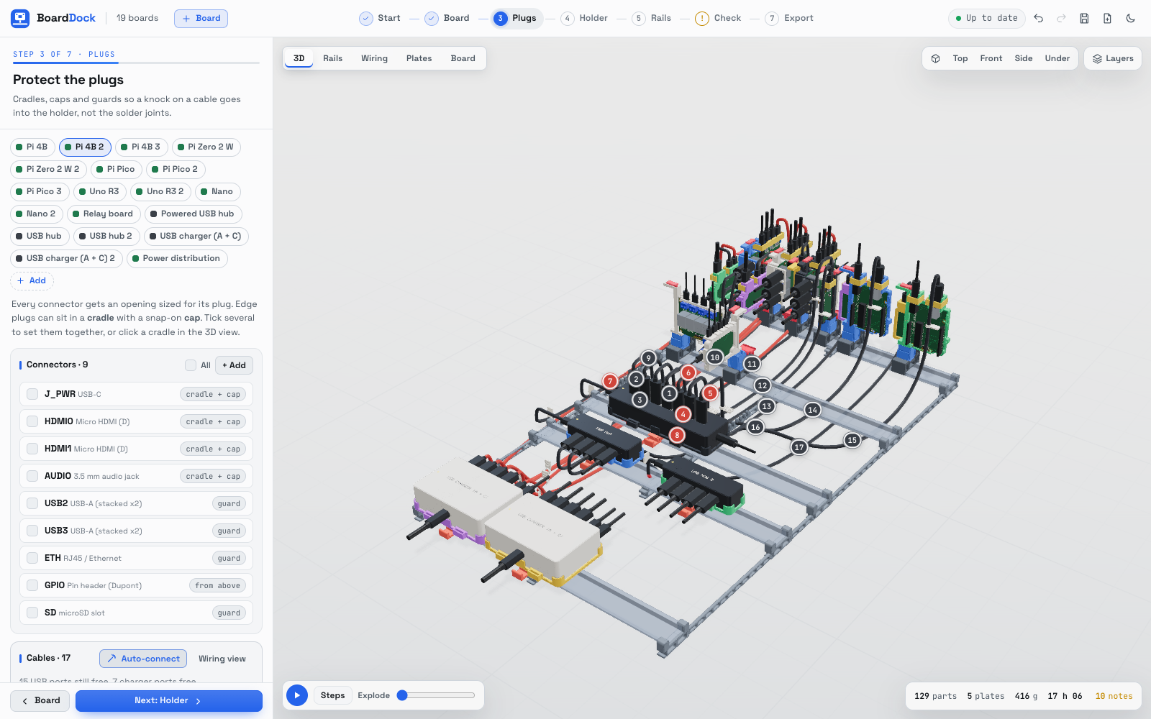
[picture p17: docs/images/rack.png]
The 3D view


| Action | How |
|---|---|
| See what something is | hover over it |
| Select a board, dock, rail, cable, table stand, or one holder feature (cradle, cap, pin, spring clip, guard, tie anchor, label, stand socket) | click it |
| Select several | Shift-click |
| Remove the selection (a cradle or cap is switched off, a pin becomes an ignored hole, a dock, rail or cable is removed, a board leaves the project, table stands are switched off) | Delete, or **Remove** in the bar below the view; one ⌘Z brings it all back |
| Jump to the settings of the selected thing | **Edit** in the bar |
| Change how a board is mounted | pick the board or its dock: **Stands up** or **Lies flat**, which edge goes in the dock, turn the dock, swap its boards; with loose holders, the DIN clip and how it sits |
| Fly to a part | double-click it |
| Watch it go together | the play button; **‹ ›** step back and forward, **✕** shows it assembled; on a built rack, **Only what's new** |
| Build it at the bench | **Guide** |
| Pull it apart | the **Explode** slider |
| Show or hide holders, docks, caps, boards, plugs, cables, cable numbers or rails | **Layers** |
| Look at one thing | **Isolate** hides everything else; **X-ray** makes the rest see-through; **Esc** leaves |
| See what changed since the build | **What's new** tints the new parts, cables and boards |
| See where the mains is | **Mains zones** shades a 10 mm margin round each mains board |
| Turn a part, a box port or a dock | the **rotation box**: type an angle, or turn by 15°, 45° or 90° |
| Find any action or step | **Ctrl/Cmd+K** (on a phone, the search button) |
| See every keyboard shortcut | **?** |
| Go to a step | **1** to **7** |

**Boards** show a solder mask with copper traces and vias (their own from KiCad files, old binary Eagle boards and Allegro boards read through KiCad; a decorative pattern on every other board), silkscreen, pads, chips with their part numbers, passives, LEDs and switches. Rails are slotted metal DIN rail, and printed parts show their layer lines.

**Plugs** are drawn after their type, and only where one goes: a cable to another board on the rack, a port in use off the rack (a screen, a supply), or a box's own supply. A free port stays empty, and unused ports get no cradle. A lead that leaves the rack is drawn as a short stretch that fades into a dotted line saying where it goes ("to a screen", "to the wall").

**Cables** are translucent tubes, coloured by kind (a colour-blind safe set, with a key under the view's tabs). The one you pick or hover stands out. They bend in arcs of about four diameters, as real ones do.

**Live** (in the bar, on by default) switches the rack on: LEDs glow and do what they do, a board with no power stays dark, and pulses run along the cables the way power or data goes. It is only for the look: whether each board gets enough power is the Power check's job. It holds still if your system asks for reduced motion.

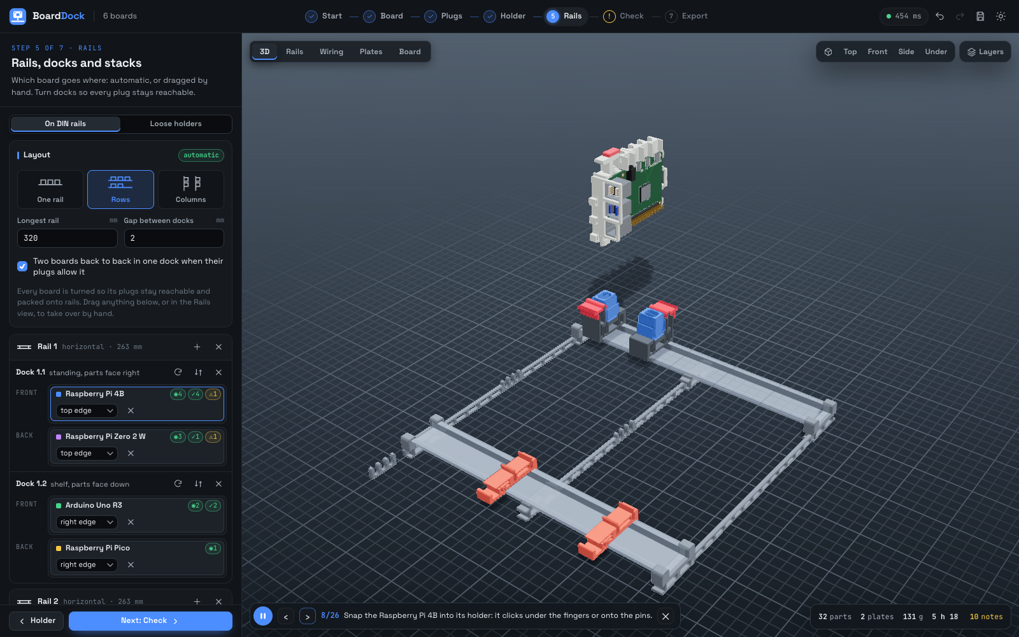
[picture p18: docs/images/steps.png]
Stepping through the assembly


*(This picture predates 3.1.0: the step now says the board clicks under the spring clips.)*

**Steps** plays the assembly the way you would do it: stands, rails, shoes and sockets; then for each board its release rod, the board into its holder (tipped in under the spring clips and pressed down), anything stacked on it, and the holder into its dock; then the cables (power first, mains last), the caps, and a last step: check every screw terminal, switch the powerboards off, plug them into the wall, then switch on.

**Guide** is the same steps for the bench: a big card says which step you are on and plays it; **Back**, **Again** and **Next** (or ← → and Esc) are big enough for a thumb. **Print** takes a picture after each step, with its new parts outlined in blue, and prints them with the words and the bill of materials (or save it as a PDF).

## A new version of a board

When a new revision of one of your boards comes out, select it and press **New version…**, or drop its files on that button. The new version takes the old one's place:
- it keeps its name, dock, stack, holder settings and every cable to a plug it still has;
- the choices made on the old one carry over where the part is still there: plug cradles, caps, guards and tie anchors, hidden parts, and holes set by hand;
- what changed is listed ("Connectors: J2 moved 2 mm; J4 new (USB-C)", or "No mechanical changes: the holder comes out the same").

If the new version makes something fail in Check that did not before, the toast and the board's list of changes say so.

To put a **different** board in a board's place (an Arduino Mega for an Uno), press **Replace with…** on its card and pick one, or drop its files. It keeps the old one's dock, stack, holder settings and the cables to plugs it also has.

**Print its holder** goes straight to Export with just that board; on a built rack, **What's new** lists its new parts and the old holder as spare. One ⌘Z goes back to the old version.

## Coming back to add a board

Once the rack is built, press **Mark the rack as built** in Export. BoardDock remembers what you printed, the rail lengths you cut and the cables you bought, and freezes the layout.

Later, a saved rack opens on **Your rack**, with its boards and buttons for the rails, the cables and what's new to print. Drop the new board's files in. It goes:
1. into the empty slot of a dock already on the rack, if it fits there with all its plugs reachable and touches nothing (then only its holder is new);
2. otherwise into the first gap on the rails that is clear in 3D, preferably on the rail of a board it is cabled to;
3. otherwise on the end of a rail, and Export says that rail has to be longer.

Nothing else moves. Connect its cables (Auto-connect only fills plugs that are still free). Export then lists what to do since the build:

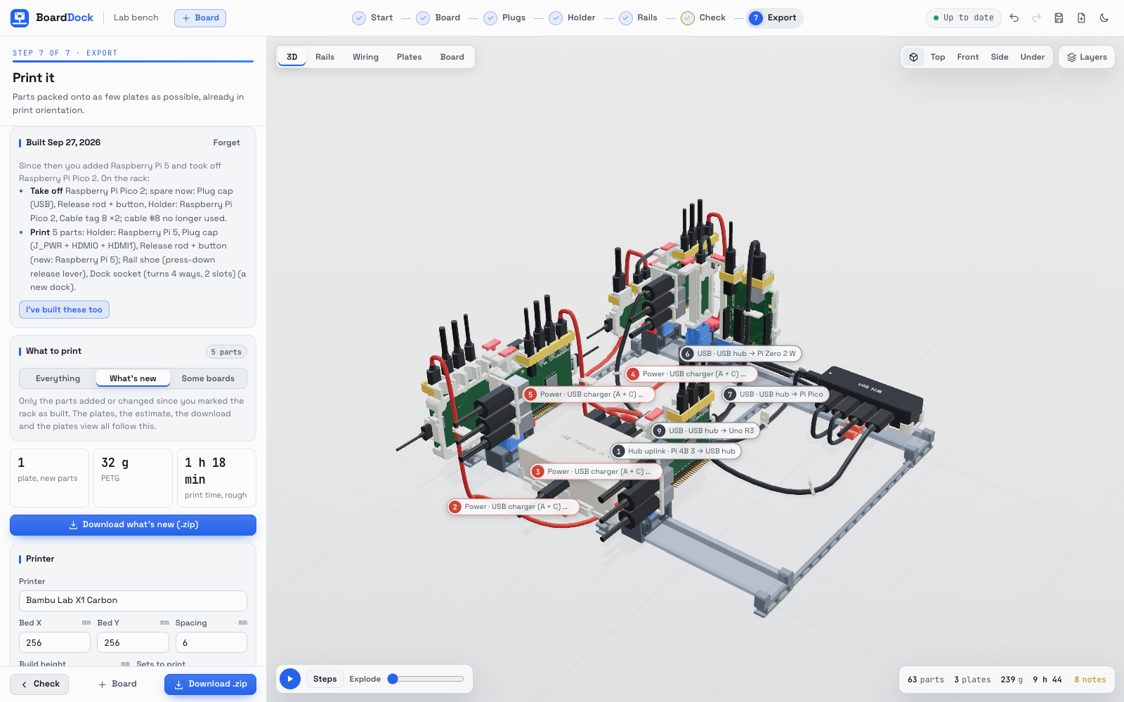
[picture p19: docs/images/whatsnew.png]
What changed since the rack was built


It is a numbered checklist in the order you would work, each step with the parts to print for it: **Take off** removed boards; **Swap** a board for its new version; **Cut** a rail that has to be longer and **move the end block**; **Slide** a built dock to its new place; **Move** boards that now sit elsewhere; **Clip on** each new dock; **Seat** each new board; **Plug in** the new cables (and say when one you have is now too short); and what is **spare** now.

Plates, the estimate and the download follow it. Press **I've built these too** when you have. **Forget**, by the Built heading, asks first, then forgets the build (⌘Z undoes it).

## Loose holders

Choose **Loose holders** at the top of the Rails step (**On DIN rails** / **Loose holders**) for holders without a rail dock:
- **stacked** on corner towers with press-fit pegs;
- **side by side** with printed link bars;
- **back to back**, joined by a pin through both bases and a U clip that slides onto its neck.

Each holder can also have a flat pull-tab **DIN rail clip** (off to start with: tick it if you have a rail) or a **stand socket** (a round, square, hex or D-shaped post, or a 1/4"-20 tripod nut trap). The joints are described in [design.md](design.md#loose-holder-joints).

- A stack never covers a box: hubs, chargers and powerboards stand beside it on the table. Plug packs get no holder.
- A board bolted onto another gets a standoff on each hole the two share and a screw in each end (M2.5 for a Pi, M3 for an Arduino); the Rails step says how many.
- Cables between loose holders aren't routed or sized: each plug gets a short cut-off tail in 3D, Check says so, and the shopping list asks you to measure them on your bench.

| Stacked | Side by side |
|---|---|
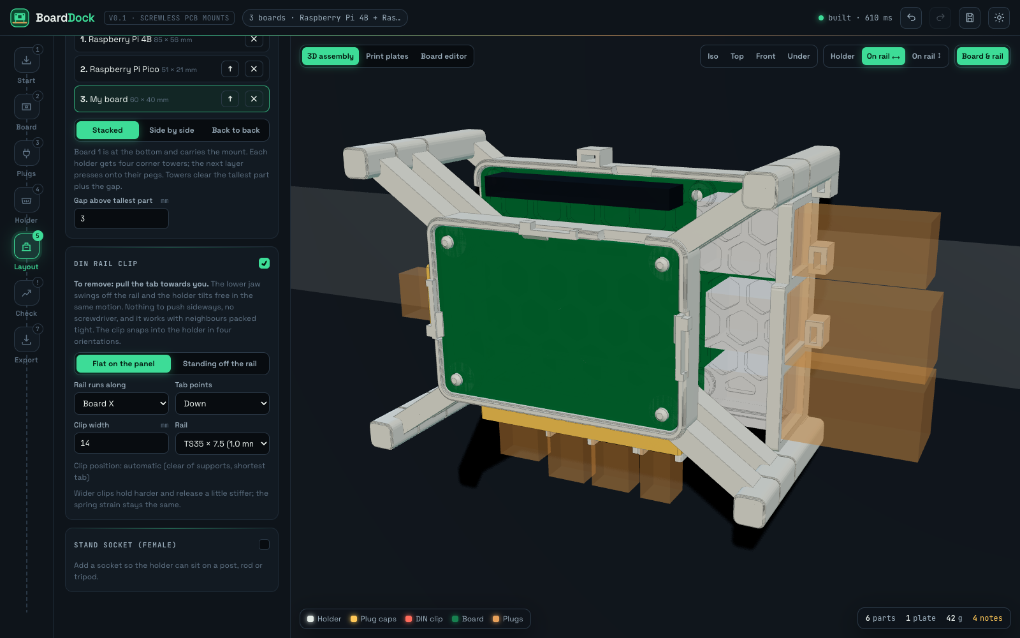
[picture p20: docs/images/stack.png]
Stacked
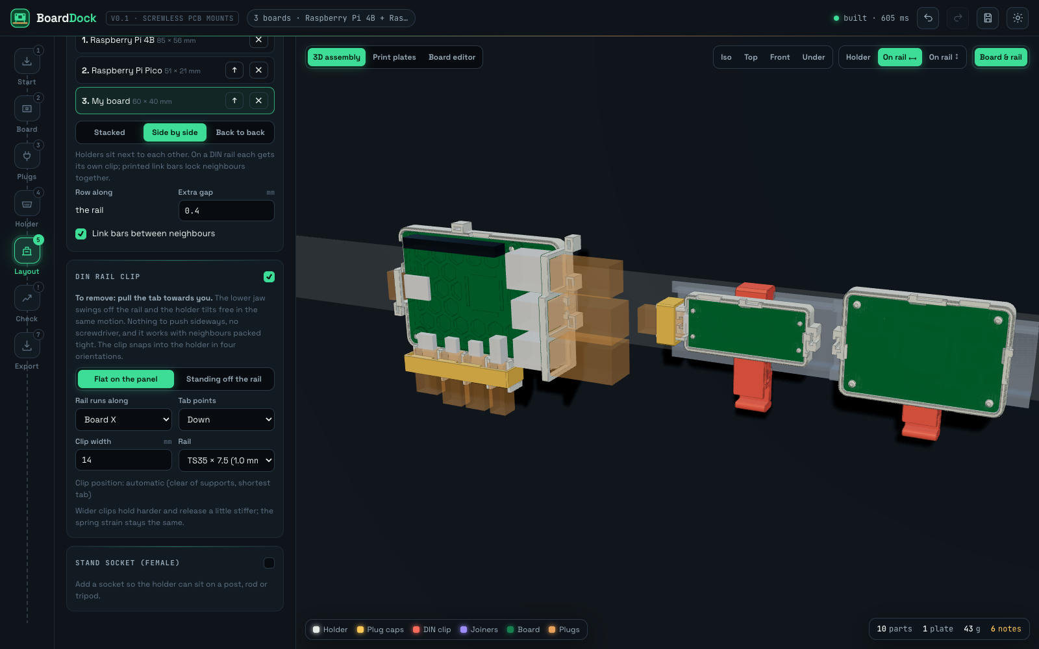
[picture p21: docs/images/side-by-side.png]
Side by side
|  |  |

*(These two pictures show an early version of the app and its holders.)*

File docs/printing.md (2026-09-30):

# Printing and export

Everything in the Export step: what to print first, the material, your printer and its settings, G-code, and what to buy. Back to the [README](../README.md).

Contents:
- [The test-fit kit](#the-test-fit-kit)
- [Material and printer](#material-and-printer)
- [Print settings](#print-settings)
- [What to print](#what-to-print)
- [G-code in the app](#g-code-in-the-app)
- [G-code in your own slicer](#g-code-in-your-own-slicer)
- [Supports: none](#supports-none)
- [What the slicers do with it](#what-the-slicers-do-with-it)
- [What to buy, and building it](#what-to-buy-and-building-it)

## The test-fit kit

Print this before anything else. **Test-fit kit · print this first** in Export gives one rail shoe, one socket and a small tongue key with its release rod: about 30 to 40 minutes of printing, with no supports.

1. Clip the shoe on your rail and press the socket into it.
2. Push the release rod into the key until it clicks, then push the key into the socket until the latch clicks.
3. Press the key's button and lift it out.

If the key is tight, raise **Tongue fit (looser +)** under Rails › **Fit and spacing** by 0.05 to 0.1 mm and print the kit again. The first time the key goes in, the two crush ribs on its tongue flatten to fit, so that push is firmer than the ones after.

## Material and printer

- **Material: PETG.** Every dock part is a spring. PLA is stiffer and more brittle, so strains that are fine in PETG are marginal in PLA (the Nano's short hairpins are over the limit in PLA). The Check step judges each part against your material's limit.
- **Printer:** pick yours in Export (or under **Your printer** on Start). The list has 18: Bambu Lab X1 Carbon, P1S, A1 and A1 mini; Prusa CORE One, MK4S, MK3S+, MINI+ and XL; Creality K1C, Ender-3 V3 SE and Ender-3 S1; Voron 2.4 and Trident; Elegoo Neptune 4 Pro; Anycubic Kobra 3; Sovol SV06; and Qidi Q1 Pro. Bed size and build height come from the machine profiles in [OrcaSlicer's open profile library](https://github.com/OrcaSlicer/OrcaSlicer/tree/main/resources/profiles). Parts are packed onto that bed, and any part taller than the build height is flagged.

## Print settings

Export lists what to set in your slicer for your printer and material. Each setting shows where to find it in OrcaSlicer, Bambu Studio or PrusaSlicer, and is marked by where it comes from:
- **design:** the parts need it. For example 0.45 mm wall lines (the rail shoe's hinge is exactly two of them), 0.2 mm layers, no supports.
- **profile:** OrcaSlicer's generic filament profile (for PETG: 255 °C nozzle, 80 °C bed, 20 to 100% fan, 10 mm³/s), or your printer's machine profile (retraction).
- **convention:** common practice, not a tested requirement. For example 3 walls, detect thin walls off, aligned seam, and a brim only for parts more than three times taller than they are wide.

The list also says what brim and skirt the slicer lays. **Copy** puts it on the clipboard, and the download's README has it too.

## What to print

Everything, only what's new since you built the rack, or just the boards you tick (with or without their docks and the table stands). The plates, the estimate (grams and print time per part), the download and the plates view all follow the choice. Each plate downloads as binary STL or 3MF.

## G-code in the app

Once your printer's start code is known, the main button, **Slice and download all G-code (.zip)**, slices every plate and downloads the lot, and **Download everything** can include the G-code. **Slice** next to a plate does just that plate. [Kiri:Moto](https://grid.space/kiri/) (MIT, by Stewart Allen) slices it inside BoardDock with the settings above and your filament's temperatures, and shows the print time, the grams and each layer. You get a `.gcode` file, or a `.gcode.3mf` for Bambu Lab printers.

- **Start and end code** comes from Kiri:Moto's own profile where it has one: Bambu Lab P1S and A1, Prusa MK3S+ and MINI, and Creality K1. Two printers use a close one, marked as such: the Creality K1C uses the K1's, and the Bambu Lab X1 Carbon the P1S's (Kiri:Moto has no X1 Carbon profile; watch the start of the first print). BoardDock swaps the A1 and K1 profiles' fixed PLA temperatures for your filament's. Other printers get a plain start (heat, home, purge line) for Marlin or Klipper, marked as such. You can paste your own for any printer under **Start and end G-code**. The Prusa XL is left to PrusaSlicer.
- **Start code you bring is checked** before it is kept: not empty, heating the bed and the nozzle, homing, no end code or slicer layers in it, temperatures within the printer's limits, moves that stay on the bed and under the printer's height, and not another printer's. Code that can't be used isn't kept, and the page says why. Code that only looks odd is kept once you read why and choose **Use it anyway**. The check can't tell that code is right for a printer, only that it isn't obviously wrong.
- **Bambu Lab printers, the A1 mini among them, can use their own start code.** BoardDock doesn't ship it (it is Bambu's), so bring it from your own copy of Bambu Studio or OrcaSlicer: the desktop app reads it from the slicer's install folder, or open the printer's `… template machine_start_gcode.json`, `… machine_end_gcode.json` and `… layer_change_gcode.json` from the slicer's `profiles/BBL/machine` folder, or paste them from the printer's settings in the slicer. BoardDock fills it in for each plate in Bambu's own template language and writes a `.gcode.3mf` for the SD card. If the code uses a setting BoardDock doesn't know yet, it says which and doesn't slice. Checked against the A1 mini's code; not yet run on a printer.
- **Brims and the bed's edge:** parts on a plate are always far enough apart for two brims, and plates keep 4 mm clear round the bed's edge for the skirt or brim. A part too big for that margin but small enough for the bed gets a plate to itself; a plate with no room for a skirt or brim is sliced without one and says so.
- Kiri:Moto is not the slicer the settings were written for. It has no first-layer (elephant-foot) compensation, and its speeds are set conservatively.

## G-code in your own slicer

Every plate is also a 3MF with all its parts placed. Open it in OrcaSlicer, PrusaSlicer, Bambu Studio or Cura with the settings above. In the desktop app, **Open plate** hands it to whichever of them is installed. Your printer maker's slicer knows its quirks best.

## Supports: none

Overhangs are 45° chamfers, gables or short bridges; round and square holes on their side have 45° tops; the spring clips stand on the bed (their lip's ledge is 0.9 to 1.3 mm); and all springs flex within their print layers. The Check step shows it layer by layer (see [design.md](design.md#printability-layer-by-layer)), and **Overhangs** on the print plates paints faces that would need support in red and bridges in amber. Leave supports off in any slicer.

## What the slicers do with it

- **The tongue hole.** The socket prints standing on its end, so the tongue's pocket lies on its side. Its roof is chamfered at 45° and the centre divider halves it, so the longest bridge in the socket is about 2.3 mm. The pocket leaves 0.2 mm round the 14 × 4.5 mm tongue. If yours prints tight, raise **Tongue fit** in the Rails step.
- **Print-in-place parts.** The rail shoe's lever prints round its pin, 0.35 mm clear, and every slicer keeps the ring and the pin as separate loops. The socket's latch nose has 0.45 mm round it in its window. Don't lower the line width or raise the flow for these parts.
- **Bridges.** OrcaSlicer and PrusaSlicer spot bridges, slow down, and lay the lines across the gap with the fan up. Kiri:Moto prints them as ordinary solid layers, so expect a little more sag on the longest bridges (9 mm on a flat-lying holder, 14.4 mm in a DIN plate's slots; see [limits.md](limits.md)).
- **Thin walls.** With thin-wall detection off (so the 0.9 mm hinge stays two full lines), walls under about 0.4 mm are left out: in BoardDock parts, only fine label detail.

## What to buy, and building it

- **The shopping list** has the rail lengths, the cables (length and plug types; jumper wires by the wire; what comes with a part, like a probe's ribbon or a plug pack's lead, is not to buy), the zip ties for the cable tags, straps and standoffs. The Plugs step's **Cables to buy** is the same list.
- **The Bill of materials** lists everything the rack is made of, with how many: printed parts (and what one weighs), boards, boxes and probes, rails, cables, hardware, filament and tools. **CSV** saves it (`BOM.csv` in the download).
- **The Checklist** (on Start and beside the shopping list) lists what to buy, print and have to hand, to tick off as you go. It follows the rack as it is now; the ticks are saved in the project, and a tick whose line has gone goes too.
- **The download's README** has the assembly steps and the print settings. The 3D view's play button and **Guide** show the same steps (see [guide.md](guide.md#the-3d-view)).
- When the rack is built, press **Mark the rack as built** in Export, so a board added later brings only its new parts (see [guide.md](guide.md#coming-back-to-add-a-board)).

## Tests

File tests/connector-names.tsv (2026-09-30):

# Footprint / part names as boards carry them, and the connector type each is. Columns: type, name, then a reference (J1 when left out)
# and a value. "?" marks a name nothing identifies yet (a connector that stays Custom); "-" a part that is no connector at all.
b2b | SAMTEC_QSH-030-01-L-D-A
b2b | QSH-060-01-L-D-A-K-TR
b2b | SAMTEC_QTH-030-01-L-D-A
b2b | QSE-040-01-F-D-A
b2b | QTE040
b2b | SEAM-50-02.0-S-08-2-A-K-TR
b2b | SEAF-50-05.0-S-08-2-A-K-TR
b2b | ERM8-013-05.0-S-DV-L-TR
b2b | ERF8-025-05.0-S-DV-L
b2b | BSH-030-01-L-D-A
b2b | LSHM-120-02.5-L-DV-A-S-TR
b2b | Samtec_FMC_ASP-134486-01_10x40_P1.27mm_Vertical
b2b | Samtec_MECF-20-01-L-DV_2x20_P1.27mm_Polarized_Socket_Horizontal
b2b | HIROSE_DF12(3.0)-40DP-0.5V(81)
b2b | DF12E3.0-80DP-0.5V
b2b | DF40C-60DP-0.4V(51)
b2b | DF40HC(3.5)-60DS-0.4V(51)
b2b | BM23FR0.6-16DP-0.35V
b2b | Hirose_BM24_BM24-40DP-2-0.35V_2x20_P0.35mm_PowerPin2_Vertical
b2b | FX8-100P-SV
b2b | Molex_SlimStack_52991-0408_2x20_P0.50mm_Vertical
b2b | MOLEX_501920-4001
b2b | SLIMSTACK_502426-4010
b2b | MEZZANINE_2X30
header | SAMTEC_TSW-110-07-L-S
header | TSW-105-07-G-D
header | SSW-105-02-G-D
header | SAMTEC_HLE-110-02-G-DV-A
header | TSM-106-01-L-DV
header | SULLINS_PBC03SAAN
header | PPTC062LFBN-RC
header | PRPC040SAAN-RC
header | HARWIN_M20-9990345
header | M50-3600542
header | WURTH_61300411121
header | WR-PHD_613006216921
header | MILL-MAX_310-93-110-41-001000
header | 801-87-002-10-001101
header | ADAM_TECH_PH1-06-UA
header | PH2-10-UA
header | 3M_929834-01-05-RB
header | PINHEADER_2X05_P2.54MM_VERTICAL
header | PinHeader_1x04_P2.54mm_Vertical
header | PinSocket_2x08_P2.54mm_Vertical
header | HDRV10W64P254_1X10_2540X254X850B
header | HDRRA10W64P254_1X10_2540X254X850B
header | CONN_2X5_2.54
header | CON_1X4_2.54MM
header | HDR_1X10_2.54
header | PINHD-1X4
header | SIP4
header | Harwin_LTek-Male_02_P2.00mm_Vertical
header | Harwin_Gecko-G125-FVX0605L0X_2x03_P1.25mm_Vertical
header | JAE_LY20-10P-DT1_2x05_P2.00mm_Vertical
header | Molex_Picoflex_90325-0004_2x02_P1.27mm_Vertical
swd10 | SAMTEC_FTSH-105-01-L-DV-K
swd10 | Connector_PinHeader_1.27mm:PinHeader_2x05_P1.27mm_Vertical
cortex20 | FTSH-110-01-L-DV-K
tagconnect | TC2030-IDC-NL
microfit | MOLEX_43045-0400
microfit | 43650-0600
microfit | Molex_Micro-Fit_3.0_43045-0800_2x04_P3.00mm_Vertical
minifit | MOLEX_39-28-1043
minifit | 5566-12A
minifit | Molex_Mini-Fit_Jr_5566-06A_2x03_P4.20mm_Vertical
minifit | TE_MATE-N-LOK_1-770182-x_3x03_P4.14mm_Vertical
minifit | ATX_24PIN
kk254 | MOLEX_22-27-2041
kk254 | 22-23-2041
kk254 | KK254_1X04
kk254 | TE_640456-2
kk254 | TE_826576-2_1x02_P3.96mm_Vertical
kk254 | JST_B4P-VH
kk254 | JST_VH_B2P3-VH_1x02_P7.92mm_Vertical
kk254 | Molex_KK-396_A-41791-0004_1x04_P3.96mm_Vertical
kk254 | FAN_HEADER_4P
picoblade | MOLEX_53047-0410
picoblade | Molex_PicoBlade_53398-0271_1x02-1MP_P1.25mm_Vertical
picoblade | Hirose_DF13-04P-1.25DSA
picoblade | DF13C_CL535-0402-2-51
wtb_side | MOLEX_53048-0410
wtb_side | JST_SM04B-GHS-TB
wtb_side | S4B-PH-K-S
wtb_side | S12B-PH-SM4-TB
wtb_side | S02B-XASK-1
wtb_side | JST_S6B-EH
wtb_side | Molex_Pico-Clasp_501331-0407_1x04-1MP_P1.00mm_Horizontal
wtb_side | Stocko_MKS_1651-6-0-202_1x2_P2.50mm_Horizontal
jst_xh | JST_B2B-XH-A
jst_xh | B4B-XH-A(LF)(SN)
jst_xh | B12B-XH-A
jst_xh | B6B-EH-A
jst_xh | B02B-XASK-1
jst_xh | Hirose_DF1B-3P-2.5DSA
jst_xh | Stocko_MKS_1651-6-0-202_1x2_P2.50mm_Vertical
jst_xh | Molex_SPOX_5267-02A_1x02_P2.50mm_Vertical
jst_ph | B3B-PH-K-S
jst_ph | B12B-PH-K-S
jst_ph | B4B-PH-SM4-TB
jst_ph | JST_PH_B2B-PH-K_1x02_P2.00mm_Vertical
jst_ph | B08B-PUDSS
jst_ph | Hirose_DF3-2P-2DSA
jst_ph | Molex_MicroClasp_55932-0210_1x02_P2.00mm_Vertical
jst_ph | NS-Tech_Grove_1x04_P2mm_Vertical
jst_gh | BM04B-GHS-TBT
jst_gh | JST_GH_BM06B-GHS-TBT_1x06-1MP_P1.25mm_Vertical
jst_gh | BM02B-SURS-TF
jst_gh | JST_ACH_BM01B-ACHSS-A-GAN-ETF_1x01-1MP_P1.20mm_Vertical
jst_zh | B4B-ZR
jst_zh | JST_ZE_B02B-ZESK-1D_1x02_P1.50mm_Vertical
jst_zh | Wuerth_WR-WTB_64800211622_1x02_P1.50mm_Vertical
jst_zh | WR-WTB_64800411622
qwiic | SM04B-SRSS-TB
qwiic | SM12B-SRSS-TB
qwiic | BM04B-SRSS-TB
qwiic | STEMMA_QT
usb_c | USB_C_Receptacle_HRO_TYPE-C-31-M-12
usb_c | GCT_USB4105-GF-A
usb_c | USB4085-GF-A
usb_c | AMPHENOL_12401610E4#2A
usb_c | MOLEX_105450-0101
usb_c | USB-C_16P
usb_c | TYPE-C-31-M-17
usb_micro_b | MOLEX_105017-0001
usb_micro_b | 47346-0001
usb_micro_b | USB_Micro-B_Amphenol_10118194-0001LF_Horizontal
usb_micro_b | FCI_10103594-0001LF
usb_micro_b | WURTH_629105150521
usb_micro_b | ZX62-B-5PA
usb_micro_b | MICRO_USB_B
usb_mini_b | USB_Mini-B_Lumberg_2486_01_Horizontal
usb_mini_b | WURTH_65100516121
usb_mini_b | UX60-MB-5ST
usb_mini_b | MINI_USB_B
usb_a | MOLEX_67643-0910
usb_a | 48037-2200
usb_a | TE_292303-7
usb_a | WURTH_614004134726
usb_a | KYCON_KUSBX-AS1N-B
usb_a | USB_A_HORIZONTAL
usb_a | USB3_A_RECEPTACLE
usb_a_dual | USB_A_STACKED_X2
usb_a_dual | CUI_UJ2-A2
usb_b | TE_5787834-1
usb_b | USB_B_Lumberg_2411_02_Horizontal
usb_b | USB-B_VERTICAL
usb_b | USB_B_OST_USB-B1HSxx_Horizontal
hdmi_a | AMPHENOL_10029449-111LF
hdmi_a | MOLEX_47151-0001
hdmi_a | HDMI_A_Molex_208658-1001_Horizontal
hdmi_a | HDMI_TYPE_A
hdmi_micro | MOLEX_46765-0001
hdmi_micro | HDMI_MICRO_D
hdmi_mini | HDMI_MINI_C
dp | MOLEX_47272-0001
dp | DISPLAYPORT_CONN
rj45 | HR911105A
rj45 | BEL_A829-1A1T-91B
rj45 | RJ45_Bel_SI-60062-F
rj45 | RJMG1BD3B8K1ANR
rj45 | AMPHENOL_RJHSE-5380
rj45 | MAGJACK_8P8C
rj45 | ETHERNET_RJ45
rj11 | RJ12_Amphenol_54601-x06_Horizontal
rj11 | RJ11_6P4C
dsub | DSUB-9_Female_Horizontal_P2.77x2.84mm_EdgePinOffset4.94mm_Housed_MountingHolesOffset4.94mm
dsub | DE9S
dsub | DB25_MALE_RA
dsub | D-SUB_15_HD
dsub | SUB-D_9P
barrel | CUI_PJ-102AH
barrel | PJ-002A
barrel | PJ-063AH
barrel | CUI_CP-002A
barrel | WURTH_694106106102
barrel | KYCON_KLDX-0202-XC
barrel | SWITCHCRAFT_RAPC722X
barrel | GCT_DCJ200-10-A
barrel | DC_JACK_2.1MM
barrel | BarrelJack_Horizontal
audio35 | PJ-320A
audio35 | CUI_SJ1-3523N
audio35 | SJ-3524-SMT
audio35 | KYCON_STX-3120-3N
audio35 | KYCON_KPJX-4S-S
audio35 | CUI_MJ-3523-SMT
audio35 | 35RAPC4BH3
audio35 | Jack_3.5mm_PJ31060-I_Horizontal
audio35 | AUDIO_JACK_3.5MM
rca | RCJ-014
rca | RCA_JACK_HORIZONTAL
rca | PHONO_JACK
microsd | DM3AT-SF-PEJM5
microsd | DM3D-SF
microsd | MOLEX_104031-0811
microsd | MOLEX_47219-2001
microsd | WURTH_693072010801
microsd | GCT_MEM2075-00-140-01-A
microsd | MICROSD_SLOT
microsd | TF-01A
sd | SD_TE_2041021
sd | SD_Kyocera_145638009511859+
sd | HIROSE_DM1AA-SF-PEJ21
sd | SD_CARD_SLOT
sim | NANO_SIM
sim | GCT_SIM8060-6-0-14-00
sim | microSIM_JAE_SF53S006VCBR2000
sim | SIM_CARD_HOLDER
bnc | BNC_Amphenol_031-6575_Horizontal
bnc | BNC_RA_PCB
sma | SMA_Amphenol_132289_EdgeMount
sma | AMPHENOL_132134
sma | MOLEX_73251-1153
sma | SAMTEC_SMA-J-P-H-ST-EM1
sma | RP-SMA_JACK
ufl | U.FL-R-SMT-1
ufl | IPEX_MHF4
rf_mini | MMCX_Molex_73415-0961_Horizontal_0.8mm-PCB
rf_mini | MMCX_JACK
xt60 | XT60-M
xt60 | AMASS_XT60PW-M
xt30 | XT30PW-M
xt30 | AMASS_XT30U-F_1x02_P5.0mm_Vertical
terminal | PHOENIX_1757242
terminal | PhoenixContact_MSTBA_2,5_4-G-5,08_1x04_P5.08mm_Horizontal
terminal | MKDS_1,5_2-5,08
terminal | PHOENIX_1729128
terminal | PhoenixContact_MC_1,5_3-GF-3.81_1x03_P3.81mm_Horizontal
terminal | WAGO_2601-3102
terminal | Wago_734-132_1x02_P3.50mm_Vertical
terminal | WURTH_691137710002
terminal | TE_282834-2
terminal | TERMINALBLOCK_5.08MM_2P
terminal | TB_2P_5.08
terminal | Molex_Sabre_43160-0102_1x02_P7.49mm_Vertical
fpc | FH12-24S-0.5SH(55)
fpc | Hirose_FH12-30S-0.5SH_1x30-1MP_P0.50mm_Horizontal
fpc | MOLEX_52559-2052
fpc | MOLEX_54132-5033
fpc | MOLEX_502231-1500
fpc | TE_1-1734839-5
fpc | JAE_FF0825SA1_2Rows-25Pins_P0.40mm_Horizontal
fpc | FFC_30P_0.5MM
fpc | FPC-24P-0.5
fpc | ZIF_40P
fpc | CSI_CAMERA_CONN
idc | 3M_N2510-6002
idc | IDC-Header_2x05_P2.54mm_Vertical
idc | BOX_HEADER_2X8
idc | SHROUDED_HEADER_2X5
idc | CNC_3020-10-0100-00
idc_ra | CNC_3020-10-0200-00
idc_ra | IDC-Header_2x05_P2.54mm_Horizontal
sata | SATA_7P
sata | MOLEX_67800-8001
sata | FCI_10029364-001LF
sfp | SFP_CAGE
sfp | SFP+
minidin | MINIDIN_6
minidin | PS2_MINI_DIN
minidin | CUI_MD-60S
minidin | KYCON_KMDGX-6S-B4
xlr | NEUTRIK_NC3FAH
xlr | NC3MAH-0
xlr | NC5FBH
xlr | XLR_3P
xlr | MiniXLR-5_Switchcraft_TRAPC_Horizontal
banana | BANANA_JACK
banana | Banana_Cliff_FCR7350B_S16N-PC_Horizontal
banana | CalTest_CT3151
banana | BINDING_POST
m12 | M12_4P
m12 | AMPHENOL_M12A-04PFFP-SF8001
m12 | Amphenol_M8S-03PMMR-SF8001
toslink | TOSLINK_RX
toslink | Toshiba_TORX173
pcie | PCIE_X1
pcie | BUS_PCIexpress_x16
m2 | M.2_KEY_M
m2 | NGFF_KEY_E
m2 | BUS_PCI_Express_Mini_Half
m2 | JAE_MM60-EZH039-B1
dimm | SODIMM_DDR4
dimm | DDR3_DIMM
pogo | POGO_PIN
pogo | MILL-MAX_0906-2-15-20-75-14-11-0
pogo | SpringContact_Harwin_S1941-46R
? | DIN41612_C_2x32_Male_Horizontal_THT
? | DIN41612_B_2x16_Female_Vertical_THT
? | DTF13-12Px
? | CF-Card_3M_N7E50-7516PK-20-WF
? | BUS_AT
? | Pin_D1.0mm_L10.0mm
? | SolderWire-0.25sqmm_1x02_P4.2mm_D0.65mm_OD2mm
? | CUI_PD-30
? | IHI_B6A-PCB-45_Vertical
? | CoaxialSwitch_Hirose_MS-156C3_Horizontal
? | GB042-34S-H10
? | CUSTOM_CONN_XYZ
- | SOIC-8_3.9x4.9mm_P1.27mm | U1
- | TSSOP-20_4.4x6.5mm_P0.65mm | U2
- | QFN-32-1EP_5x5mm_P0.5mm | U3
- | LQFP-48_7x7mm_P0.5mm | U4
- | SOT-23-5 | U5
- | SOT-223-3_TabPin2 | U6
- | TO-252-2 | Q1
- | R_0402_1005Metric | R1
- | C_0603_1608Metric | C1
- | C_1206_3216Metric | C2
- | L_0805_2012Metric | L1
- | LED_0603_1608Metric | D1
- | D_SOD-123 | D2
- | D_SMA | D3
- | DO-214AC_SMA | D4
- | D_SMB | D5
- | SMBJ5.0A | D6
- | CRYSTAL_SMD_3225-4P | Y1
- | SW_PUSH_6mm | SW1
- | ESP32-WROOM-32 | U7
- | HDMI_ESD_TPD12S016 | U8
- | TRS3232 | U9
- | USB2514B | U10
- | USB3300-EZK | U11
- | USBLC6-2SC6 | U12
- | CP2102N-A02-GQFN28 | U13
- | FT232RL | U14
- | STUSB4500 | U15
- | CH340G | U16
- | MAX3232 | U17
- | TPS62130 | U18
- | QSE15x | U19
- | MD-3030 | L2
- | DINRailAdapter_3xM3_PhoenixContact_1201578 | MH1
- | Symbol_Barrel_Polarity | U20
- | Fuse_1812_4532Metric | F1
- | Crystal_HC49-4H_Vertical | Y2
- | Buzzer_12x9.5RM7.6 | BZ1
- | Relay_THT_Omron_G5LE | K1
- | Battery_CR2032 | BT1
- | Transformer_THT_Pulse | T1
- | RF_Shielding_Laird_BMI-S-101 | SH1
- | Potentiometer_THT_Bourns_3296W | RV1
- | SIM800L | U21
- | SIM7600E | U22
- | RFM95W | U23
- | SMA | D7
- | DO-201AD | D8
- | PLCC-44 | U24
- | VSSOP-8_3.0x3.0mm_P0.65mm | U25
- | BGA-256_17x17mm | U26
- | DFN-8-1EP_3x3mm | U27
- | PWR_LED | D10

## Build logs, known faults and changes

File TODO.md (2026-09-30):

# To do

(Working note: keep usage low: few agents, few browser runs.)

What still needs doing on BoardDock, most serious first within each part. New requests go on this list first. What was on the list before v3.0.0 and got done is in `.github/release-notes/v3.0.0.md`.

One rack from v3.0.0 has been printed: the DIN rail clip worked; the release button's hole, the snap pins, the socket latch and the tongue stoppers didn't, and 3.1.0 changes them. Nothing from 3.1.0 has been reprinted, so anything below about fit, strength or clips is from the model and its checks, not from a real print.

## 1. Needs a print, a real board or a real screen

- Reprint with 3.1.0: the release button through its hole, the socket latch's hold (a 20 N pull), the tongue's crush ribs (they replace the anti-rattle leaves and the stop post), the spring clips, hairpins and ledge on a real board, the cable-tag saddles on their zip ties, the back-to-back rivet clip. Still untried from before: the peg fit and crush ribs of a J-Link + adapter column, the long release rod, the slot for an unclippable board, the tongue under a column.
- The user's own Allegro board through KiCad: which parts still come in as Custom connector, and what KiCad keeps as footprint name and value from an Allegro symbol (the names were checked only against KiCad's library and naming guides). The USB-serial adapter's male pins against the jumpers' female ends: confirm with the user where they saw female sockets.
- The 3D view on a real GPU: the translucent cables and the power streaks (headless software rendering showed them only as dots), Live off hiding the streaks straight away, and the page freezes (import, first 3D view, adding a hub with the 3D view open: measured 29 Sep on software rendering, not profiled on a GPU; builds are now cached).
- "Wires bend unnaturally, all of a sudden" (seen in v0.2.0): two likely causes found (bends clamped to half of each short leg at corners; settling used to cut corners across streets, now kept to the planned path). Needs a repro from the user.
- The optional Claude job for `boards/` and `parts/` pull requests has not been run (it needs the repository's `ANTHROPIC_API_KEY` secret and a `boards` or `parts` label).

## 2. Open, in code

- Severity 2: two boards that mate on a board-to-board connector aren't one stack; put them in one by hand (Rails › Stacks › Stack on…), with the mated height (Samtec QSH about 5 mm, Hirose DF40 about 1.5 mm).
- Severity 2: connector sizes still typical, with no public drawing found: M.2 socket, PCIe slot depth and height, full-size DIMM, pogo pads, M12, RCA, DisplayPort, mini HDMI, Qwiic, and every connector's plug (`{w,h,len,cable}`). The makers' sites are blocked by this environment's network policy; KiCad's library (a public GitHub clone) was the source for the rest.
- Severity 2: not recognised yet: DIN 41612 backplane connectors (no type), Switchcraft, Hirschmann, Lumberg and Keystone jacks, Deutsch DTF, JAE MM70, card-edge bus footprints. Each can go in as a line in `parts/`.
- Severity 2: cable bundles: cables that run together are laid parallel and spaced, but there is no zip-tie geometry or bundle in the shopping list.
- Severity 2: tight bends where short legs meet at corners (1 to 2 diameters). A bend penalty and slanted corners both made the Pi cluster much worse and were taken out.
- Severity 1: collisions left (`npm run collisions`, 144 racks): cable into cable where two cross in a street (Pi cluster 9 mm³), a debug ribbon brushing a jumper on the dual-MCU example (1.2 mm³), a stacked board's standoffs, the stacking pegs' crush ribs (by design).
- Severity 1: not reproduced, may be gone: the hub cable "runs into the USB charger holder" on the 12-board rack, jumpers 0.4 to 1.1 mm into their own adapter's holder or plugs.
- Severity 2: a second J-Link for one board needs a 250 mm ribbon (two J-Links stand 95 mm; the PETG tongue carries 84.5). The Debug panel says to buy 30 cm.
- Auto-arrange: rails about 14 % longer in the balanced goal (Compact reverses it); its quick cable model misses some clashes (the real-router check catches them); sharing a probe column between neighbouring boards; "easy to reach" for displays (no board data); the deep confirm (build both candidates) isn't reachable from the button; a board with a debug header may be turned so a probe column can't go behind it later.
- Dock: the spring clips don't flex in the assembly animation (they are part of the holder: flexing needs them as separate parts); the DIN plate's slots print as 14.4 mm bridges (printing the plate on its face needs a joint to the holder); fit a cap only where the pull comes out of the cradle's open side (needs the cable direction at holder time); the Pico's holder lying flat on its top edge has a 4.5 mm overhang.
- Layout lock: locked docks aren't marked in the Rails drawing.
- 3D: jumper wires and a USB-serial cable's loose ends have no flow (signal only).
- Community boards: the worked example shows next to the built-in "Example: sensor board", the same board; hide it once a real community board is in (the tests use it).
- Not checked since the second round (agents were on them before): the headline print time estimate, the L-shape spacing defaults, per-plate control, bulk tools for identical boards (Copy to… covers part of it), toast wording.

## 3. Found along the way

Each: how bad (1 to 5), what's wrong, where, and how it was seen.

- 2 · The DIN clip's shoe pull-off: with the slit roots rounded, PETG reaches 2 % strain at about 130 N centred and 87 N on one hook; the fixed hook's finger is now first, at the edge of the rigid support the model holds it by, so the reading may be the model's (`src/fea/dockfea.ts`, `docs/din-clip-review.md`).
- 1 · The Nano's 8 mm hairpin pair (docked, and lying flat) reads 0.85 fatigue margin in the FEA, a little under 1 (`src/fea/springfea.ts`).
- 2 · Nothing clips a USB-serial adapter (docked or flat), a round board of about 20 mm lying flat, or a board docked on an edge crowded with plugs: the Check step says so (`src/cad/grip.ts`, found by `tests/clipsauto.test.ts`).
- 2 · The rail grip (`railGrip`, `GRIP` in `src/cad/dockdims.ts`) is a pad under a permanent 0.35 mm preload, about 1.0 % at rest against the 0.2 % rule; it can't meet the rule and still hold the clip, so it isn't in the flexure table.
- 1 · Once-only press fits kept outside the flexure table: the stacking tower pegs' 0.15 mm crush ribs, and the stand socket's optional Press fit.
- 1 · The Nano's 8 mm hairpin is over the limit in PLA (fine in PETG).
- 2 · KiCad "New version": a 0.8 mm connector move on the example board caused an overlap; the warning shows, but why the imported bodies overlap was never found.
- 1 · `npm test` takes about 6 minutes, most of it building holders and racks.
- 1 · The printed guide's pictures have no cable numbers: the numbers are drawn over the 3D view, not in it (`src/ui/Viewer3D.tsx` stepPictures).
- 1 · `public/kiri/kiri-engine.js` needs `document` when it loads, so it can't run under plain Node without stubs.
- 1 · The clip FEA (`src/fea/clipfea.ts`) still reports raw corner peaks; the dock FEA averages 3 × 3 pixels.

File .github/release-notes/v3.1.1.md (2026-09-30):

## Install

Nothing here is code-signed yet, so your system will ask you to confirm the first time.

| | File | First time |
|---|---|---|
| **Windows** | `BoardDock-3.1.1-win-x64-setup.exe` (installer) or `BoardDock-3.1.1-win-x64-portable.exe` (no install) | Choose **More info → Run anyway**. |
| **macOS** (Apple Silicon) | `BoardDock-3.1.1-mac-arm64.dmg` (open it and drag BoardDock into Applications) | Right-click the app and choose **Open**. |
| **Linux** | `BoardDock-3.1.1-linux-x86_64.AppImage` (`chmod +x` it, then run it) or the `.deb` (`sudo apt install ./BoardDock-3.1.1-linux-amd64.deb`) | Nothing. |
| **In your browser** | [danmover.github.io/boarddock](https://danmover.github.io/boarddock) | Nothing is uploaded: it all runs in your browser. |

## What's changed

### Columns of small boards
- **The spring clips between two holders in a column are fine.** Every clip on column holders was measured against its neighbours across 37 column setups. The clips sit in the 6.8 mm gap between two holders, beside the landing, with 5.2 mm of room against the 0.85 mm they need to flex, and their slits print open.
- **No plug points up a column any more.** A board below the top with a plug on its far edge pointed it into the holder above. The plug and its cradle stood where that holder sits, so it sat 3 to 4 mm deep in the one below and its clips were buried. A column's base (a Pico, ESP32, Nano or Sensor board under another board) now stands on a long edge like the rest of its column, with its plugs to the side.
- **A board that can't avoid it is flagged.** A Pi Zero has all its plugs on one long edge, so below the top of a column one always points up. It gets a **Plug up the column** check, which says to put it at the top of its column.

### Documentation
- **The README is 111 lines instead of 722.** It covers what BoardDock is, what the first print showed, downloads, a quick start to a first print, and what it does. The reference moved, corrected, to [docs/](https://github.com/danmover/boarddock/tree/main/docs):
  - the guide to using the app;
  - how the printed parts work, with their checks and FEA;
  - printing;
  - supported files;
  - known limits;
  - development.

## Known limits

Nothing from 3.1 has been printed yet. The fixes from the first print (release button, socket latch, tongue stoppers, spring clips only) come from the model and its checks. See the [3.1.0 notes](https://github.com/danmover/boarddock/releases/tag/v3.1.0) and [docs/limits.md](https://github.com/danmover/boarddock/blob/main/docs/limits.md).

Full list of changes:

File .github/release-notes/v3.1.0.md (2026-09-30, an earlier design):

## Install

Nothing here is code-signed yet, so your system will ask you to confirm the first time.

| | File | First time |
|---|---|---|
| **Windows** | `BoardDock-3.1.0-win-x64-setup.exe` (installer) or `…-portable.exe` (no install) | Choose **More info → Run anyway**. |
| **macOS** | `BoardDock-3.1.0-mac-….dmg` (open it and drag BoardDock into Applications) | Right-click the app and choose **Open**. |
| **Linux** | `BoardDock-3.1.0-linux-x86_64.AppImage` (`chmod +x` it, then run it) or the `.deb` (`sudo apt install ./BoardDock-3.1.0-linux-….deb`) | Nothing. |
| **In your browser** | [danmover.github.io/boarddock](https://danmover.github.io/boarddock) | Nothing is uploaded: it all runs in your browser. |

The desktop app does two things the browser can't: it opens Cadence Allegro `.brd` boards (with KiCad 10 or newer installed, free from kicad.org), and **Open plate** hands a plate to a slicer you have installed.

This is the first release since v0.2.0 (a v3.0.0 was prepared and printed from, but never published), so everything below is new since v0.2.0: first the fixes from that first print, then everything else.

## From the first real print

The first printed rack showed what to fix. The DIN rail clip worked well and is unchanged. The rest:

### The dock
- **Release button**: its rod was too tight in its tunnel, so it had to be forced in and the button broke. The tunnel now has 0.8 mm of play round the rod, a lead-in funnel and chamfers, and the rod's neck under the button is solid and filleted. It clicks in with two barbed fingers under a gate at the top of the tunnel.
- **Socket latch**: a holder popped out too easily. The latch pulled out because its nose sits off the spring's axis, so a pull tipped it out (the model has it slipping at about 10 N). It is now a long tapered spring with a deeper hook undercut 15°, so a pull draws the hook in: a 20 N pull moves it 0.4 of its 1.4 mm, and it slips only at about 69 N. It is also easier to use: 3.9 N to push a holder in (was 11 N) and 2.5 N on the button (was 3.8 N), at 0.85 % strain (was 1.4 %).
- **Tongue stoppers**: the small leaves that stopped a holder rattling, and the latch's stop post, hung on thin joints and snapped. They are gone. Two crush ribs on the tongue flatten to fit the first time it goes in, and a new check makes every stop and catch join its part at least 1.2 mm wide, inside its own print layer.

### Boards are held by spring clips only
- **Snap pins are gone.** The split pins in the mounting holes broke straight away. Every board is now held by spring clips on its edges, sized for the board (leaf length, catch and push from its size and weight). Where plugs take most of the edges, a **fixed ledge** goes on one side: the board slides under it and the clips opposite click over it. A mounting hole gets at most a plain locating pin, which grips nothing.
- **Hairpin clips** (the leaf folds back on itself) wherever a stretch of edge is 10 mm or less.
- The **Hold the board with** setting (Auto / Clips / Pins / Both) is gone; projects that asked for pins get clips. **Clip strength** (Firm or Gentle) stays.
- Every board in the library gets clips, each under 1 % strain when pressed in and none loaded once the board is in. The Pi Zero, whose edges are nearly all plugs, gets two hairpins and a ledge.

### Every clip is a spring that doesn't wear out
Every part that flexes is now checked against one rule, for PETG: at most 1 % strain at full deflection and at most 0.2 % while resting, with the hold coming from the hook's shape, not from pressure. Parts that didn't meet it were redesigned:
- **Plug caps** stand on tapered legs with rounded roots (at most 0.9 %, down from 1.2 %).
- **Holder hooks** on the DIN plate are tapered beams, and the plate's clip has a long shallow jaw ramp, an even 0.8 mm leaf 17 mm long and a gusseted stop.
- **Cable tags** are an open saddle held on by a 2.5 mm zip tie (the ties are in the shopping list); the old snap ring had to stretch 8 to 30 % round a stiff cable.
- **Back-to-back holders** are joined by a rigid pin and a U clip that slides onto its neck (0.84 %; the old split rivet reached 15 %).
- **Rail end blocks** are a 0.3 mm slip fit: their crush ribs would have flattened the first time and left the rail loose.

### Also
- Generic Marlin and Klipper start code counts as known, so those printers get **Slice and download all G-code** as the main button.

## Also new since v0.2.0

### Connectors
- **Far more connectors are recognised on imported boards**, above all as Allegro libraries name them: IPC-7251 header names, a maker's name in front of the part number, part numbers with the dashes taken out, upper case, `_10P` pin counts. Checked against KiCad's whole connector library, 94 % of its footprints are identified (98 % leaving out bare solder pads), and none of its 5,600 other parts are taken for a connector. A chip or diode with only a connector-like word in its name (a diode package called SMA, a TRS3232, a USB4640) stays a chip.
- **New connector families**: board-to-board (Samtec, Hirose, Molex SlimStack), M.2, mini PCIe, PCIe and DIMM sockets (the holder keeps clear of the card in them), XLR, banana jacks, M12 and M8, TOSLINK, SIM slots, SATA, SFP cages, mini-DIN, IEC C14 inlets, MMCX, MCX and SMB, the 20-pin Cortex debug connector, and many more makers' terminal blocks, headers, USB, RJ45, D-sub and DC jacks. Each is wired as what it is (an SFP cage is a network port, a C14 inlet takes a kettle-type lead, TOSLINK goes only to TOSLINK).
- **Sizes checked against KiCad's library** (drawn from the makers' datasheets) for SATA, XLR, banana, BNC, SMA, TOSLINK, SIM, SFP, SO-DIMM, mini PCIe, the mezzanine bodies, the 3.5 mm jack and the right-angle box header.
- **Every connector is in the toolbox**, with its own picture, and drawn as itself in 3D: round SMA, XLR, M12 and mini-DIN barrels, a figure-8 mains socket, pin sockets with visible holes, blue relays.

### Adding boards and parts yourself
- **`boards/`**: put a board's files (KiCad, Eagle, ODB++, IPC-2581, Gerber…) in `boards/<name>/` with a small `board.json`, run `npm run boards`, and it shows in the app's library as a community board. The report says which connectors it couldn't identify.
- **`parts/`**: teach BoardDock a connector's part numbers with one line of JSON, or add a new part type (size, plug, what it connects to, and a look made of simple shapes). It appears in the toolbox under Contributed.
- Both come with step-by-step instructions an AI can follow (`boards/AGENTS.md`, `parts/AGENTS.md`), a check on every pull request, and an optional Claude job that does the work when a `boards` or `parts` label is added (it needs the repository's `ANTHROPIC_API_KEY` secret).

### J-Links and USB-serial adapters
- **J-Links and adapters are ordinary boards**, docked and cabled like any board. Small boards stack in columns on their long edge, one release rod down the whole column.
- **One press adds what's missing**: "Add 3 J-Links + 2 adapters" gives each debug header a J-Link with the right connector (10-pin, 20-pin Cortex or JTAG box) and each UART header an adapter, docked beside their board.
- **Debug and serial panel** on Plugs: every header, its probe, ribbon length (one click to fix a short one), dock slot and pin 1. A printable **bench sheet** has it all on one page.
- A female header used for UART gets male-ended jumpers (drawn and bought that way); guessed UART pin names say to check yours.
- The column holders' pegs and holes now print without supports.

### Wiring and power
- **PoE**: a PoE switch, and a "PoE HAT fitted" option; a board on a PoE port needs no supply, within the switch's budget.
- **Arduino DC jacks** only take a pack in their range (7 to 12 V); Auto-connect picks the one nearest 9 V, and the advice offers a 9 V pack when none fits.
- **"Add a USB hub"** is sized to what needs plugging in, and says what goes to your computer.
- **Cables to buy** use the same wording and lengths everywhere, with an option to buy every Ethernet lead at one length. Each cable Auto-connect made says why.
- Plug packs no longer get a printed holder in the loose layout.

### Auto-arrange and cable routing
- **Auto-arrange plans for the cables**: it tries layouts, scores each on cable length, crossings, cables under rails, blocked plugs and rail used, and checks the best with the real router. On 13 test racks: 23 % less cable, the longest cable 24 % shorter, crossings from 87 to 18 (rails are about a third longer on the balanced goal; the Compact goal turns that round).
- **Auto-arrange options**: probes beside their board and stacked, a goal (balanced, compact, short cables, easy to reach), like boards grouped, mains at one end, hosts near devices, room to grow, back-to-back pairing, stock cable lengths, hot boards apart, fewest printed parts. **Pack new boards only** leaves the rest of the rack where it is.
- **Smarter routing**: crossings under the rails spread out and pinned, cables kept off each other, rails, stands and plugs, combs wherever cables cross a stand, tags on clear spots. On the 144 test racks the collision check went from 458 to about 35 mm³.
- **Debug ribbons and jumpers never block taking a holder off**: over another board's dock they rise clear of its lift-off and release lever, or go round the end.
- **Plug packs on the rack's powerboard** have their lead drawn from the outlet and checked against its length.
- **Cables: off**, for when you only want holders and plug covers: no cables, combs or cable shopping, and a simple port list for cradles and caps. Your cables come back when you switch it on.

### Layout
- **Cluster preset** on Start: a Pi 4 or Pi 5 cluster with switch, powerboard and supplies (or PoE) in one go.
- **Complete this rack**: supplies, outlets, a switch and an uplink, in one undo step.
- **Layout lock**: lock the layout, a rail or a dock; automatic changes leave it alone, and each writes a receipt you can undo.
- **Copy to…**: copy a board's holder options and port settings to other boards.
- Back-to-back pairing works by touch; dock labels say how each dock stands.

### The 3D view
- **Cables are translucent**, coloured by kind (colour-blind safe, with a key), with a bright rim and core; the one you pick stands out.
- **Power runs through them**: glowing streaks move from each supply to its board, now on PoE, mains and leads that leave the rack too, and boards on PoE or a plug pack light up.
- **Isolate and X-ray** the selection, **What's new** tinted in 3D, **mains zones** shaded (and a Check line when mains sits close to a low-voltage board), a typed **rotation** box with 15°, 45° and 90° snaps.
- **Command palette** (Ctrl/Cmd+K, or the search button on a phone).
- Labels group per holder, stay on top, and show only for real leads; the camera frames the whole row.

### The dock
- **Stronger rail shoe**: rounded roots at the hook slits take the pull-off from 119 to 130 N centred (80 to 87 N on one hook), and the release lever stops at 6.5° instead of 13.5°.

### Printing and export
- **Slice and download all G-code** from the main button once your start code is known; Download everything can include it.
- Start code you paste for any printer is checked (bed size, moves off the bed, temperatures, other printers' commands) before it's used.
- Parts on a plate are always far enough apart for two brims; the print settings describe the skirt the slicer lays.
- The thin-gap print check catches gaps by width, so a 0.09 mm print-in-place gap is flagged.
- A **buy, print and tools checklist** you tick as you go, saved in the project.

### Also
- Several files imported at once stay on Start with a Check the boards button; adding to a built rack says where each board went; Steps can play **only what's new**.
- Check items say "OK to print" or "worth a look", with a fix button where there is one.
- A layout you've built before comes back instantly, and a slow build shows what it's working on.

## Known limits

- **Nothing from this release has been printed yet.** The fixes above come from the model and its checks; the first reprint will tell.
- Nothing can clip a USB-serial adapter (docked or flat), a round board of about 20 mm lying flat, or a board docked on an edge crowded with plugs: the Check step says **Nothing clips this board in**.
- The Nano's 8 mm hairpin is over the limit in PLA; print it in PETG.
- The rail grip in the shoe rests under a small permanent preload (about 1 % strain), more than the resting rule allows. It is what holds the shoe on the rail, and the rail clip worked in the first print.
- A second J-Link for one board needs a ribbon of about 250 mm (a 30 cm ribbon; the Debug panel says so).
- Some connector sizes are still typical ones, with no public datasheet drawing to check them against.
- Big racks are slow to build the first time.
- Two boards that mate on a board-to-board connector aren't treated as one stack: put them in a stack by hand.
- Allegro `.brd` import was tested with a stand-in for KiCad's tool, not yet with a real Allegro board.

Full list of changes:

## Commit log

2026-09-25 BoardDock 0.1.0: screwless PCB holders docked on DIN rails
    Import a board (KiCad, STEP, IDF, Eagle, Gerber + drill + PnP, DXF, or draw
    it), fit a holder around it (standoffs, snap pins and fingers, plug cradles
    with caps, underside clearance), and dock it onto DIN rails.
    - Rail dock from the din_hub_v2 design: rail shoe with thumb-lever release,
    socket that turns 4 ways with two print-in-place latches, tongue + spine +
    release rod with a push button on the holder's top edge.
    - Panel: any number of horizontal or vertical rails, docks and flat clips,
    auto-arranged for plug access (orientation search, back-to-back pairing,
    packing with real 3D extents, new rows), then editable by drag,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
2026-09-25 C-jaw rail shoe, printability check, clean-up tools, new look
    Rail shoe v3 ("C-jaw"): the jaw wraps round the flange edge and hangs from
    a uniform 0.9 mm hinge leaf directly above the lip, so a pull off the wall
    runs down the leaf instead of prying the jaw open. 2D FEA (PETG): holds to
    about 90-120 N whatever the friction (the old jaw let go at ~14 N without
    it), lever 2.7 N with a stop at 2.1 mm, 5% less filament. The lever pad is
    ridged and goes on the side of the rail with more room (flip per dock).
    - Printability: every part is checked for overhangs and bridge spans;
    the print view can paint them (red: needs support, amber: bridge).
    - Clean-up: whole-holder switches for cradles, caps,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
2026-09-26 Press-down rail lever, table stands with cable combs, cables and wiring view, detailed boards
    - Rail shoe v5: a print-in-place lever on a pin beside the socket replaces the pinch ear
    (about 1.4 N, 8 mm pad travel; the stop and pull-off design are unchanged).
    - Table stands: sleepers across the rails at both ends and at least every 200 mm between,
    made of end blocks the rail pushes into, saddles, and dovetailed spacers. Every piece is
    a profile printed on its end. Spacers carry snap-in cable combs where cable streets cross.
    Checks for rail sag and cap stress (hand calculations).
    - Cables: plug roles, Auto-connect, a Wiring view, and Cable to in the Plugs step. Routes
    run through str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
2026-09-26 Step-by-step assembly, collision-checked cables, configurable hubs, returning to a built rack, print settings
    - Assembly animation in real-life order with an instruction per step (saddles, rails, end blocks,
    spacers, shoes, sockets; per board: release rod, board into holder, stack, into the dock; cables,
    caps), stepped with back/next. Loose holders get the same.
    - Cable routes checked against every holder, board, plug, dock, rail and stand box; each end tries
    several ways out and the clearest short route wins; clashes are marked and reported. Lanes ordered
    to cross least; stacked USB-A pairs count as two ports.
    - Boxes (hubs, chargers) from a size and rows of ports on any face, top i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
2026-09-26 In-app G-code with Kiri:Moto, fixes from review, phone layout and polish
    - Slice plates inside BoardDock with Kiri:Moto (MIT), built from source by vendor/kiri/build.mjs into
    public/kiri (FDM only, WebAssembly and worker pool on). Start/end code from Kiri's own printer
    profiles where it has one (stripped of stored printer credentials, PLA temperatures made macros),
    a plain Marlin/Klipper start otherwise, editable per project. Bambu printers get a .gcode.3mf.
    Layer preview, time, grams. Thin-wall detection off: faster and keeps the springs two lines.
    - Review fixes: empty-slot placement respects rail ends; full-mesh part signatures; stable hub
    port names; free mounts pinned to the c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
2026-09-26 Stronger dock tongue (14 x 4.5 mm) and snap pins sized for short posts
    - Tongue grows from 12 x 4 to 14 x 4.5 mm inside the same socket outline: the cavity, the latch
    groove and the latch nose move with it, so latch travel and forces stay as they were (dock FEA:
    push-in 9.2 N, release 3.2 N, 1.57% / 1.16% peak strain). Tongue-root stress on a Pi 4 holder
    falls from 38 to 25 MPa (PETG). Tongue size lives in dockdims (TONGUE, NOSE_TIP) for the socket,
    the holder, the FEA and the check.
    - Split pins in short posts get a wider split (legs at least 0.6 mm) until they bend within the
    material's limit; the barb is trimmed only if a pin would still break. Uno R3: 2.08% -> 1.33%.
    - Test: th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
2026-09-26 Sliced printability check, holder features that say what they did, cable numbers and tags, add a board from anywhere, 3D pictures
    - Printability: every part sliced into 0.2 mm layers in its print pose (side worker, cached per shape):
    nothing in mid-air (so no supports), bridges and overhangs measured, walls under a line and slots
    under 0.3 mm found. Fixes it led to: the socket's latch nose now has 0.45 mm round it in its window
    (0.2 mm could weld it), and snap fingers float over a 2 mm slot so a drooping first layer can't
    weld them. Tested on every part of a mixed rack, the loose DIN clip and the test-fit kit.
    - Holder features: one row per feature with what the holder got. The engra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
2026-09-27 Stand feet at full length, tie anchors on the wall, tipping check, faster start and slicing
    - Fix: table stand feet (outriggers) printed as dovetail stubs: the foot's rounding radius erased the bar
    - Fix: a cable-tie anchor beside a receptacle that overhangs the board edge floated clear of the rim and was
    dropped; it now sits on the holder wall beside the opening (test: no template or imported board loses a piece)
    - Tipping check: holders and boards taller than 1.5x the stands' narrow side (a rule of thumb), with ways to steady it
    - Hole wizard: an edge-held board says how many snap fingers hold it, and what to change when nothing does
    - Template tiles ship as pictures (scripts/render-tile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
2026-09-27 Release 0.1.1: one draft release, distinct Windows file names, publish when every installer is up
    v0.1.0's release build failed on Windows: the installer (nsis) and the portable app were both named
    BoardDock-0.1.0-win-x64.exe, so their uploads overwrote each other and one timed out; and the three build jobs
    each created their own draft release. Now a first job creates the draft, the builds upload to it (retrying a
    timed-out upload), the Windows files are "-setup.exe" and "-portable.exe", and a last job publishes the release.
2026-09-27 New version of a board replaces the old one in one step; plugs drawn after their type, cables that hang and bend like real ones
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2026-09-27 Ribbons lie flat and go the short way round; J-Link socket on its face; serial pins from nets
    - J-Link: 10-pin socket on its top face by one edge, micro-USB on the edge opposite;
    it slides into its slot USB end up
    - Ribbons leave each socket flat, lie along the board, and loop over the top or go
    round the end of the dock (whichever is shorter and clear), nesting instead of crossing,
    landing square on both sockets
    - A probe stack slides along its dock to line up with its board's headers; docks with
    probes get room at one end for the ribbons
    - UART headers: pins and nets read from KiCad pads; GND/RX/TX from the nets, a guess from
    the header size, or set by hand; serial cable drawn wi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
    [dual-mcu-swd.kicad_pcb, sensor-jtag.kicad_pcb]
2026-09-27 USB-serial adapter board with jumper wires pin to pin; rail slot chips no longer clipped
    - FT232RL adapter preset (mini-USB, six right-angle pins with their names); it slides
    into a slot on top of its board's probe stack
    - Jumper links: wires pin to pin, filled in with the crossover (GND-GND, TXD-RX, RXD-TX)
    from pin names and nets; drawn as separate wires with a housing on each pin, bundled
    round the dock; bought by the wire in standard lengths; wiring in the assembly step
    - Auto-connect pairs a loose adapter with a free UART header
    - Bare boards (probes, adapters) have their ports standing on top; slot lips notched
    over parts at the edge
    - Rail view: the board chips in a dock's fro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
2026-09-27 Wiring view: a canvas to pan and zoom at the pointer, draggable cards, arrange by flow, pin-by-pin jumper wires
    - Pinch or cmd+scroll zooms where the pointer is (it zoomed from the corner before);
    scrolling or dragging the background pans; fit button
    - Cards drag by their title and stay put (saved with the rack, undoable)
    - Arrange: as the cables flow (sources, hubs, probes and adapters, boards; ordered to
    cross least) or as on the rails
    - Pin headers open into their pins with net names; pin then pin adds a jumper wire
    (ground black, supply red); a wire can be selected and deleted on its own
    - Hover details on cards, plugs and pins; the toolbar no longer covers the view tabs
    Co-Author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
2026-09-27 Board editor: parts toolbox, caliper dimensions, hover details; My boards; draw your own probe or adapter
    - Toolbox of plugs (snap to the nearest edge), headers, JST, debug connectors, UART header,
    screw holes and tall parts; click to place, Shift keeps placing
    - Measure: a dimension between edges, holes, part centres or sides; typing the measured
    value moves the part (two edges set the board's size); dimensions stay on the board
    - Hover card for parts and holes; pins with pin 1 square; KiCad copper drawn faintly;
    connector type or height under the ref when zoomed in
    - A board can be marked as a debug probe or USB-serial adapter, and is then treated like
    the built-in ones (slot behin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
2026-09-27 Adding a J-Link or adapter to a built rack: into its board's free dock slot, add-on prints only
    - New probes and adapters on a laid-out or built rack go into the free slot of their
    board's dock (else the nearest free slot on that rail, else a new dock at the end);
    before, they always got a new dock at the end of the rail and their ribbons fell short
    - A probe slides along its dock only as far as the board's holder reaches, so a built
    dock does not grow
    - Ribbon room at a dock's end counts between docks, not against the rail's length
    - Rail end checks tolerate float rounding of stored positions
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2026-09-27 Cables from a plug facing the next dock bend off to the side; My boards on the Start page
    - A sideways plug can go out a little, step off to either side and drop, so a hub's port
    facing the next dock no longer routes its cable through that dock's holder
    - My boards listed on the Start page too
2026-09-27 Board editor rehaul: docked toolbox with 3D pictures, Start page and library, drawn copper, draggable dimensions
    - Start: three ways in (files, draw your own, open a rack) and a library of every board and
    accessory on shelves with pictures, multi-pick; a clickable progress checklist for a rack
    - Board editor: docked toolbox (pictures of every part), snapping with guides and edge gaps,
    photo underlay (scale, align), part shadows, chip legs, tinned passives, pin nets, silkscreen
    - Copper: plausible tracks and vias for boards without their own (model/copper), in 2D and 3D,
    in the board's colour; a Tracks toggle
    - Dimensions lay themselves out without overlapping; labels drag (line and alo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
2026-09-27 Boards can lie flat on their docks, top face up, on the same shoe and socket
    - A flat holder has an ear on one edge: the standing holder's pedestal and tongue under its
    tip, the release button on top on a short rod, clear of the board
    - Two flat boards back to back in one socket; a J-Link can stand behind a flat board
    - Planner: flat frame, ear site clear of plugs, flat scoring (reach, rail taken, plug access);
    Rails setting Stand up / Lie flat / Whichever suits each, and a per-slot toggle
    - Tongue stress check for a press on the far side; tests for the frame, ear, access and a
    whole rack laid flat
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2026-09-28 Cables settle together: none passes through another, a holder or a ribbon
    - src/cad/cablesim.ts: each cable a chain of beads; crossing cables lie one over the other,
    parallel ones side by side, beads pushed out of holders, docks and plugs, length kept,
    bends eased, ends held straight in their plugs; ribbons fixed, the rest settle round them
    - The panel generator plans every route, then settles them all before building the meshes;
    Check reports where the planned routes met and any pair still pressing
    - Tests: crossing, side by side, pushed out of a box, fixed ribbon, length, a busy rack
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2026-09-28 Wiring overhaul: smarter Auto-connect, drag to connect, best matches, a to-do list
    - Auto-connect measures cables on the laid-out rack (plug positions in the report), pairs each
    kind all at once (Hungarian assignment), keeps power within each port and charger and spreads
    it (local moves and swaps), connects Ethernet to a network switch, says why for each cable;
    Rewire redoes its own cables and keeps yours
    - Network switches (5 and 8 ports) in the library; advice names what the rack is short of,
    with one click to add it and connect
    - Wiring view: drag from a plug to a plug or a card, drag a connected plug to move that end,
    a picked plug's best matches, Connect N more like this, a Li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
2026-09-28 Boxes you can make match your own: ports placed, spaced, raised and turned; build a box from scratch
    - Each row of ports on a box can be centred (as before), measured from either end of its face, or have
    each port where you put it; its own spacing; its height up the side; and which way up the socket is
    (flat, upside down, or on its side either way). Top rows go so many mm from the front and turn by any
    angle.
    - Box corners: square, rounded (up to fully round ends) or cut off; its colour.
    - Upright and flipped sockets flow through: port size along the face, plug size as it sits, the holder's
    opening, the plug and the box's own 3D picture turn with them (ConnSetup.roll).
    - The board ed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
2026-09-28 Shape tool for oddly shaped boards: corners, lines, arcs, fillets, add and cut shapes
    - Board editor: Shape (S) edits the outline and cut-outs. Edit mode drags corners
    and edges, shows an edge's length on hover, adds a corner from the + in the
    middle of an edge, types a corner's X/Y or an edge's length, bends an edge into
    an arc, rounds or cuts one corner or all of them, and deletes corners. Line mode
    draws a shape corner by corner (Shift: 15-degree steps, typed length and angle,
    three-point arcs) and adds it, cuts it out or makes it the new outline. Shapes
    mode clicks in or drags out a rectangle, circle or slot to add or cut out.
    - Everything snaps (grid, other corners' x and y,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
2026-09-28 Power: never from a port too weak, no back-power loop, plug packs, your computer, mains budget, shared cable list
    Auto-connect only powers a board from a port that gives it enough, never through the hub it hosts, and sends
    leftover USB devices and hub uplinks to 'Your computer'. Adds USB-C and DC plug packs, a Pi 5 5 A need, a mains
    load per powerboard and one shared cable-list helper.
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2026-09-28 Rails: tongue-aware docking, drops that find a gap, Tidy up, Stacks with sensible targets, dock-mode comparison; What's new as a checklist; Replace with; revision overlaps reported
2026-09-28 3D view keeps its shaders between edits: shared materials, compile ahead, free the old scene after the new one is drawn
    Every edit used to dispose all materials before making new ones, so three.js
    compiled every shader program again (seconds of frozen window). Materials are
    now pooled by what makes them differ, the renderer and post chain outlive the
    view, a new scene's missing shaders are compiled before the swap, and the
    header says Rendering... meanwhile.
2026-09-28 Box editor sets a port's amps and volts, a plug pack's lead and a powerboard's rating; README for power
    Preset switches clear the old box's supply, pack and rating. The Plugs step says when free charger ports are
    too weak for the boards left.
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2026-09-28 Check: failing first, tiles filter the list, reminders folded away with Done, one count everywhere
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2026-09-28 Plain words: DIN rail named as such next to TS35, access chips explained where they appear, a short add-boards toast
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2026-09-28 Loose holders and leads: no DIN clip by default, boxes beside a stack, bolted-stack hardware from the shared holes, short tails for unconnected plugs, supply leads run off along the table, badges lea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
    - Loose layout starts with the DIN clip off (unless picked by hand); no rail or hacksaw wording without rails
    - A loose stack never covers a box: hubs, chargers and powerboards stand beside it
    - Standoffs and screws counted from the holes the two boards share, sized from them
    - Cradled ports with nothing connected (a headless Pi's HDMI) get a short cut-off tail; Go headless drops those cradles
    - A box's own supply lead runs along the table past the rack
    - Loose holders say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
2026-09-28 Live 3D: LEDs that glow and blink (dark without power), pulses along cables; cables that hang, bend and settle like real ones
    - Lights: every board's LEDs (its own LED parts, or the real board's for templates), jack link and activity
    lights, box status lights; power on steady, activity flickers, the Arduino L blinks, the Pi ACT beats, relays
    click through, RGB runs the rainbow. Boards with no power cable stay dark. A Live switch in the 3D view; the
    board editor's tracks view lights them too.
    - Parts: SMD and through-hole LEDs, tactile switches, crystals, part numbers on chips; slotted metal DIN rail;
    printed parts show their layer lines.
    - Cables: weight (a free span sags, never belo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
2026-09-28 Layer check measures what a printer sees: reach along the layer, real spans, bridges by where they are held, sloped roofs, specks, tiny feet
    The checker no longer caps reach at 30 mm, grows support inside the layer (so a
    finger over a slot reads its length, not the slot's width), calls a region a
    bridge only when it is held from roughly opposite sides, reports physical spans
    (the grown allowance added back), follows roofs that step out a little every
    layer, downgrades flecks thinner than a line to specks, fails a tall part on a
    tiny foot, and warns on bridges over 12 mm / fails over 25 mm. The finger mask
    is gone.
2026-09-28 Spring clips hold the board: tapered leaves standing up from the bed, a lip that clears the board, anti-rattle springs, and a Hold the board with choice
    Replaces the wall snap fingers (8-14 mm one-sided cantilevers printed over a
    slot). Each clip is a full-height leaf rooted along its whole height and cut
    free by 0.6 mm slits, so it bends within the layers and only its ~1 mm lip
    ledge overhangs. Leaves taper for even strain and are sized for a set press-in
    feel (firm / gentle) within 55% of the material's limit worst case; once the
    board is in the lip clears it by a layer and the leaf stands 0.1 mm off its
    edge, so the clip carries nothing. Thin 45 degree-faced springs take up
    rattle at ~0.1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
2026-09-28 Board check: what would spoil a drawn board's holder (holes off the board, too near the edge, under a part or twice; plugs set back from the edge or facing in; parts off the board or on top of each o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
    Fixes never move a real board's holes: a hole in the wrong place is left out. A board with no holes is held by
    its clips; one you are making yourself can have M3 corner holes added.
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2026-09-28 README: live lights, cables with weight and stiffness, off-rack leads, the board check, measuring hole patterns
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2026-09-28 Printable fixes: gabled guard collars, gabled square and hex stand sockets, tray windows open over wide parts, probe lips with 45 degree undersides, no frame sill; the DIN plate says its slots are br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
2026-09-28 3D view: change a board's mounting where you picked it (stand or lie flat, the edge in the dock, turn, swap; a loose holder's DIN clip)
2026-09-28 README: how the board is held (spring clips, anti-rattle springs, Hold the board with), and the printability claims corrected to the measured numbers; stacks leave room for the clips
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2026-09-28 Allegro boards: the desktop app reads them through the user's own KiCad 10 (kicad-cli pcb import), loose or in a zip; the web app says how
    Tested with a stand-in converter and a stand-in kicad-cli; no real Allegro board to hand.
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2026-09-28 First users' leftovers: no rebuild for a rename, Wiring card moves or marking built; Replace with in the 3D panel; the current step named on phones; loose holders start side by side; a box's DC input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
2026-09-28 Loose holders: the 3D row sets the picked holder's own clip (on or off, tab up or down); what they all share (one rail's direction) is labelled as such
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2026-09-28 Tongue over its limit: the automatic dock choice rules out any way of docking that fails Check's tongue line when another holds it (a board that can't stand on any edge lies flat instead); the fix bu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
2026-09-28 Last of the 3D collisions: strap loops off a box's plugs, crossing cables that stay crossed where they were laid, and rails that slide across for a board laid flat
    - Strap loops: the 12 mm strap keeps 1 mm off every plug on the sides it runs down and on top (it used to cross plugs on the USB-C hub, the 4-port hub, both switches and the A+C charger); a loop whose ends reach under a plug is made lower to pass under it; round the short sides when the long ones are busy; a zip tie between the plugs when no gap takes a strap (no stock box needs it). Measured: no loop or strap inside a plug on any stock box (the USB-C hub's loops were 70 mm³ into a plug).
    - Cables settling: two cables lying along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
2026-09-28 A whole-rack collision test: 140 racks through the real generator, every part intersected exactly, held against a committed baseline
    - tests/collide/: racks with seeded ids (every template alone standing, lying flat, loose and on a DIN flat clip; back to back; stacks; probes and adapters; boxes; no stands; rails along, rows, lying flat, whichever suits each; an L of rails; an L-shaped board; a Pi cluster and a busy mixed rack with Auto-connect; a rack changed by hand; a built rack with boards added). Every printed part, board, plug, rail, stand and cable becomes a manifold solid in the rack's frame; each pair that meets is intersected and sorted by what met what, with volume and depth (the t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
2026-09-28 Bolted stacks: standoffs long enough to clear the parts under the top board, and Check fails when yours are too short
    A Pi 4 bolted onto a Pi 4 sat on 11 mm standoffs while the lower Pi's USB and Ethernet jacks stand 16 mm tall, so they went through the top board, with nothing said.
    - stackNeed (src/model/holes.ts): the tallest part of the board below under the top board's outline (a plug in a jack counts as far and as high as the plug reaches), plus the parts and leads on the top board's underside, plus 1 mm.
    - stackGap: your own length if you set one, else the shortest standard standoff that clears that, never under a HAT's 11 mm. A HAT on a Pi keeps 11 mm; a Pi 4 on a Pi 4 gets 20 mm. Use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
2026-09-30 BoardDock 3.1.0 (#2)
    Everything since v0.2.0: the v3.0.0 work (never published) and the v3.1.0 fixes from the first real print. Notes: .github/release-notes/v3.0.0.md and v3.1.0.md.
    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
    [connector-names.tsv, sensor-jtag.kicad_pcb]
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
